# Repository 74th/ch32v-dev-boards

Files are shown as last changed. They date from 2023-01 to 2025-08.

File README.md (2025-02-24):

# CH32V Development Board

- [74th. CH32V203C8T6 ProMicro](./ch32v203-promicro/)
- [74th. CH32V003F6P6 ProMicro](./ch32v003-promicro/)
- [74th. CH32X035G8U6 ProMicro for USB PD](./ch32x035-promicro-usb-pd/)
- [74th. CH32X035G8U6 ProMicro for USB Device](./ch32x035-promicro-usb-device/)
- [74th. CH32V00xJxM6 SOIC-8 Dev Board](./ch32v00x-soic8/)
- [74th. CH32V006K8U6 Full Dev Board](./ch32v006-full/)

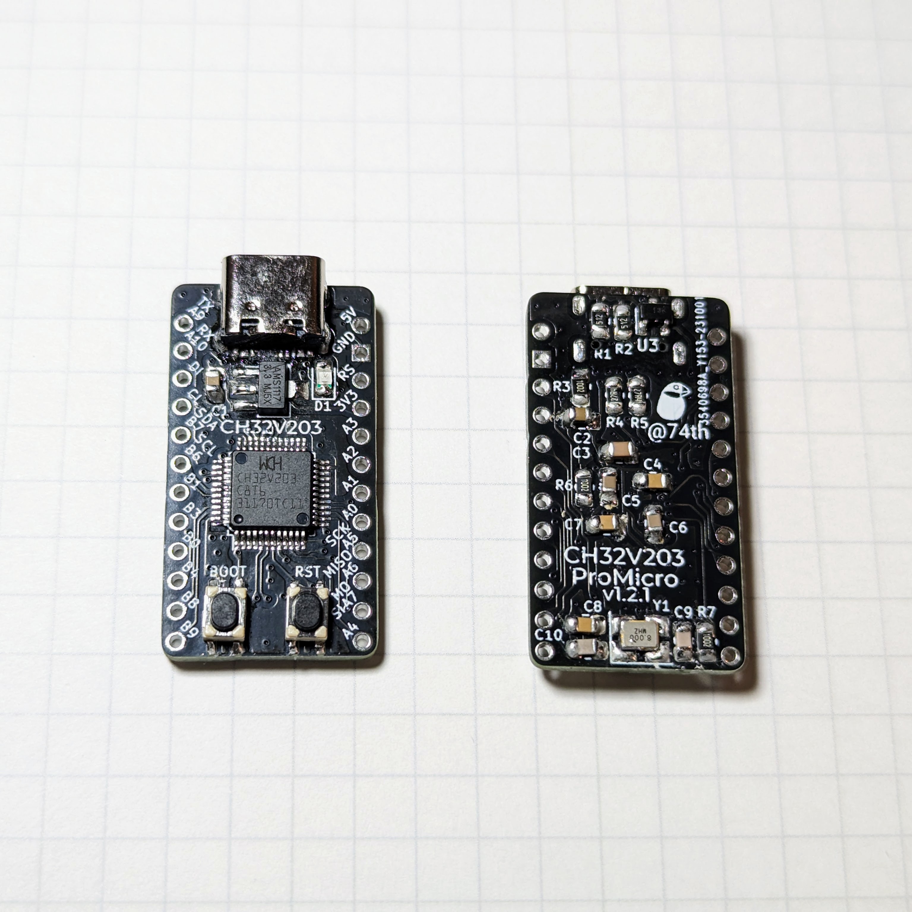
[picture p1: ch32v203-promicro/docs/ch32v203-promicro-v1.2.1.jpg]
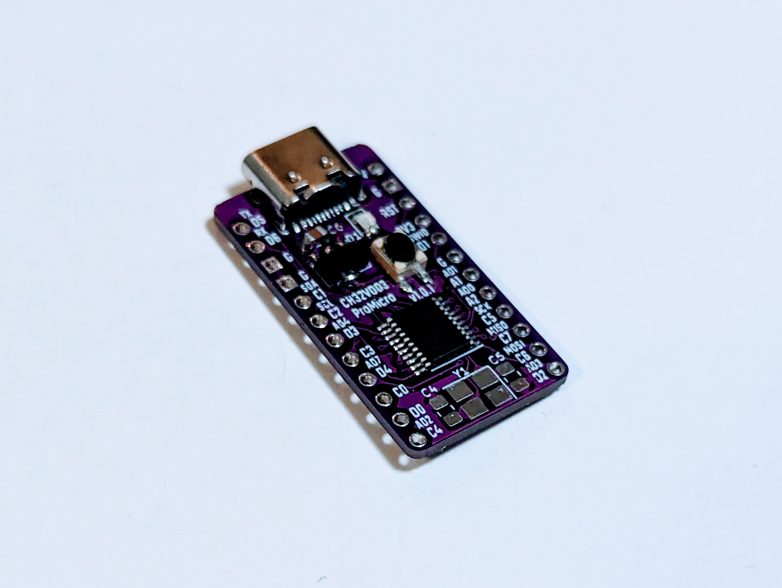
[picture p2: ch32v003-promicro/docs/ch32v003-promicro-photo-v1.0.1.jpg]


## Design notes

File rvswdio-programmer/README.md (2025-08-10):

# RVSWDIO Programmer

- Semantics [kicanvas](https://kicanvas.org/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)
- PCB [kicanvas](https://kicanvas.org/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)

firmware

https://github.com/cnlohr/rv003usb/tree/master/rvswdio_programmer

The on/off levels of the power switch pin need to be swapped.

```h
#define POWER_ON 0
#define POWER_OFF 1
```

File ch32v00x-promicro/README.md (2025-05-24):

# WCH CH32V00x ProMicro-Sized Development Board

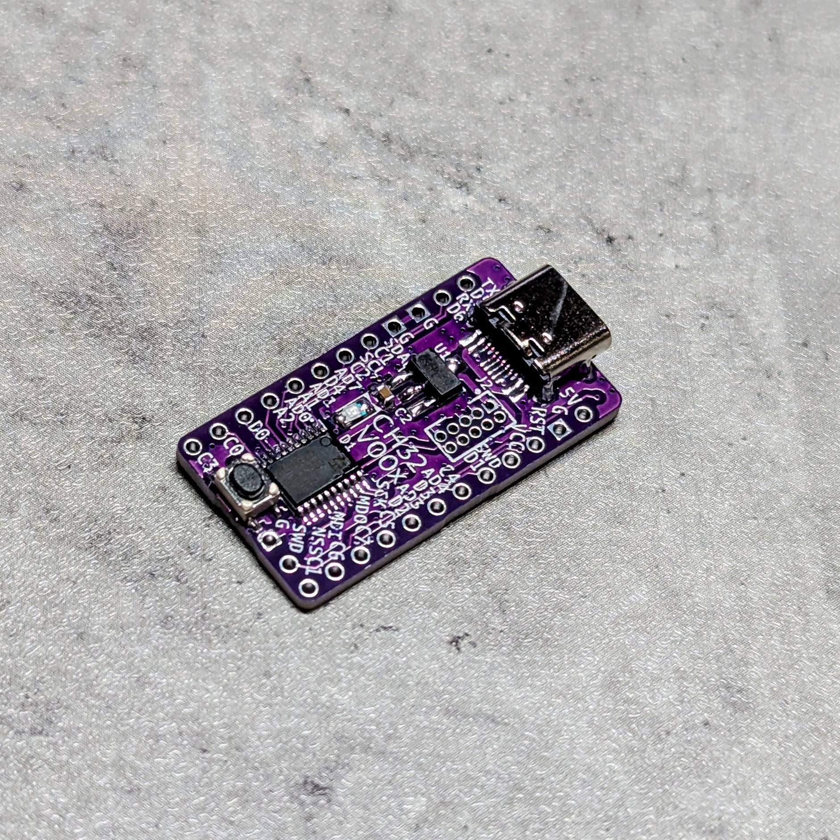
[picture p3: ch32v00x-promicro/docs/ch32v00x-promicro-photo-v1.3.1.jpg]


I forked the CH32V003 ProMicro v1.3.0 to simplify it by removing the USB wiring.

🇯🇵

CH32V003 ProMicro v1.3.0から、USBへの配線を取り除いてシンプルにするために、forkしました。

## features

- ProMicro size
  - To replicate the ProMicro, the CH32V003 lacks sufficient GPIOs, so PC1 is connected to both pin 5 (2/SDA) and pin 13 (10/A10).
- The MCU's VCC is set to 3.3V, but can be switched to 5V by connecting JP1 and removing the U2 3.3V regulator.
- The oscillator used is the MCU's built-in oscillator.

🇯🇵

- ProMicroサイズ
  - ProMicro を再現するには、CH32V003 は GPIO の数が足りないため、PC1が 5ピン（2/SDA）と13ピン（10/A10）に接続されています。
- MCU の VCC は 3.3V になっていますが、JP1 を接続し、U2 3.3V レギュレータを外すことで、5V にすることができます。
- 発振器にはMCU内蔵発振器を使います

## CH32V00x ProMicro v1.3.1

### Changes

- Added SWIO and GND ports for WCH-LinkE connection
- Remove USB Data lines

🇯🇵

- WCH-LinkE接続用にSWIO、GNDポートを追加
- USB データラインを削除

### DataSheet

- Semantics [PDF](docs/ch32v00x-promicro-semantics-v1.3.1.pdf) [kicanvas](https://kicanvas.org/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)
- PCB [kicanvas](https://kicanvas.org/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)

### Pin Out

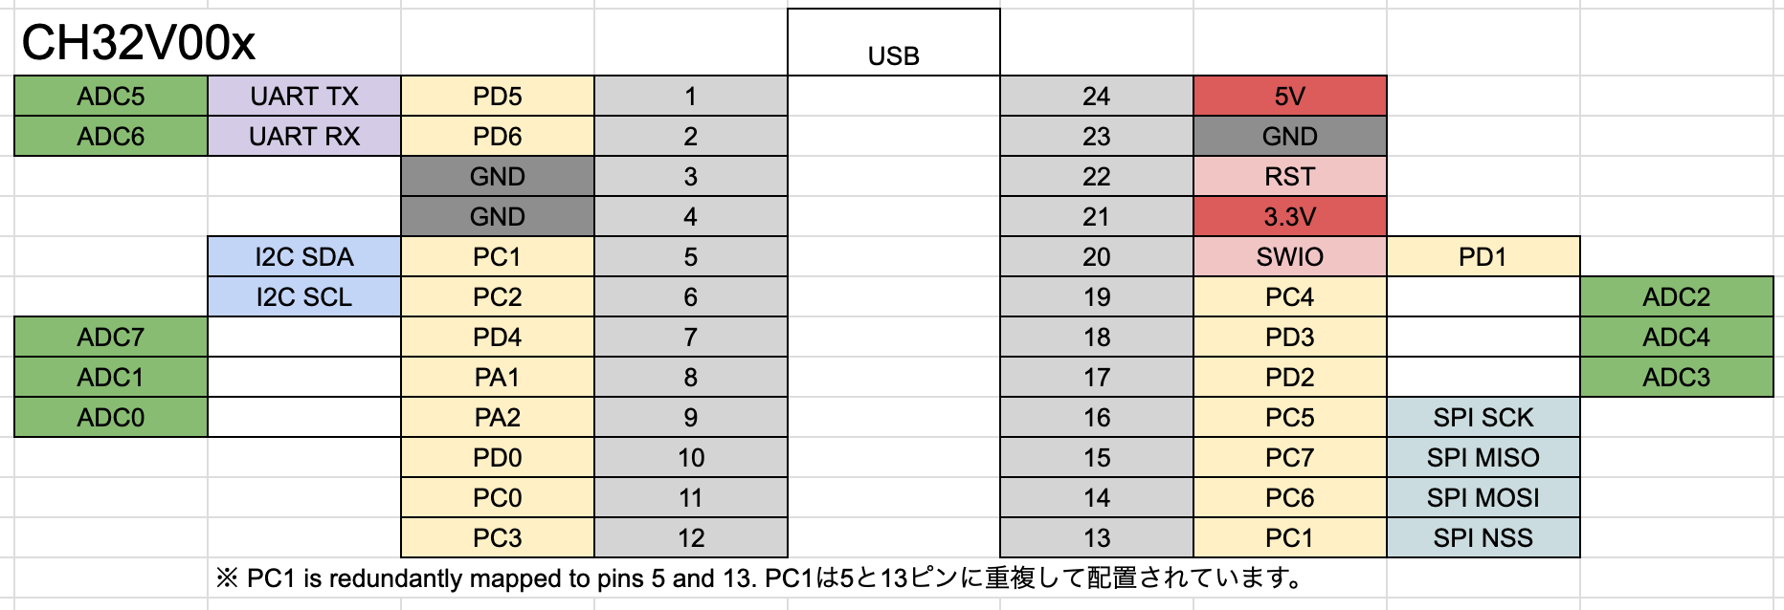
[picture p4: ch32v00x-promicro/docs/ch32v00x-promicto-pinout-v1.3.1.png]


### BOM

| Reference | Name | Quantity |
| --- | --- | --- |
| C1, C2 | Capacitor 0805 10uF | 2 |
| C4 | Capacitor 0805 100nF | 1 |
| D1 | LED 0805 Blue | 1 |
| J1 | USB Type-C Receptacle | 1 |
| J2 | Pin Header 2x5 Pitch 1.27mm | 1 |
| JP1 | Jumper SolderJumper_2_Open | 1 |
| R3, R4 | Register 0805 5.1kΩ | 2 |
| 10 | Register 0805 10kΩ | 1 |
| SW1 | Button SKRPABE010 | 1 |
| U1 | Regulator 3.3V SOT-89 AMS1117-3.3 | 1 |
| U2 | MCU TSSOP20 WCH CH32V003F4P6 | 1 |
| U3 | USB Power Protection IC CH213 SOT-23 | 1 |

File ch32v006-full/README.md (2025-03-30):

# CH32V006-full Dev Board

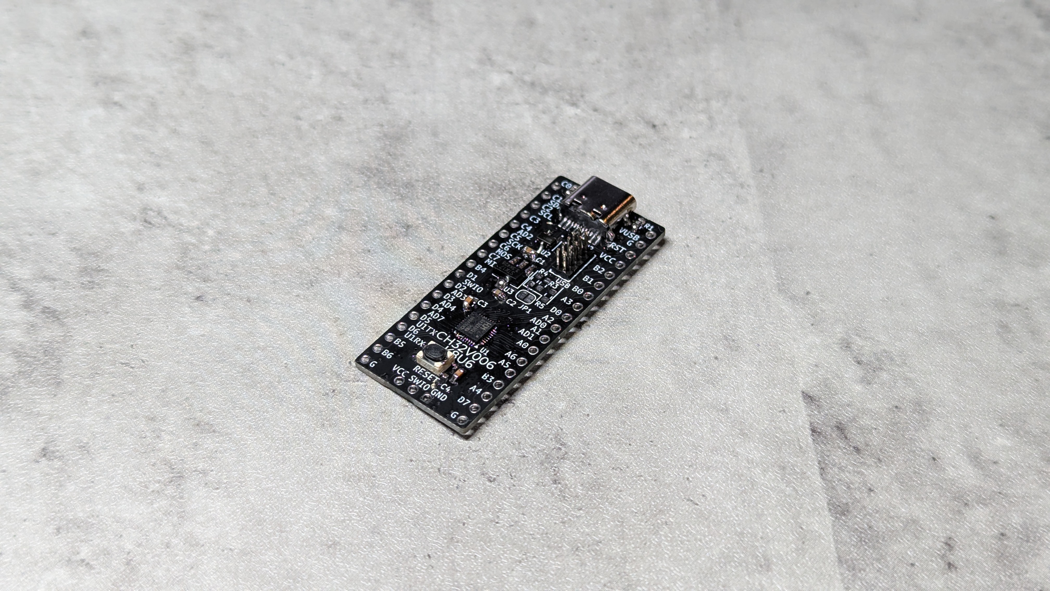
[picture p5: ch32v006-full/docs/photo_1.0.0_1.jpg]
CH32V006-full
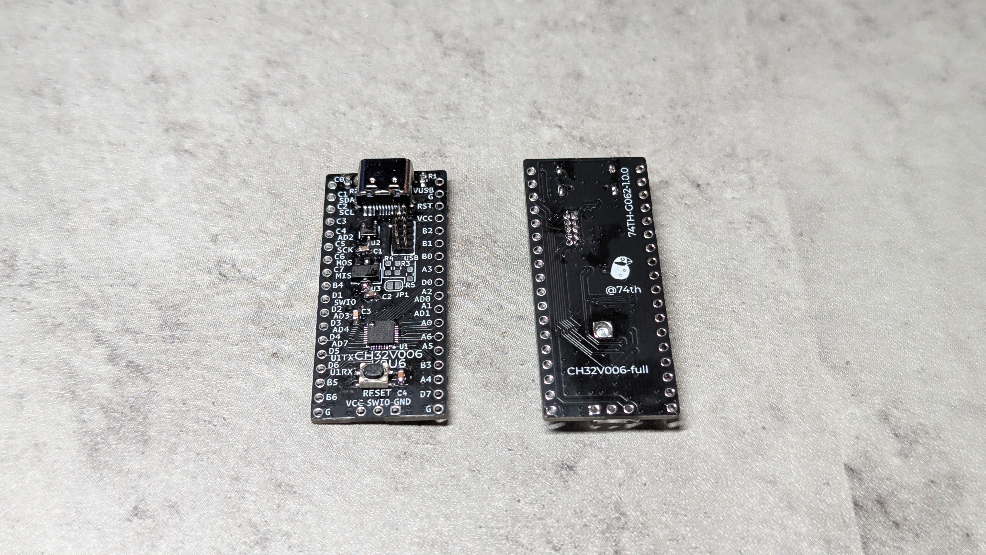
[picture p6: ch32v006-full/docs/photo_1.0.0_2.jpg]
CH32V006-full


## target mcu

- CH32V006K8U6

## 1.0.0

### PinOut

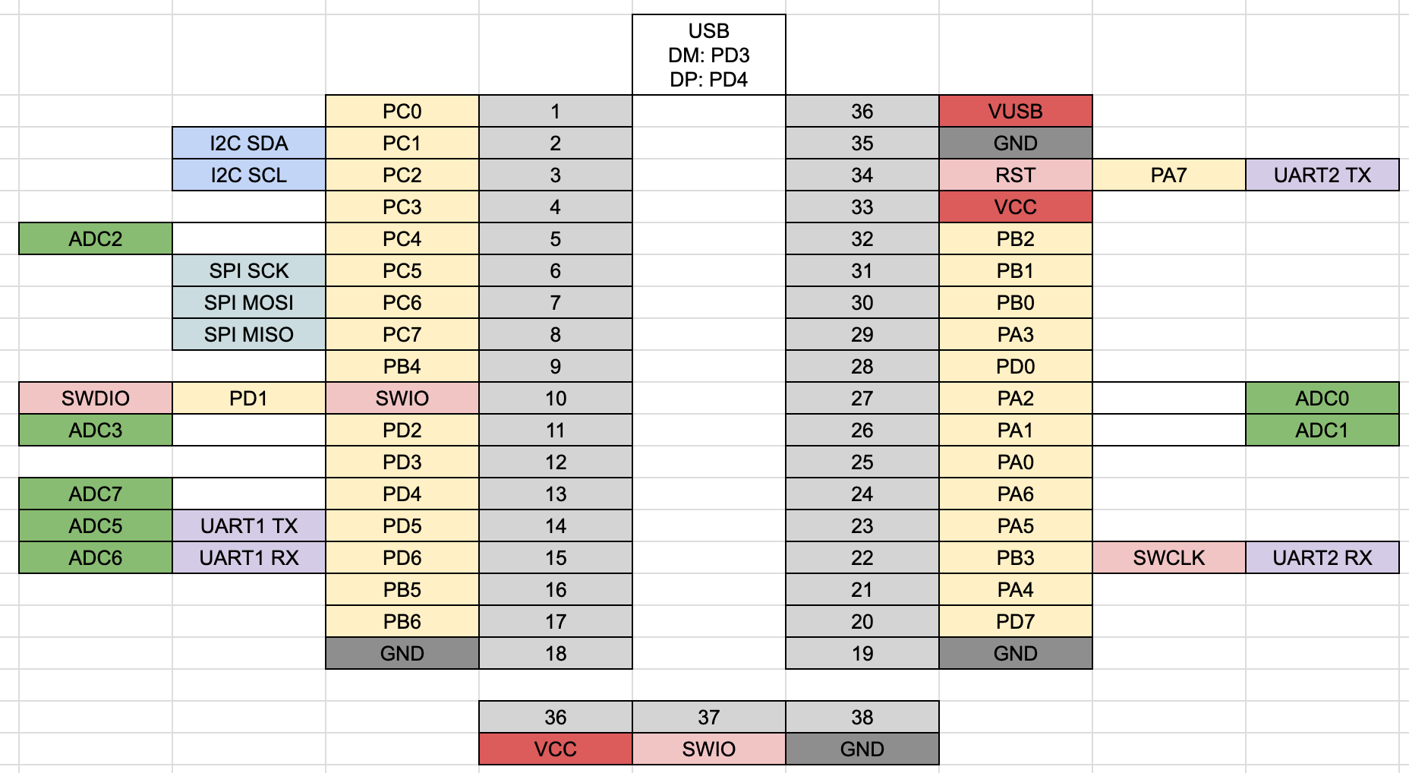
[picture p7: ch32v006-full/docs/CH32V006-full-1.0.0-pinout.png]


### BOM

| Reference | Name | Package | Quantity |
| --- | --- | --- | --- |
| C1-2 | Capacitor 10uF | SMD 0603in 1608M | 2 |
| C3-4 | Capacitor 100nF | SMD 0603in 1608M | 2 |
| J1 | USB Type-C Receptacle | | 1 |
| J2 | Box Pin Header 2x5 Pitch 1.27mm | TH | 1 |
| JP1 | Jumper Jumper_2_Open | | 1 |
| R1-2 | Register 5.1kΩ | SMD 0603in 1608M | 2 |
| R3-4 | Register 10Ω (NC) | SMD 0603in 1608M | 2 |
| R5 | Register 1.5kΩ (NC) | SMD 0603in 1608M | 1 |
| SW1 | Button SKRPABE010 | | 1 |
| U1 | MCU WCH CH32V006K8U6 | QFN32 | 1 |
| U2 | USB Power Protection IC CH213K  | SOT-23 | 1 |
| U3 | Regulator 3.3V AMS1117-3.3 | SOT-89 | 1 |

### DataSheet

- Semantics [PDF](docs/CH32V006-full-1.0.0-semantics.pdf) [kicanvas](https://kicanvas.org/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)
- PCB [kicanvas](https://kicanvas.org/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)

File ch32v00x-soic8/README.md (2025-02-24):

# CH32V00xJxM6 Dev Board

## target mcu

- CH32V003J4M6
- CH32V002J4M6

## 1.0.0

### PinOut

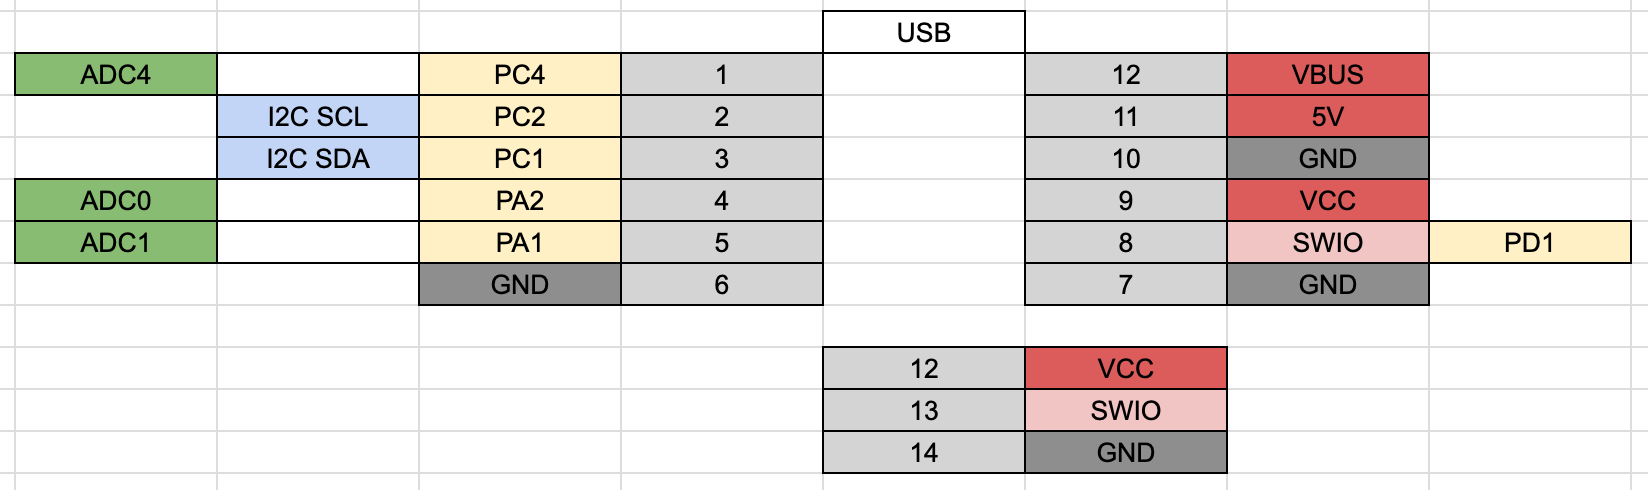
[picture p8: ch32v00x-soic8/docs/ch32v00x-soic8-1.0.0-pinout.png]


### BOM

| Reference | Name | Package | Quantity |
| --- | --- | --- | --- |
| C1-2 | Capacitor 10uF | SMD 0603in 1608M | 2 |
| C3 | Capacitor 100nF | SMD 0603in 1608M | 1 |
| J1 | USB Type-C Receptacle | | 1 |
| JP2 | Jumper Jumper_2_Open | | 1 |
| R1-2 | Register 5.1kΩ | SMD 0603in 1608M | 2 |
| U1 | MCU WCH CH32V002J4M6 | SOIC-8 | 1 |
| U2 | USB Power Protection IC CH213K | SOT-23 | 1 |
| U3 | Regulator 3.3V AMS1117-3.3 | SOT-89 | 1 |

### DataSheet

- Semantics [PDF](docs/ch32v00x-soic8-1.0.0-semantics.pdf) [kicanvas](https://kicanvas.org/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)
- PCB [kicanvas](https://kicanvas.org/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)

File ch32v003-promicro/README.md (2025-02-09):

# WCH CH32V003 ProMicro-Sized Development Board

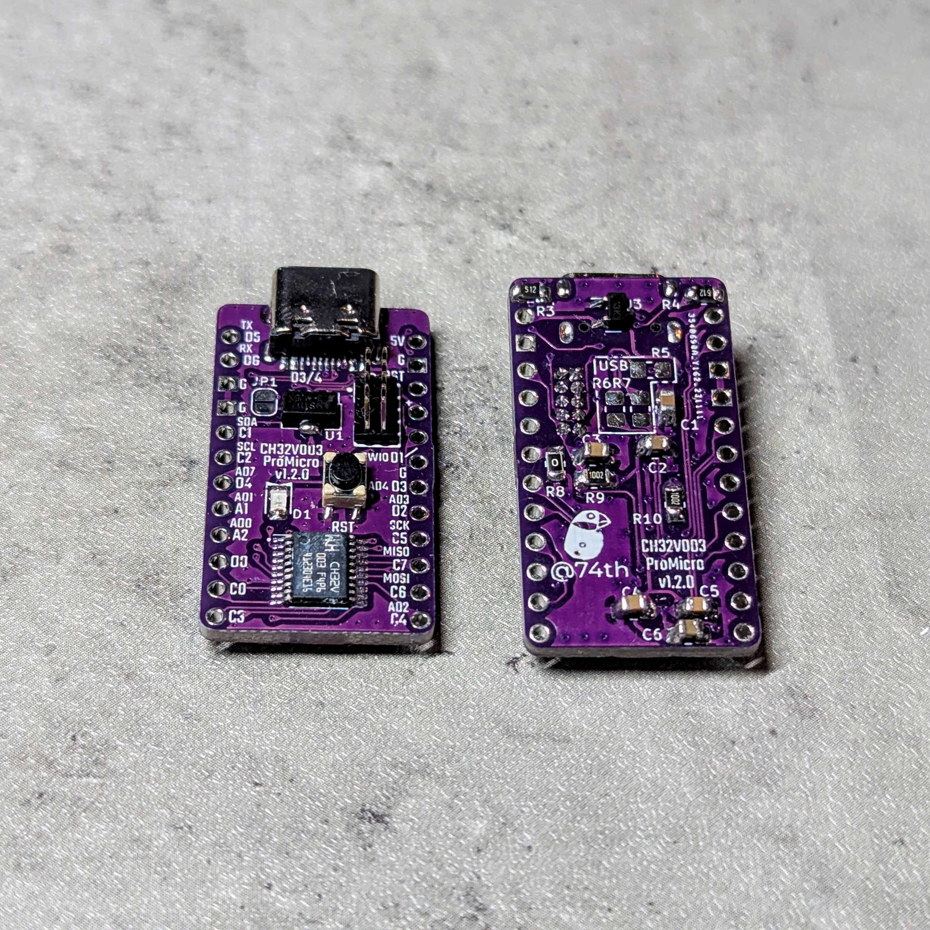
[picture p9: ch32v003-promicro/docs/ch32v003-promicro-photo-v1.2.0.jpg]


Shop(Booth, Japan): https://booth.pm/ja/items/4645948

## features

- ProMicro size
  - To emulate a ProMicro, as the CH32V003 lacks sufficient GPIOs, pin 19 (20/A2) is connected to GND via a 0-ohm resistor (R5).
- The MCU's VCC is set to 3.3V, but can be switched to 5V by connecting JP1 and removing the U2 3.3V regulator.
- v1.1.0~: The USB D+/- is pre-wired to D3 and D4 for using rv003usb. If not used, simply do not mount the damping resistors.
- The oscillator used is the MCU's built-in oscillator.

🇯🇵

- ProMicroサイズ
  - ProMicro を再現するには、CH32V003 は GPIO の数が足りないため、19 Pin（20/A2） を R5 0R で GND 接続するようにしています。
- MCU の VCC は 3.3V になっていますが、JP1 を接続し、U2 3.3V レギュレータを外すことで、5V にすることができます。
- v1.1.0~: USB D+/- は rv003usb を使う前提で、D3、D4 に配線済み。不使用の場合にはダンピング抵抗を未実装にするだけ。
- 発振器にはMCU内蔵発振器を使います

## CH32V003ProMicro v1.2.0

### Changes

- Changed power supply protection IC from CH217K to CH213K

🇯🇵

- 電源保護 IC を、CH217K から CH213K に変更

### DataSheet

- Semantics [PDF](docs/ch32v003-promicro-semantics-v1.2.0.pdf) [kicanvas](https://kicanvas.org/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)
- PCB [kicanvas](https://kicanvas.org/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)

### Pin Out

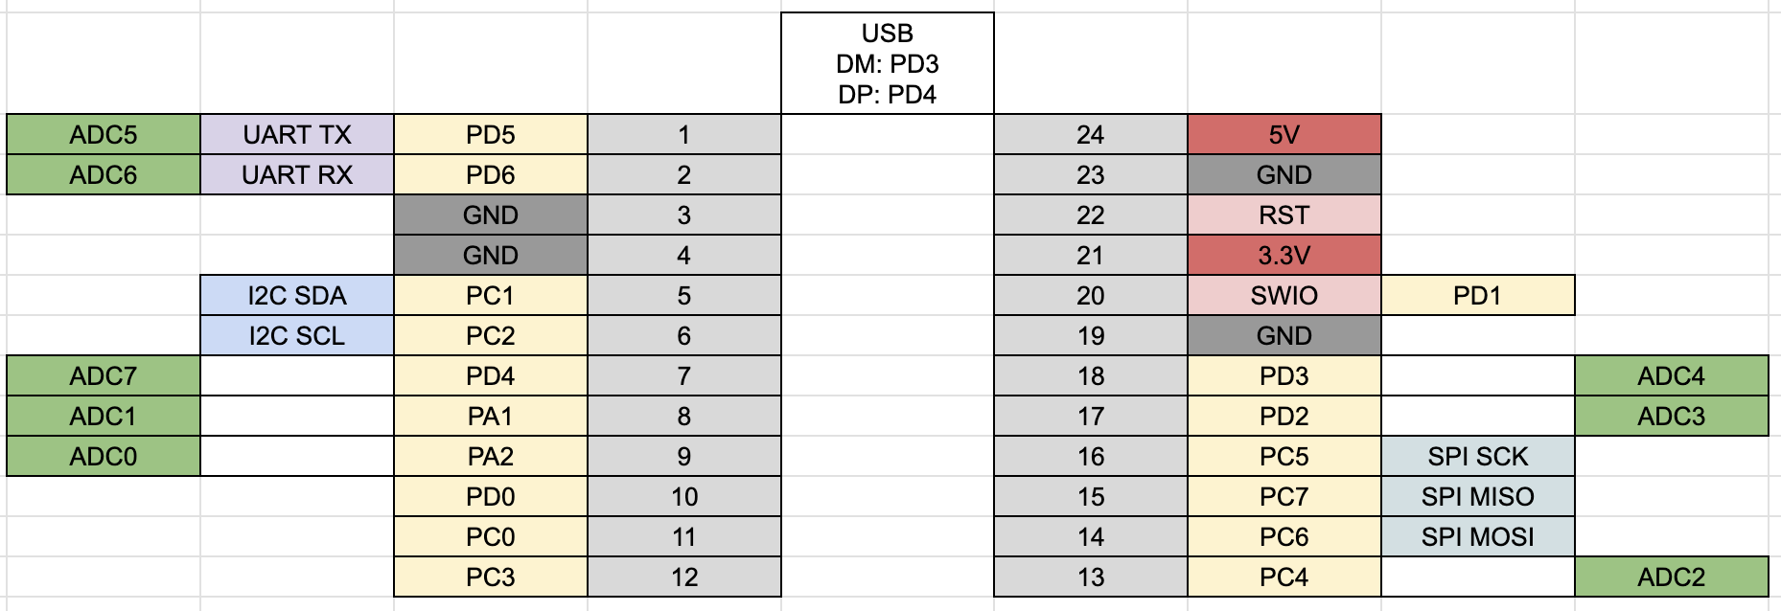
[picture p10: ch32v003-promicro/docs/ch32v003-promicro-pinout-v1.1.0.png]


### BOM

| Reference | Name | Quantity |
| --- | --- | --- |
| C1, C2 | Capacitor 0805 10uF | 2 |
| C3-C5 | Capacitor 0805 100nF | 3 |
| C6 | Capacitor 0805 1uF | 1 |
| D1 | LED 0805 Blue | 1 |
| J1 | USB Type-C Receptacle | 1 |
| J2 | Pin Header 2x5 Pitch 1.27mm | 1 |
| JP1 | Jumper SolderJumper_2_Open | 1 |
| R3, R4 | Register 0805 5.1kΩ | 2 |
| R5 | Register 0805 1.5kΩ (NC) | 1 |
| R6, R7 | Register 0805 27.4Ω (NC) | 2 |
| R8 | Register 0805 0Ω | 1 |
| R9, R10 | Register 0805 10kΩ | 2 |
| SW1 | Button SKRPABE010 | 1 |
| U1 | Regulator 3.3V SOT-89 AMS1117-3.3 | 1 |
| U2 | MCU TSSOP20 WCH CH32V003F4P6 | 1 |

## CH32V003ProMicro v1.1.0

### Changes

- Pin assignment change.
- v1.1.0~: The USB D+/- is pre-wired to D3 and D4 for using rv003usb. If not used, simply do not mount the damping resistors.
- Removed external oscillator. Assuming that the internal oscillator is used.

🇯🇵

- ピン配置変更。
- USB D+/-は rv32usb を使う前提で、D3、D4 に配線済み。不使用の場合にはダンピング抵抗を未実装にするだけ。
- 外部発振器を削除。内蔵発振器を使う前提。

### DataSheet

- Semantics [PDF](ch32v003-promicro-semantics-v1.1.0.pdf) [kicanvas](https://kicanvas.org/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)
- PCB [PDF](ch32v003-promicro-pcb-v1.1.0.pdf) [kicanvas](https://kicanvas.org/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)

### ピン配置 Pin Out



### BOM

| Reference | Name | Quantity |
| --- | --- | --- |
| C1, C2 | Capacitor 0805 10uF | 2 |
| C3-C5 | Capacitor 0805 100nF | 3 |
| C6 | Capacitor 0805 1uF | 1 |
| D1 | LED 0805 Blue | 1 |
| J1 | USB Type-C Receptacle - USB2.0_C_v3 | 1 |
| J2 | Box Pin Header 2x5 Pitch 1.27mm | 1 |
| JP1 | Jumper SolderJumper_2_Open | 1 |
| R1, R9, R10 | Register 0805 10kΩ | 3 |
| R2 | Register 0805 54-56kΩ | 1 |
| R3, R4 | Register 0805 5.1kΩ | 2 |
| R5 | Register 0805 1.5kΩ (NC) | 1 |
| R6, R7 | Register 0805 27.4Ω (NC) | 2 |
| R8 | Register 0805 0Ω | 1 |
| SW1 | Button SKRPABE010 | 1 |
| U1 | Regulator 3.3V SOT-89 AMS1117-3.3 | 1 |
| U2 | MCU TSSOP20 WCH CH32V003F4P6 | 1 |
| U3 | USB Power Protection IC SOT-23-6L CH217K | 1 |

## CH32V003ProMicro v1.0.1

### features

- 裏面には、バージョンは v1.0.0 と表記されていますが、v1.0.1 の誤りです。
- USB ソケットは 5V 電源専用であり、通信はできません。
- キットには、クリスタル及びクリスタル横のコンデンサは含まれていません。内蔵発信器を使用するため、不要です。外部発信器を使用する場合は、SMD 3225 24MHz クリスタルと、0805 22pF のコンデンサを、用意の上実装してください。
- ProMicro を再現するには、CH32V003 は GPIO の数が足りないため、19 Pin を R5 0R で GND 接続するようにしています。
- MCU の VCC は 3.3V になっていますが、JP1 を接続し、U2 3.3V レギュレータを外すことで、5V にすることができます。

### Data Sheet

- Semantics [PDF](ch32v003-promicro-semantics-v1.0.1.pdf) [kicanvas](https://kicanvas.org/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)
- PCB [PDF](ch32v003-promicro-pcb-v1.0.1.pdf) [kicanvas](https://kicanvas.org/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)

### ピン配置 Pin Out

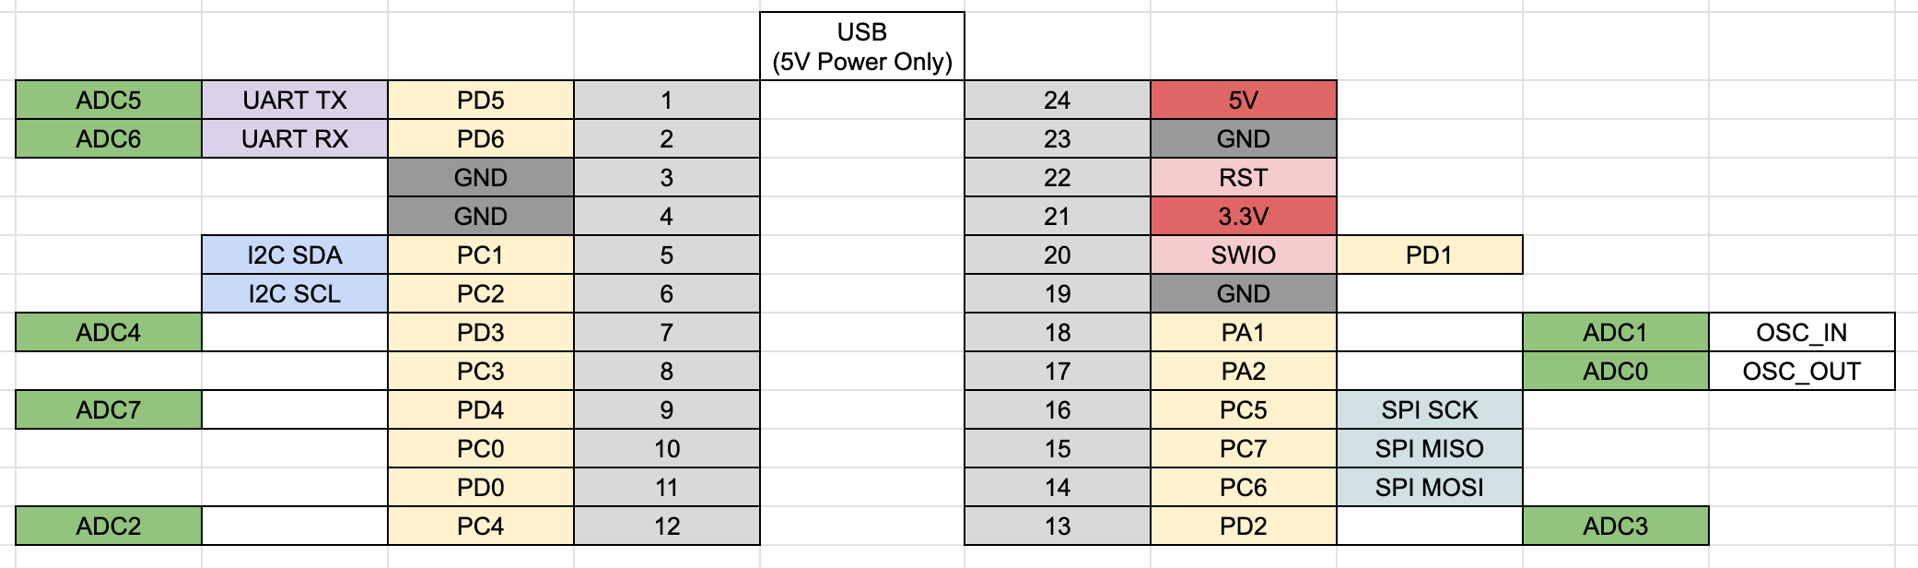
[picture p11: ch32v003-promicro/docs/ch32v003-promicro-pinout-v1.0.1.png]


### 部品表 Parts List

| Reference | Parts |
| --- | --- |
| R1 | 0805 Register 10k |
| R2,R3 | 0805 Register 5.1kR |
| R4 | 0805 Register 200R or 1kR |
| R5 | 0805 Register 0R |
| C1,C2,C3  | 0805 Capacitor 100nF |
| C4,C5 | 0805 Capacitor 22p (NC) |
| C6 | 0805 Capacitor 10uF |
| C7 | 0805 Capacitor 2.2uF |
| D1 | 0805 LED |
| U1 | TSSOP20 CH32V003F4P6 |
| U2 | SOT89 3.3V Regulator AMS1117-3.3 |
| Y1 | 3225 4Pin Crystal 24MHz (NC) |
| J1 | SMD USB-C 2.0 Socket |
| SW1 | SKRPABE010 SMD Push Switch |

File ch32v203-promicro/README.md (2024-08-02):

# RISC-V MCU CH32V203 ProMicro Sized Dev Board



The contents of this page include the KiCad files in this repository, as well as kits sold by Booth and finished products sold by Switch Science.

Please check [Documents](#documents) for schematics, bill of materials, pin maps, etc.

🇯🇵

本ページのコンテンツは、本リポジトリの KiCad ファイル、及び Booth 販売品のキット、スイッチサイエンスでの完成品販売の内容が含まれています。

回路図、部品表、ピンマップ等については、[Documents](#documents)を確認ください。

- [CH32V203 での開発方法について](#CH32V203-の開発方法)
- キット販売ページ(BOOTH) https://74th.booth.pm/items/4492691

# main features

- Uses RISC-V CH32V203C8T6, resembling STM32.
- Pin configuration with functions similar to ProMicro (UART, I2C, SPI, ADC).
- By pressing the BOOT button while pressing RESET, it enters a mode that allows writing via USB.
- USB1DM/DP already wired to USB Port(USB2 not wired).

🇯🇵

- STM32 に似せた RISC-V CH32V203C8T6 を使用
- ProMicro に近い機能のピン配置（UART、I2C、SPI、ADC）
- BOOT ボタンを押しながら RESET を押すことで、USB で書き込みできるモードに入る
- USB には、USB1DM/DP を配線済み

# How to use 使い方

- There is a BOOT button, and by pressing the BOOT button while holding down RESET(RST), the mode is set to write via USB.
- GND on the left side is changed to SWDIO and SWCLK. Connect WCH-Link to GND, SWDIO, and SWCLK.

🇯🇵

- BOOT ボタンがあり、RESET を押しながら BOOT ボタンを押すことで、USB 経由で書き込めるモードになります。
- 左側の GND を、SWDIO、SWCLK に変更しています。こちらから WCH-Link を用いることで書き込みができるようになります。WCH-Link と GND、SWDIO、SWCLK を接続してください。

# Documents

## CH32V203Micro v1.2.1-2

- v1.2.2 と v1.2.1 の違いは利用した KiCad バージョンの更新と、若干のフットプリントの修正で、部品表、機能に違いはありません。

- semantics [PDF](./docs/ch32v203-promicro-v1.2.1.pdf) [Kicanvas](https://kicanvas.org/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)
- PCB
  - 1.2.1 [Kicanvas](https://kicanvas.org/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)
  - 1.2.2 [Kicanvas](https://kicanvas.org/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)

### Pin Map

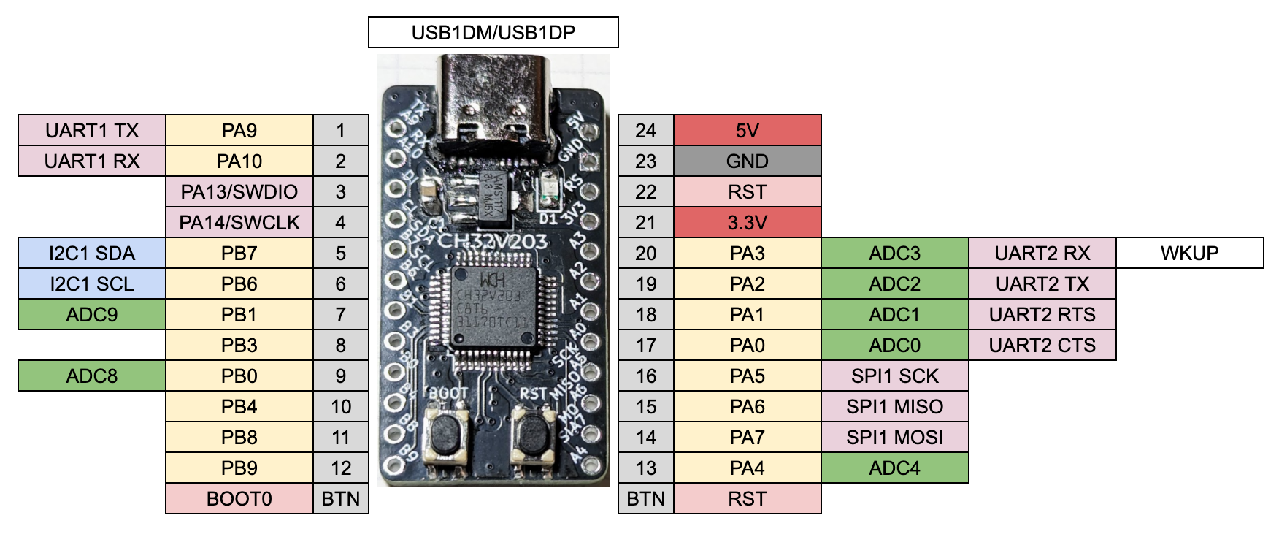
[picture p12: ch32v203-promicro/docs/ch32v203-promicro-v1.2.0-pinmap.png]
Pin Map


### new feature

- Anticipating the use of the USB write function, the following changes have been made:
  - The X32Micro v1.2.0 added an SWD 10-pin port, but it was removed in the CH32V203Micro v1.2.1.
  - The X32Micro v1.2.0 removed the BOOT button, but it was re-added in the CH32V203Micro v1.2.1.
  - The X32Micro v1.2.0 added through-holes for BOOT0 and BOOT1, but these were removed. This is because basically only BOOT0 is used.
- Differences from X32Micro v1.1.0:
  - Added CH213K as a USB power protection IC.
  - Added damping resistors to USB DM/DP.
  - Omitted the low-power crystal oscillator (internal RC clock can be used).
  - Pin configuration change.

🇯🇵

- USB で書き込みできる機能を利用する想定で、以下の変更を行いました。
  - X32Micro v1.2.0 では SWD 10 ピンポートを追加しましたが、CH32V203Micro v1.2.1 ではを削除しました。
  - X32Micro v1.2.0 では BOOT ボタンを削除しましたが、CH32V203Micro v1.2.1 では、BOOT ボタンを再度追加しました。
  - X32Micro v1.2.0 では BOOT0、BOOT1 のスルーホールを追加しましたが、削除しました。BOOT0 しか基本的に利用されないためです。
- X32Micro v1.1.0 からの差分
  - USB 電源保護 IC として CH213K を追加
  - USB DM/DP にダンピング抵抗を追加
  - Low Power 用水晶発振器を省略（内蔵 RC クロックが使用可能）
  - ピン配置変更

### 部品表 Parts List

| Reference  | Name | Quantity |
| --- | --- | --- |
| C1, C2 | Capacitor 0805 10uF | 2 |
| C3 | Capacitor 0805 1uF | 1 |
| C4-C8 | Capacitor 0805 100nF | 5 |
| C9, C10 | Capacitor 0805 10-22pF | 2 |
| D1 | LED 0805 BLUE | 1 |
| J1 | USB Type-C Receptacle | 1 |
| R1, R2 | Register 0805 5.1kΩ | 2 |
| R3, R6, R7 | Register 0805 10kΩ | 3 |
| R4, R5 | Register 0805 27Ω | 2 |
| SW1, SW2 | Button SKRPABE010 | 2 |
| U1 | Regulator 3.3V SOT-89 AMS1117-3.3 | 1 |
| U2 | MCU LQFP48 WCH CH32V203C8T6 | 1 |
| U3 | USB Power Protection IC SOT-23 CH213K | 1 |
| Y1 | Crystal 3225 8MHz | 1 |

## X32Micro v1.2.0

Please see [https://github.com/74th/x32promicro?tab=readme-ov-file#x32micro-v120](https://github.com/74th/x32promicro?tab=readme-ov-file#x32micro-v120).

## X32Micro v1.1.0

### 部品表 Parts List

| Reference | Parts | Qty |
| --- | --- | --- |
| C1-C3, C6 | 0805 Capacitor 100n | 4 |
| C4 | 0805 Capacitor 10u | 1 |
| C5 | 0805 Capacitor 2.2u | 1 |
| C7, C8 | 0805 Capacitor 12p | 2 |
| C9, C10 | 0805 Capacitor 22p | 2 |
| R1 | 0805 Resister 200 | 1 |
| R2 | NC or 0805 Resister 10k for BOOT0 Pull Up | 1 |
| R8 | NC or 0805 Resister 10k for BOOT0 Pull Down | 1 |
| R6-R7 | 0805 Resister 10k | 2 |
| R3 | 0805 Resister 0 R | 1 |
| R4, R5 | 0805 Resister 5.1k | 2 |
| D1 | 0805 LED | 1 |
| J1 | USB2.0 Socket | 1 |
| JP1 | Jumper BOOT SW Pull Up / Down | 1 |
| SW1, SW2  | SW Push | 2 |
| U1 | MCU STM32V103C8T6 | 1 |
| U2 | SOT-89 Regulator AMS1117-3.3 | 1 |
| Y1 | 3215 Oscillator 32.768k | 1 |
| Y2 | 3225 Oscillator 8M | 1 |

- CH32V203 など BOOT0 を Pull Up し、BOOT スイッチで GND に繋ぎたい場合
  - R2 を実装してください
  - R8 は未実装 NC にしてください
  - JP1 の中央のランドを △ マークにジャンパしてください
- STM32F103 など BOOT0 を Pull Down し、BOOT スイッチで 3V3 に繋ぎたい場合
  - R2 は未実装 NC にしてください
  - R8 を実装してください
  - JP1 の中央のランドを + マークにジャンパしてください

## CH32V203Micro v1.0.0

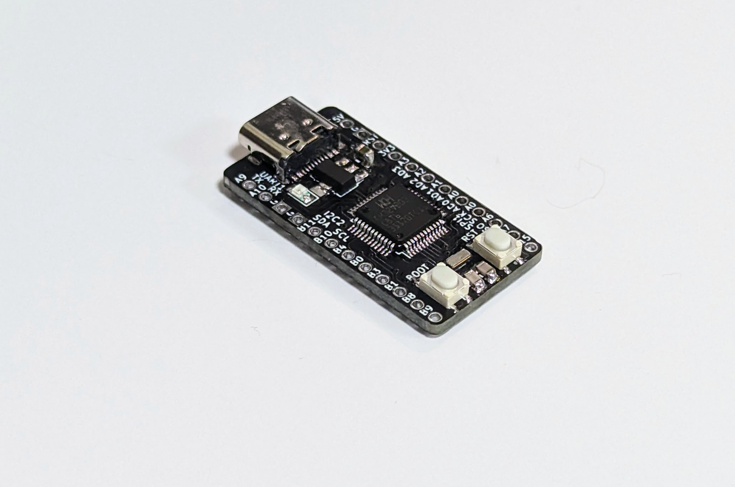
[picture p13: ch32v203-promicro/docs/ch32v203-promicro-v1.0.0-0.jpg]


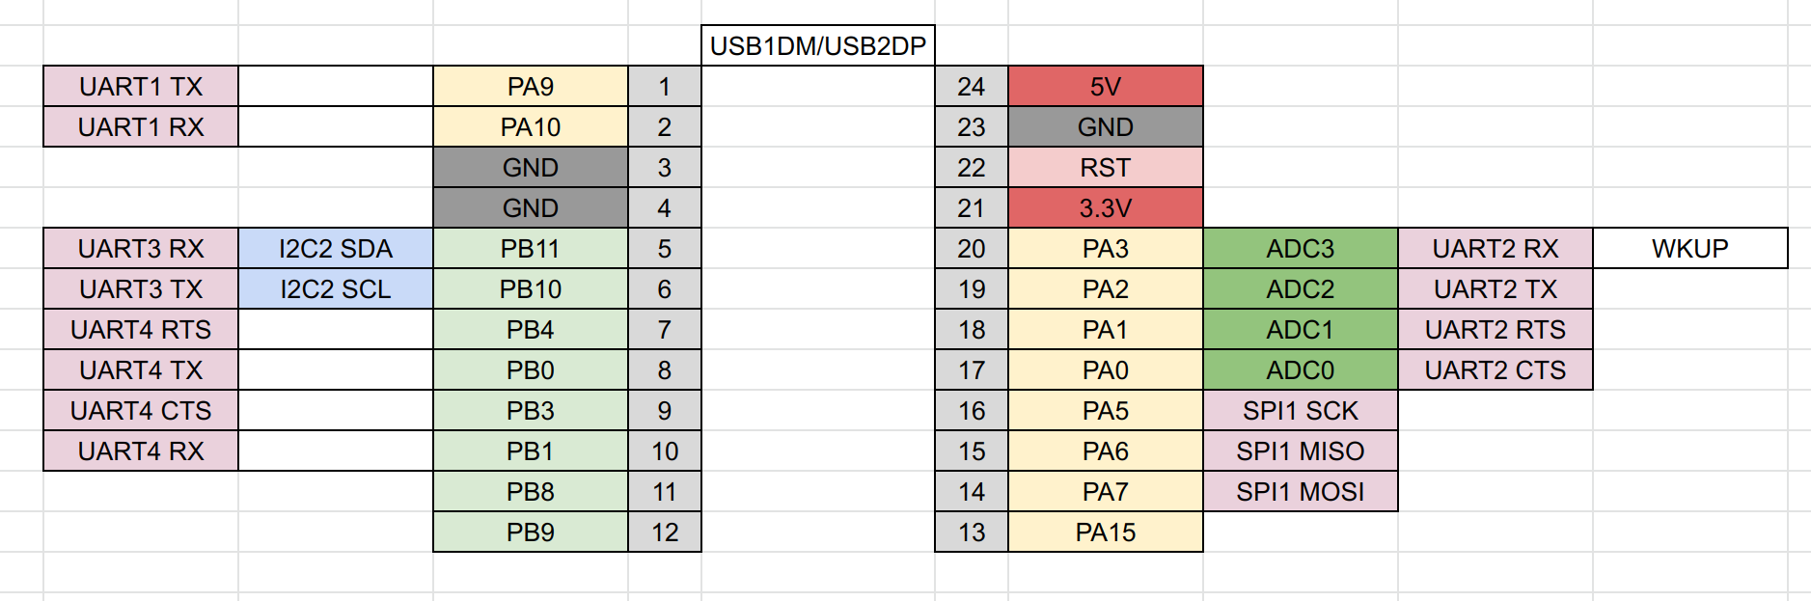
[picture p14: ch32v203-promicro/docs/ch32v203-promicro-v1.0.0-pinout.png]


- BOOTH 販売ページ
- 回路図 Semantics [docs/ch32v203-promicro-v1.0.0-semantics.pdf](docs/ch32v203-promicro-v1.0.0-semantics.pdf)
- PCB [docs/ch32v203-promicro-v1.0.0-pcb.pdf](docs/ch32v203-promicro-v1.0.0-pcb.pdf)

### 部品表 Parts List

| Reference | Parts | num |
| --- | --- | --- |
| C1-C3,C6  | 0805 Capacitor 100nF | 4 |
| C4 | 0805 Capacitor 10uF | 1 |
| C5 | 0805 Capacitor 2.2uF | 1 |
| C7,C8 | 0805 Capacitor 12pF | 2 |
| C9,C10 | 0805 Capacitor 22pF | 2 |
| D1 | 0805 LED | 1 |
| J1 | USB Type-C Socket | 1 |
| J2 | PinHeader | 1 |
| J3 | PinHeader | 1 |
| R1 | 0805 Register 200R | 1 |
| R2,R6,R7  | 0805 Register 10kR | 3 |
| R3 | 0805 Register 0R | 1 |
| R4,R5 | 0805 Register 5.1k | 2 |
| SW1 | SW Push | 2 |
| U1 | MCU CH32V203CxT6 | 1 |
| U2 | SOT-89 3.3V Regulator AMS1117-3.3 | 1 |
| Y1 | 3215 Oscillator 32.768kHz | 1 |
| Y2 | 3225 Oscillator 8MB | 1 |

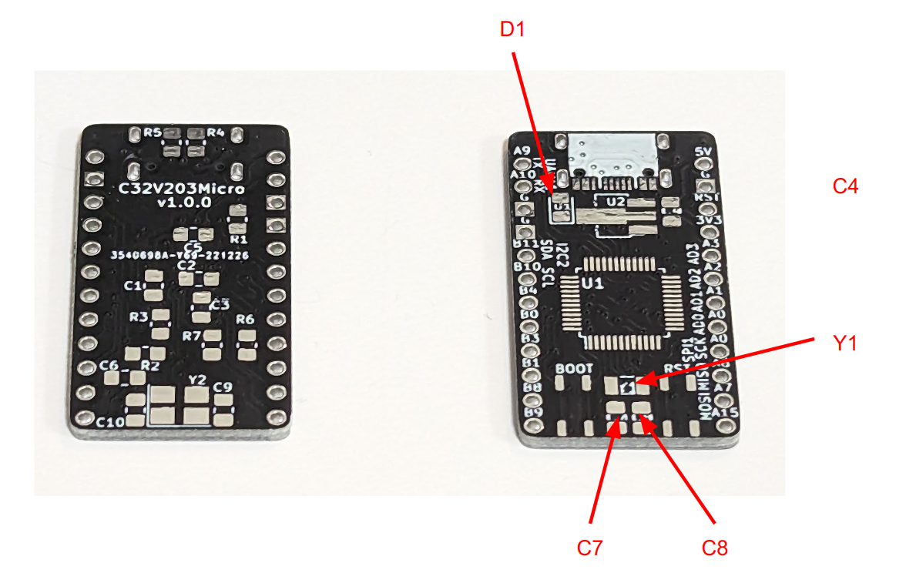
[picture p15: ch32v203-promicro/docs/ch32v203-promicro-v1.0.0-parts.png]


# CH32V203 の開発方法

## CH32V203 のファームウェアの書き込み方法

### 1. USB で書き込み場合

BOOT を押しながら、RESET を押すと、USB で書き込みを受け付けるモードになります。このモード中では、以下のソフトウェアを用いて書き込みが可能です。

- WCHISP Tool(公式) : https://www.wch-ic.com/downloads/WCHISPTool_Setup_exe.html
  - GUI で操作するツール
  - Windows のみ
- wchisp(ch32-rs) : https://github.com/ch32-rs/wchisp
  - CLI ツール

私 74th としては、wchisp が、Linux でも動作するため、便利でお勧めです。以下のようにして、書き込みます。

```
wchisp flash release/ch32v203c8t6.elf
```

### 2. WCH-Link を用いる場合

WCH-Link と SWDIO、SWCLK を接続してください。

WCH-Link を用いる場合の書き込みソフトウェアとして、以下があります。

- WCH-LinkUtility(公式) : https://www.wch.cn/downloads/WCH-LinkUtility_ZIP.html
  - GUI で操作するツール
  - Windows のみ
- minichlink(ch32v003fun) : https://github.com/cnlohr/ch32v003fun/tree/master/minichlink
  - CLI ツール
- wlink(ch32-rs) : https://github.com/ch32-rs/wlink
  - CLI ツール
- OpenOCD(WCH によるフォーク): MounRiverStudio に含まれる http://www.mounriver.com/download
  - CLI ツール

74th としては、wlink が、Linux でも動作するため、便利でお勧めです。

```
wlink flash release/ch32v203c8t6.elf
```

## CH32V203 の開発環境

PlatformIO(VS Code)を使った開発の方法を記事にしています

> WCH の RISC-V マイコン CH32V を公式 SDK を使って、VS Code の PlatformIO で開発する - @74th の制作ログ
>
> https://74th.hateblo.jp/entry/ch32v-platformio

CH32V203 の開発フレームワークとして以下が利用可能です。

- 公式 SDK: https://github.com/openwch/ch32v20x/tree/main/C%2B%2B/Use%20MRS%20Create%20C%2B%2B%20project-example/CH32V203C8T6%2B%2B
  - C/C++
  - STM32 の古い SDK 似
- ch32-rs: https://github.com/ch32-rs/ch32-rs
  - Rust のペリフェラルアクセスクレート
- WCH 提供 Arduino: https://github.com/openwch/arduino_core_ch32

開発環境としては、以下が利用できます。

- MounRiverStudio(公式): http://www.mounriver.com/download
  - 公式 SDK を利用
  - Windows、Linux のみ
- PlatformIO(コミュニティメンテ) : https://github.com/Community-PIO-CH32V/platform-ch32v
  - 公式 SDK を利用
  - MounRiverStudio に含まれる GNU ライセンスの gcc、OpenOCD 等を取り込んでいる
  - gcc、OpenOCD は x64 のみ（ARM CPU では動作不可）
- Rust(ch32v-rs 利用)
- Arduino IDE: https://github.com/openwch/arduino_core_ch32
- 公式 SDK 用 Makefile テンプレート: https://github.com/cjacker/ch32v_evt_makefile_gcc_project_template

74th としては PlatformIO が、環境構築がお手軽でお勧めです。ただし、AMD64 CPU でないと動作しません。

CH32V203 は、RV32IMAC に独自拡張命令を含んだ RV32IMACXW という命令セットを使っています。そのため、公式が提供する GCC でないと正常にコンパイルできないことがあります。

## 開発方法についてのブログ記事等情報

### 74th のブログ記事

- WCH の RISC-V マイコン CH32V を公式 SDK を使って、VS Code の PlatformIO で開発する https://74th.hateblo.jp/entry/ch32v-platformio
- WCH の RISC-V MCU CH32V203 を Rust で L チカする https://74th.hateblo.jp/entry/2022/12/22/223956

### その他記事

- オープンソースツールチェインでの CH32V の開発方法（英語） https://github.com/cjacker/opensource-toolchain-ch32v
- VSCode+PlatformIO で RISC-V CH32V203 マイコンの開発環境を構築 https://zenn.dev/usagi1975/articles/2023-09-30-0002_ch32v-platformio

### 公式ドキュメント

- データシート https://www.wch-ic.com/downloads/CH32V20x_30xDS0_PDF.html
- リファレンスマニュアル https://www.wch-ic.com/downloads/CH32FV2x_V3xRM_PDF.html
- C/C++ SDK https://github.com/openwch/ch32v20x/tree/main/C%2B%2B/Use%20MRS%20Create%20C%2B%2B%20project-example/CH32V203C8T6%2B%2B

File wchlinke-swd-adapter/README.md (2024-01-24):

# WCH-LinkE SWD Adapter

WCH-LinkE をハーフピッチ SWD UART 付きインターフェイスに変換するアダプタです。VCC から 3.3V 取り出されます。

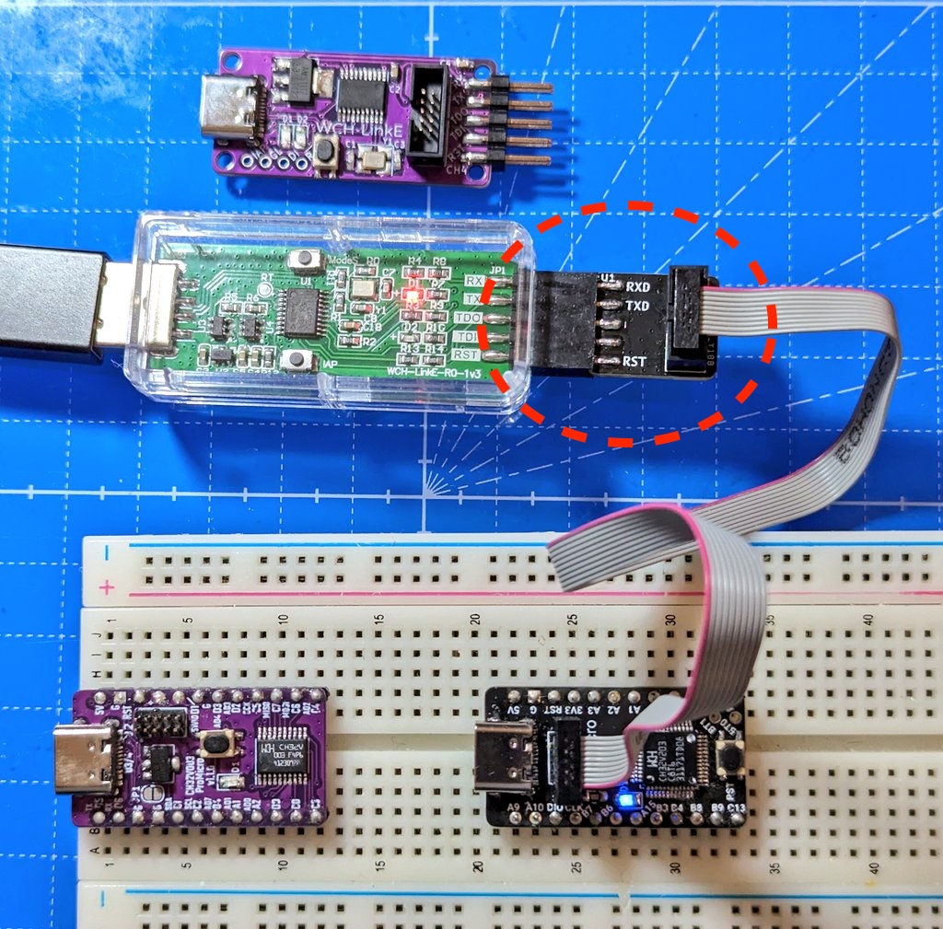
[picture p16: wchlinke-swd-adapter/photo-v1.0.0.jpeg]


74th の CH32V003 等の開発ボードにはこのポートが付いています。

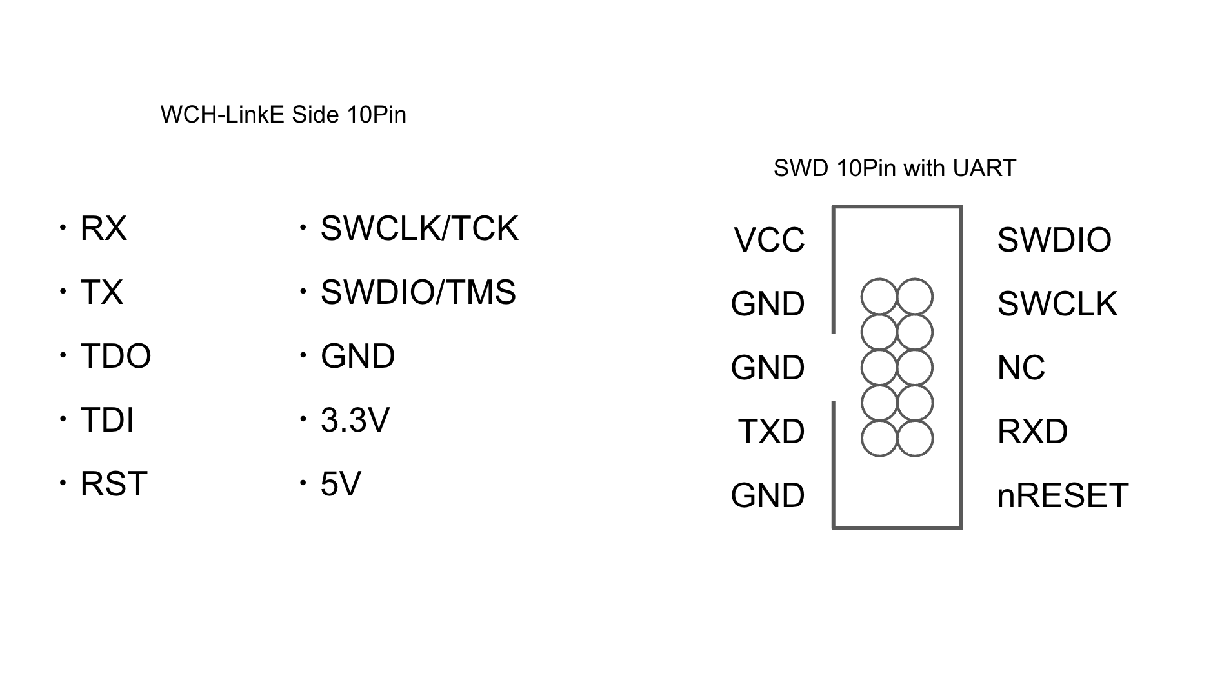
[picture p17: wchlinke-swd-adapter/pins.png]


## 従来の SWD ポートの変更点

- VCC は本来相手先デバイスが電源オンかどうかを判定する入力端子ですが、相手先デバイスを起動できると便利なため、3.3V 出力端子に変更しています。
- 本来 SWD には UART の仕様はありませんが、Arduino UNO R4 の SWD ポートに倣って UART を追加しています。

## documents

### v1.0.0

- semantics [PDF](./wchlinke-swd-adapter-v1.0.0.pdf) [Kicanvas](https://kicanvas.org/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)
- PCB [Kicanvas](https://kicanvas.org/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)

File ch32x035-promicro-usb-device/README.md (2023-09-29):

# CH32X035 for USB-Device ProMicro

## v1.0.0

### BOM

| Reference | Name | Quantity |
| --- | --- | --- |
| C1, C2 | Capacitor 0603 10uF | 2 |
| C3 | Capacitor 0603 1uF | 1 |
| C4 | Capacitor 0603 100nF | 1 |
| D1 | LED 0805 BLUE | 1 |
| J1 | USB Type-C Receptacle | 1 |
| J2 | Box Pin Header 2x5 Pitch 1.27mm | 1 |
| JP1 | Jumper Jumper_2_Open | 1 |
| R1, R2 | Register 0603 5.1kΩ | 2 |
| R3 | Register 0603 100kΩ | 1 |
| R4 | Register 0603 1.5kΩ | 1 |
| R5, R8 | Register 0603 10kΩ | 2 |
| R6, R7 | Register 0603 27Ω | 2 |
| SW1 | Button SKRPABE010 | 1 |
| U1 | Regulator 3.3V SOT-89 AMS1117-3.3 | 1 |
| U2 | MCU QFN28 WCH CH32X035G8U6 | 1 |
| U3 | USB Power Protection IC SOT-23-6L CH217K | 1 |

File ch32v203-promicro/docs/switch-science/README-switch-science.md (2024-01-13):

## 製品の概要

WCH 社が提供する RISC-V MCU の CH32V203 を使った ProMicro サイズのマイコン開発ボードです。
CH32V203 は低価格ながら USB デバイス機能を持っています。
ファームウェアの書き換えには、USB 経由で行う機能があり、別途ハードウェアは不要です。

## 特徴

- RISC-V MCU CH32V203 使用。
- UART、I2C、SPI は SparkFun ProMicro と同様のピン配置。
- BOOT ボタンを押しながら RESET を押すと、USB 経由で書き換え可能なモードに。
- デバッガ WCH-Link を使うための、SWDIO、SWCLK ポートを左側 GND の代わりに配置ずみ。
- Arduino サポートあり https://github.com/openwch/arduino_core_ch32

## 仕様

- MCU: WCH CH32V203
- サイズ: 35x18x6mm（USB コネクタ含む）
- ボタン: リセット、BOOT0 制御ボタン
- その他: 外部発振器搭載済み、低電力発振器非搭載
- ピン配置図



## ファームウェアの書き換え方法

PC に USB で接続し、BOOT ボタンを押しながら RST を押すと、USB が認識します。以下のツールで書き換え可能です。

- https://github.com/ch32-rs/wchisp
- https://www.wch-ic.com/downloads/WCHISPTool_Setup_exe.html

※ Arduino 環境はデバッガ WCH-LinkE を使う前提になっているため、ファームウェア作成後、上記ツールでの書き込みが必要です。
※ サポートページも参照ください。

## 内容物

- 1x 74th. CH32V203 ProMicro Like

## 資料

- 回路図 https://github.com/74th/ch32v-dev-boards/blob/main/ch32v203-promicro/docs/ch32v203-promicro-v1.2.1.pdf
- サポートページ https://github.com/74th/ch32v-dev-boards/tree/main/ch32v203-promicro

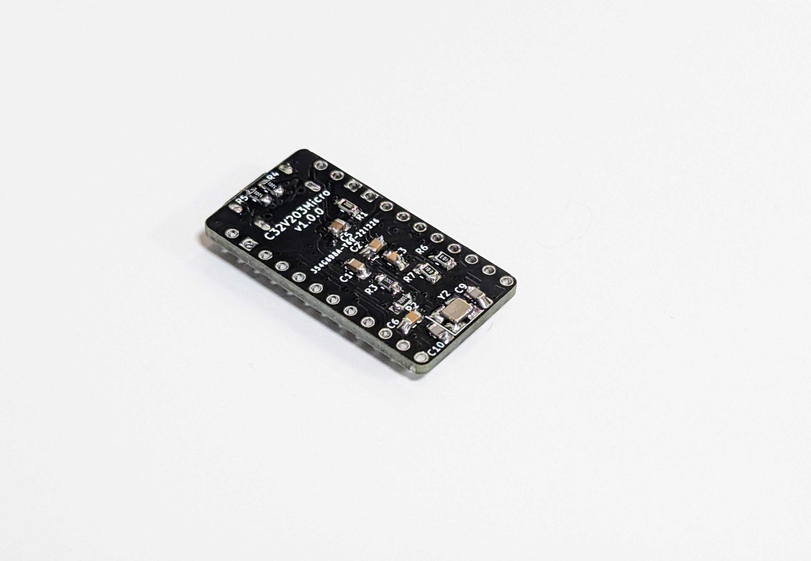
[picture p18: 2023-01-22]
ch32v203-promicro/docs/ch32v203-promicro-v1.0.0-1.jpg

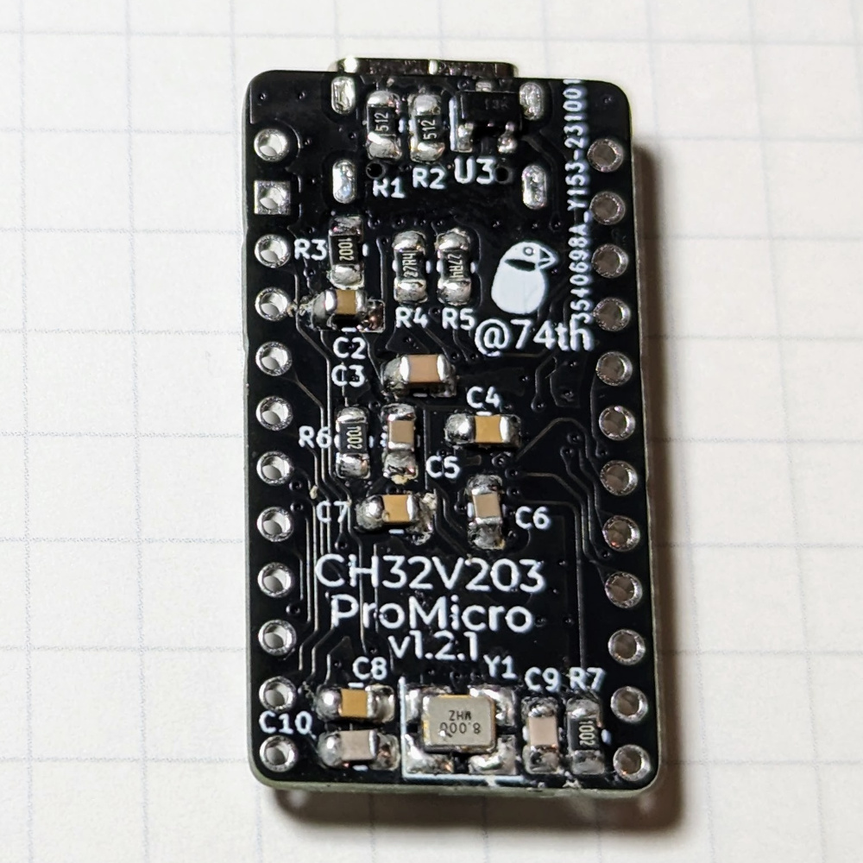
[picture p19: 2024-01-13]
ch32v203-promicro/docs/switch-science/74th-ch32v203-promicro-like-photo2.jpg

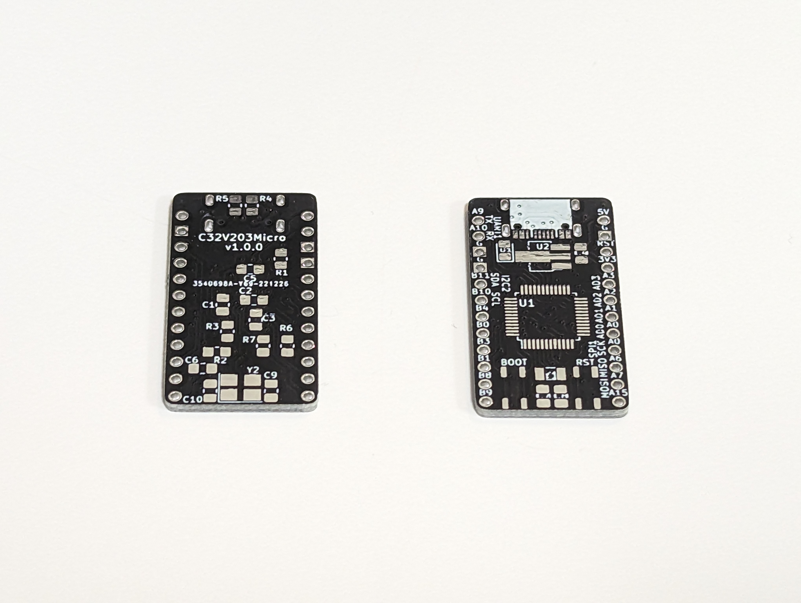
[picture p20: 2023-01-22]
ch32v203-promicro/docs/ch32v203-promicro-v1.0.0-2.jpg

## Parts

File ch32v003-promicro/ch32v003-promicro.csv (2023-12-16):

Reference | Value | Footprint | Function | 数量
C1, C2 | 10u | 74th:Capacitor_0805_2012 |  | 2
C3-C5 | 100n | 74th:Capacitor_0805_2012 |  | 3
C6 | 1u | 74th:Capacitor_0805_2012 |  | 1
D1 | Blue | 74th:LED_0805_2012 |  | 1
J1 | USB2.0_C_v3 | 74th:Connector_USB-C-Receptacle_SMT_12-Pin_Simple |  | 1
J2 | SWD-MCU_Side-10Pin | 74th:Connector_HalfPinHeader_SWD |  | 1
J3 | ProMicro-LeftPin | 74th:PinOut_ProMicro-LIKE_LEFT |  | 1
J4 | ProMicro-RightPin | 74th:PinOut_ProMicro-LIKE_RIGHT |  | 1
JP1 | SolderJumper_2_Open | Jumper:SolderJumper-2_P1.3mm_Open_RoundedPad1.0x1.5mm |  | 1
R3, R4 | 5.1k | 74th:Register_0805_2012 |  | 2
R5 | 1.5k(NC) | 74th:Register_0805_2012 |  | 1
R6, R7 | 27.4(NC) | 74th:Register_0805_2012 |  | 2
R8 | 0 | 74th:Register_0805_2012 |  | 1
R9, R10 | 10k | 74th:Register_0805_2012 |  | 2
SW1 | SW_Push | 74th:PushButton_SKRPABE010 | RST | 1
U1 | AMS1117-3.3 | 74th:Package_SOT-89-3 |  | 1
U2 | CH32V003F4P6 | 74th:Package_TSSOP-20_4.4x6.5mm_P0.65mm |  | 1
U3 | CH213K | 74th:Package_SOT-23 |  | 1

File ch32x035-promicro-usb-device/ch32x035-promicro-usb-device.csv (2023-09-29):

Reference | Value | Footprint | 数量
C1, C2 | 10u | 74th:Capacitor_0603_1608 | 2
C3 | 1u | 74th:Capacitor_0603_1608 | 1
C4 | 100n | 74th:Capacitor_0603_1608 | 1
CH1 | ProMicro-Left_NoGND | 74th:PinOut_ProMicro-LIKE_LEFT_NO-GND | 1
CH2 | ProMicro-Right | 74th:PinOut_ProMicro-LIKE_RIGHT | 1
CH3 | 3Pin | 74th:PinOut_3Pin | 1
CH4 | 2Pin | 74th:PinOut_2Pin | 1
D1 | BLUE | 74th:LED_0805_2012 | 1
J1 | 217179-0001 | 74th:Connector_USB-C-Receptacle_SMT_12-Pin_Simple | 1
J2 | SWD_10Pin_MCU-Side | 74th:Connector_HalfPinHeader_SWD | 1
JP1 | Jumper_2_Open | Jumper:SolderJumper-2_P1.3mm_Open_RoundedPad1.0x1.5mm | 1
R1, R2 | 5.1k | 74th:Register_0603_1608 | 2
R3 | 100k | 74th:Register_0603_1608 | 1
R4 | 1.5k | 74th:Register_0603_1608 | 1
R5, R8 | 10k | 74th:Register_0603_1608 | 2
R6, R7 | 27 | 74th:Register_0603_1608 | 2
SW1 | SKRPABE010 | 74th:PushButton_SKRPABE010 | 1
U1 | AMS1117-3.3 | Package_TO_SOT_SMD:SOT-89-3 | 1
U2 | CH32X035G8U6 | 74th:QFN-28-1EP_4x4mm_P0.4mm_EP2.8x2.8mm | 1
U3 | CH217K | Package_TO_SOT_SMD:SOT-23-6 | 1

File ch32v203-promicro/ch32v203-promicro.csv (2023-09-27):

Reference | Value | Footprint | 数量
C1, C2 | 10u | $74th:Capacitor_0805_2012 | 2
C3 | 1u | $74th:Capacitor_0805_2012 | 1
C4-C8 | 100n | $74th:Capacitor_0805_2012 | 5
C9, C10 | 22p | $74th:Capacitor_0805_2012 | 2
D1 | BLUE | $74th:LED_0805_2012Metric_Pad1.15x1.40mm_HandSolder | 1
J1 | USB2.0_C_v3 | $74th:USB-C-12-Pin-SMD | 1
J2 | ProMicro-LeftPin-NoGND | $74th:ProMicro_LIKE_LEFT_NO_GND | 1
J3 | ProMicro-RightPin | $74th:ProMicro_LIKE_RIGHT | 1
R1, R2 | 5.1k | $74th:Register_0805_2012 | 2
R3, R6, R7 | 10k | $74th:Register_0805_2012 | 3
R4, R5 | 27.4 | $74th:Register_0805_2012 | 2
SW1, SW2 | SW_Push | $74th:SKRPABE010 | 2
U1 | AMS1117-3.3 | Package_TO_SOT_SMD:SOT-89-3_Handsoldering | 1
U2 | CH32V203C8T6 | Package_QFP:LQFP-48_7x7mm_P0.5mm | 1
U3 | CH213K | Package_TO_SOT_SMD:SOT-23 | 1
Y1 | 8M | $74th:Crystal_SMD_3225-4Pin_3.2x2.5mm_HandSoldering | 1

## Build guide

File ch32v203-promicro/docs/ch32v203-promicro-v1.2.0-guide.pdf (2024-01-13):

# 74th. CH32V203 ProMicro Like

## CH32V203搭載ProMicroピン互換ボード

## 回路図等サポートページ

https://github.com/74th/ch32v-dev-boards/tree/main/ch32v203-p romicro

## 制作者連絡先

Twitter/GitHub :74th
Gmail: 74th.tech@gmail.com

Atsushi Morimoto (@74th)

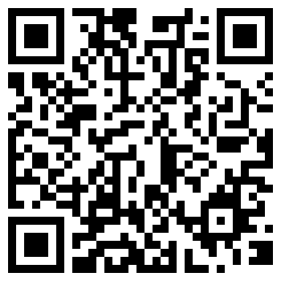
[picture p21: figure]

## ファームウェアの書き込みの仕方について

CH32V203には2つの書き込み方法があります。
1. ＵＳＢ経由
2. WCH-Link/WCH-LinkEデバッガを用いて、RISC-V用ＳrtＷＤ ポート SWDIO、ＳＷＣＬＫ経由で書き込む

USB経由での書き込み

BOOTボタンを押しながらRESET(RST)を押すことで、USB経由で書き込 める状態になります。wchisp(ch32-rs)や、WCHISPTool(公式)を使う ことで書き込むことができます。

ＳＷＤポートでの書き込み

ProMicroの左側のGNDを、SWDIO、SWCLKに置き換えています。こち らとWCH-Link（もしくはWCH-LinkE）を接続することで、書き込むことが

できます。WCH-LinkEは秋月電子通商で購入することができます。 WCH-LinkEクローンを74ｔｈの方で制作していますので、良ければこちら もBoothShopにて購入を検討ください。
ソフトウェアには、wchisp(ch32-rs)、minichlink(ch32v003fun)、 WCHLinkUtility(公式)、公式IDEのMounRiverStudio付属の OpenOCDが利用可能です。

## ＣＨ３２Ｖ２０３の開発方法について

ＣＨ３２Ｖ２０３の開発方法はご自身でお調べの上、利用してください。74th が知る範囲では以下の方法があります。

・ WCH公式のArduino開発環境
https://github.com/openwch/arduino_core_ch32 ※Arduinoでのファームウェアの書き込みにはSWDポートを利用します。 USBで書き込む場合には、別途ツールが必要です。
・ ＷＣＨ公式ＳＤＫ（C、C++）
・ IDE MountRiverStudio（Ｅｃｌｉｐｓｅベース、無料版あり）
・ ＰｌａｔｆｏｒｍＩＯ の CH32Vサポートコミュニティパッケージ
・ ch32-rs（Rust）

各ツール、SDK等へのリンクは、サポートページのGitHubリポジトリ内の READMEに記載しています。こちらもご覧下さい。

## CH32V203データシート

http://www.wch-ic.com/downloads/CH32V20x_30xDS0_PDF .html

## ピン配置

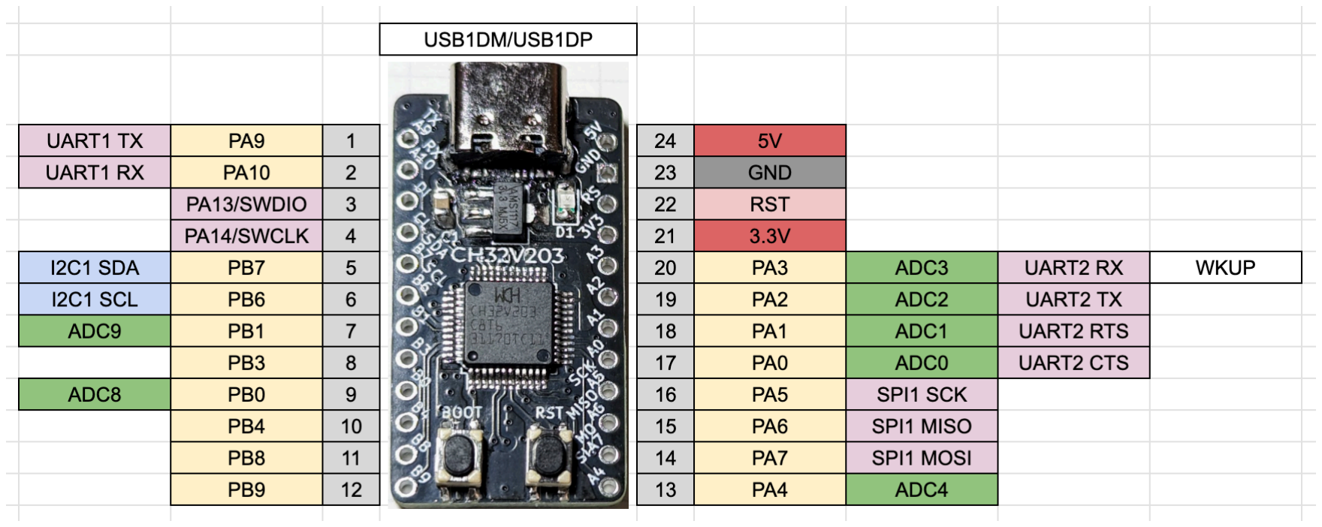
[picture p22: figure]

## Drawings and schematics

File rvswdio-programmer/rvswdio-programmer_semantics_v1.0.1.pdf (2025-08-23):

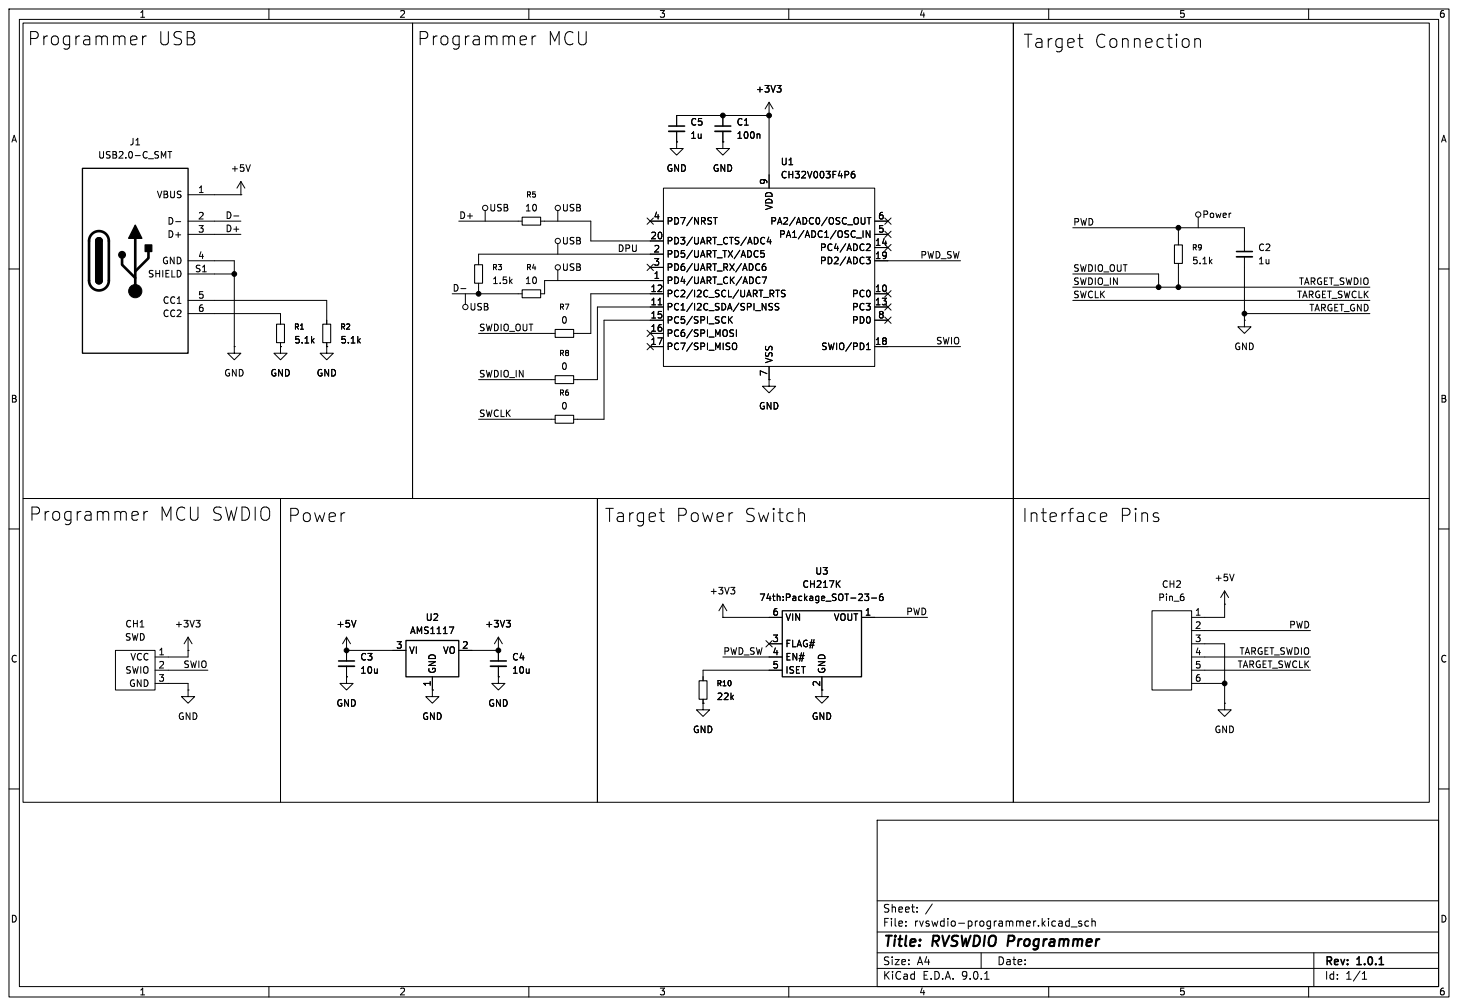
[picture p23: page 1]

+3V3 +3V3 VCC 1 SWIO 2 GND 3 CH1 SWD

Id: 1/1 Title: RVSWDIO Programmer File: rvswdio-programmer.kicad_sch Sheet: /

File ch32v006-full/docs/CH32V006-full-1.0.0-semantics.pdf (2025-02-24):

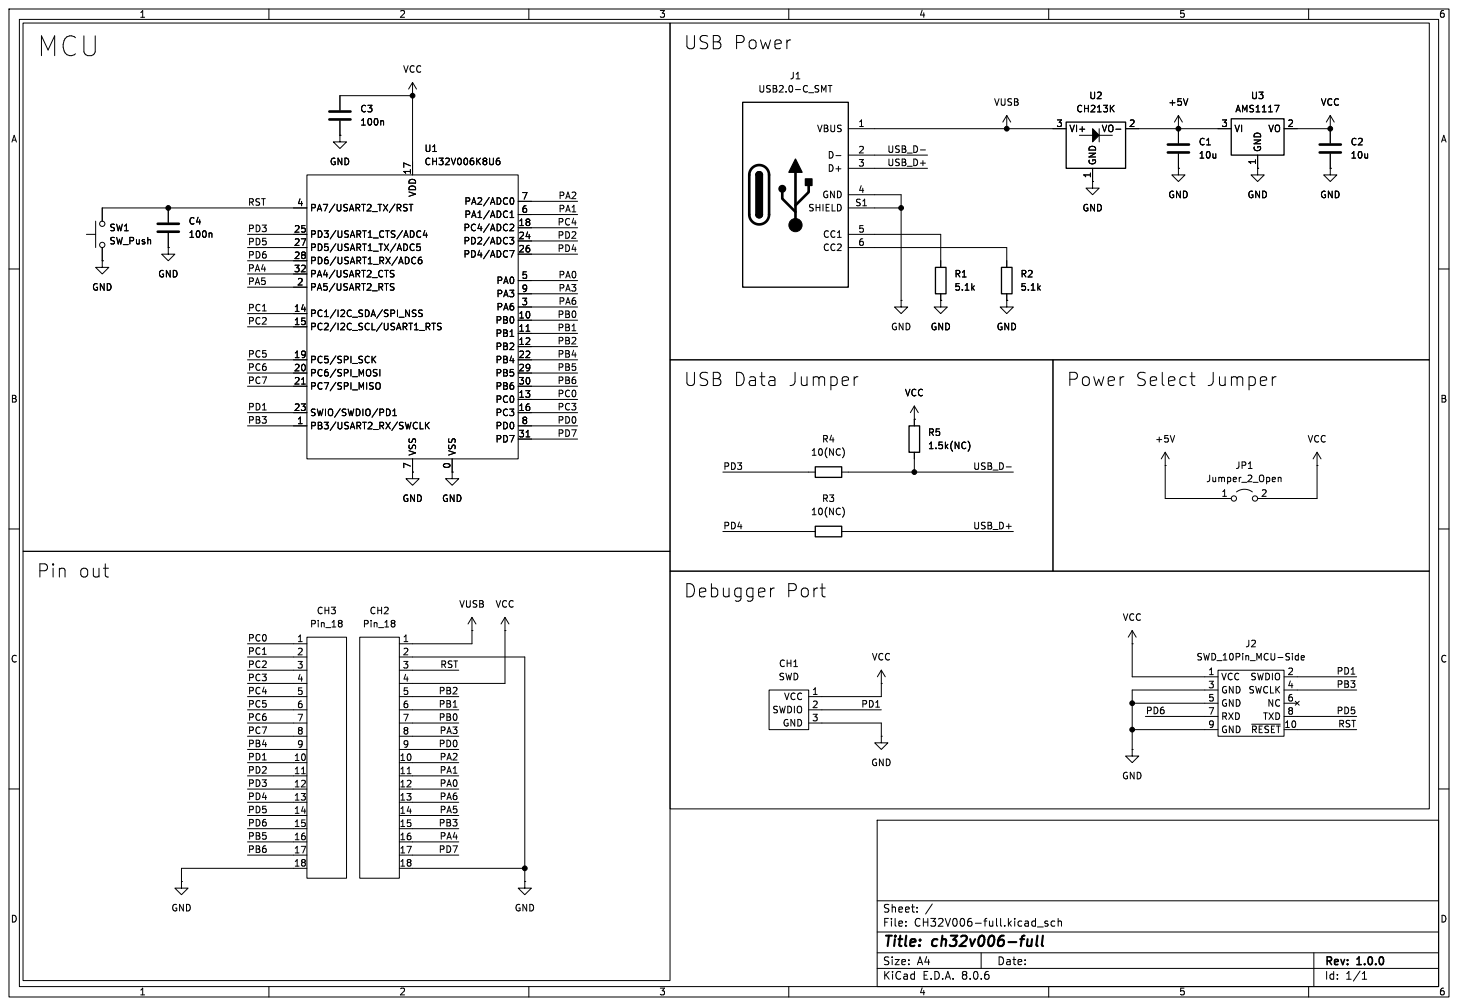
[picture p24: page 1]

Id: 1/1 Title: ch32v006-full File: CH32V006-full.kicad_sch Sheet: /

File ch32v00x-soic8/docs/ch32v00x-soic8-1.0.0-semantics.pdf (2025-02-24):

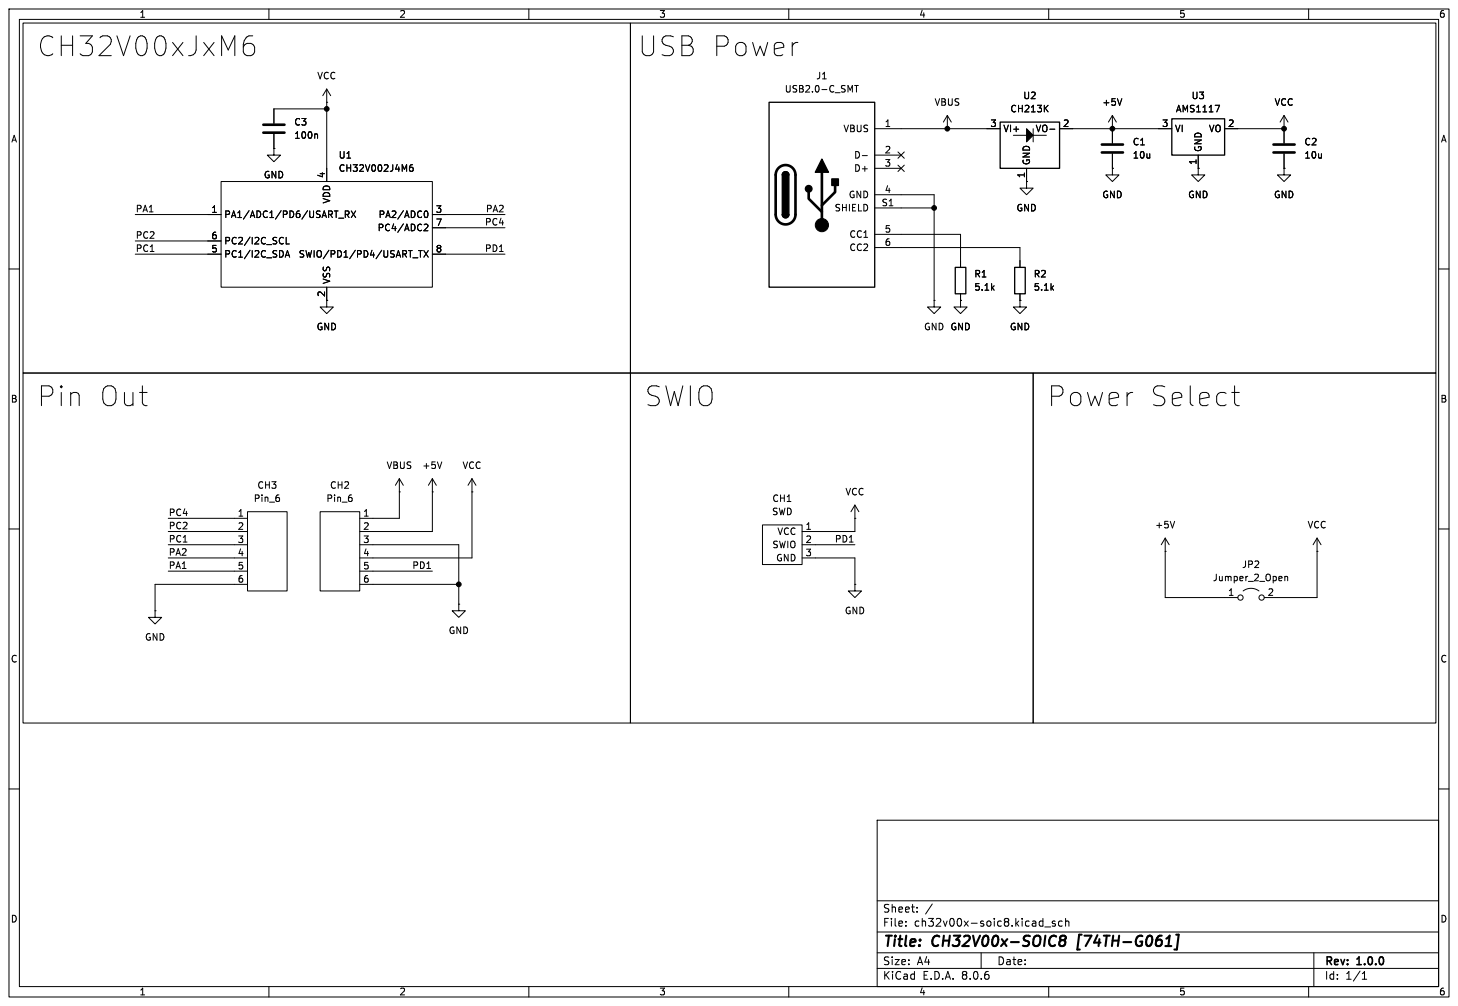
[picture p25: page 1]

1 VO- 2 VI+ 3 U2 CH213K +5V GND GND

1 VO 2 VI 3 U3 AMS1117 VCC GND GND GNDGND

1 VO- 2 VI+ 3 +5V GND GND

1 VO 2 VI 3 VCC GND GND

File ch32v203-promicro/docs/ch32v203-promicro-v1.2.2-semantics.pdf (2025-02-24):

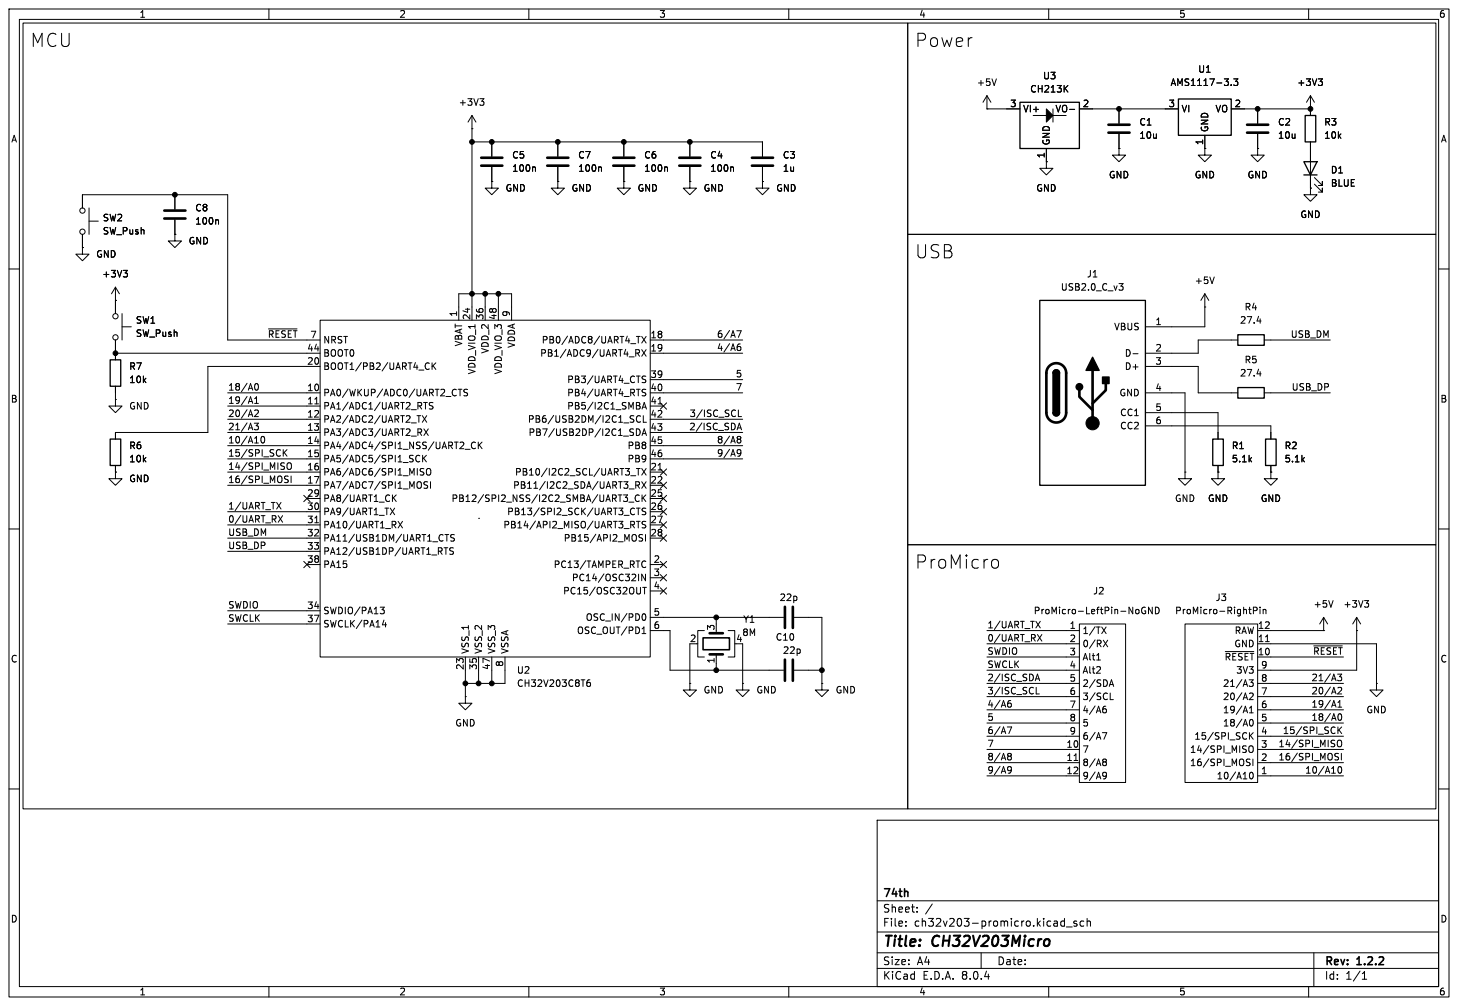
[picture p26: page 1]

1 VO- 2 VI+ 3 GND GND

1 PA0/WKUP/ADC0/UART2_CTS 10 PA1/ADC1/UART2_RTS 11 PA2/ADC2/UART2_TX 12 PA3/ADC3/UART2_RX 13 PA4/ADC4/SPI1_NSS/UART2_CK 14 PA5/ADC5/SPI1_SCK 15 PA6/ADC6/SPI1_MISO 16 PA7/ADC7/SPI1_MOSI 17 PB0/ADC8/UART4_TX 18 PB1/ADC9/UART4_RX 19 PC13/TAMPER_RTC 2 BOOT1/PB2/UART4_CK 20 PB10/I2C2_SCL/UART3_TX 21 PB11/I2C2_SDA/UART3_RX 22 VSS_1 23 VDD_VIO_1 24 PB12/SPI2_NSS/I2C2_SMBA/UART3_CK 25 PB13/SPI2_SCK/UART3_CTS 26 PB14/API2_MISO/UART3_RTS 27 PB15/API2_MOSI 28 PA8/UART1_CK 29 PC14/OSC32IN 3 PA9/UART1_TX 30 PA10/UART1_RX 31 PA11/USB1DM/UART1_CTS 32 PA12/USB1DP/UART1_RTS 33 SWDIO/PA13 34 VSS_2 35 VDD_2 36 SWCLK/PA14 37 PA15 38 PB3/UART4_CTS 39 PC15/OSC32OUT 4 PB4/UART4_RTS 40 PB5/I2C1_SMBA 41 PB6/USB2DM/I2C1_SCL 42 PB7/USB2DP/I2C1_SDA 43 BOOT0 44 PB8 45 PB9 46 VSS_3 47 VDD_VIO_3 48 OSC_IN/PD0 5 OSC_OUT/PD1 6 NRST 7 VSSA

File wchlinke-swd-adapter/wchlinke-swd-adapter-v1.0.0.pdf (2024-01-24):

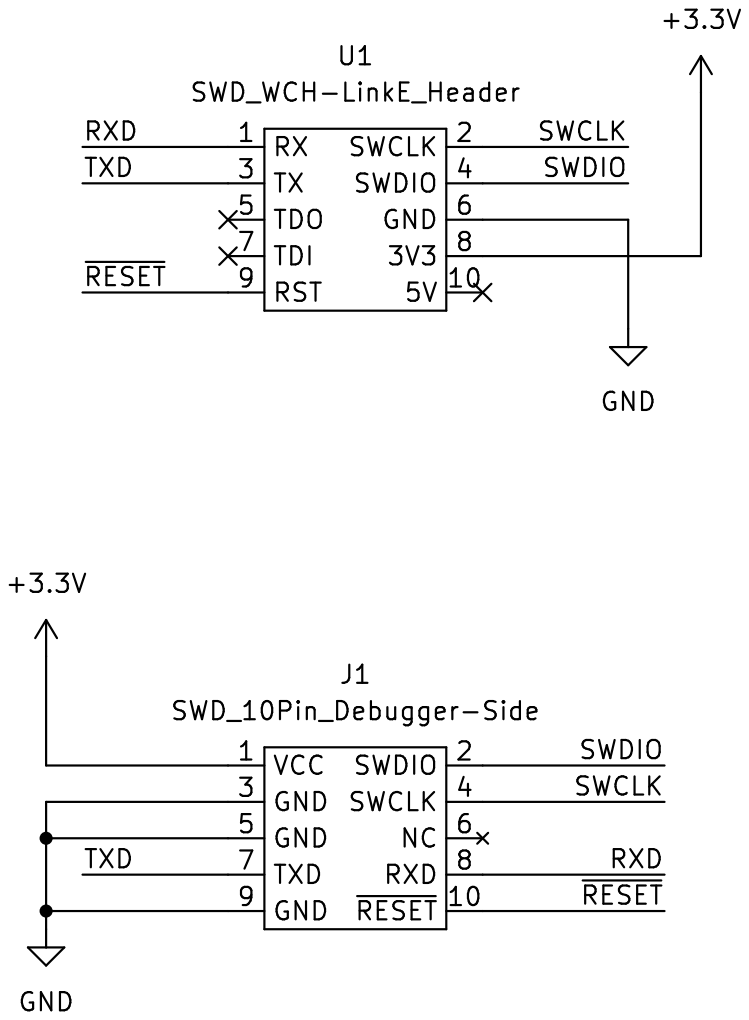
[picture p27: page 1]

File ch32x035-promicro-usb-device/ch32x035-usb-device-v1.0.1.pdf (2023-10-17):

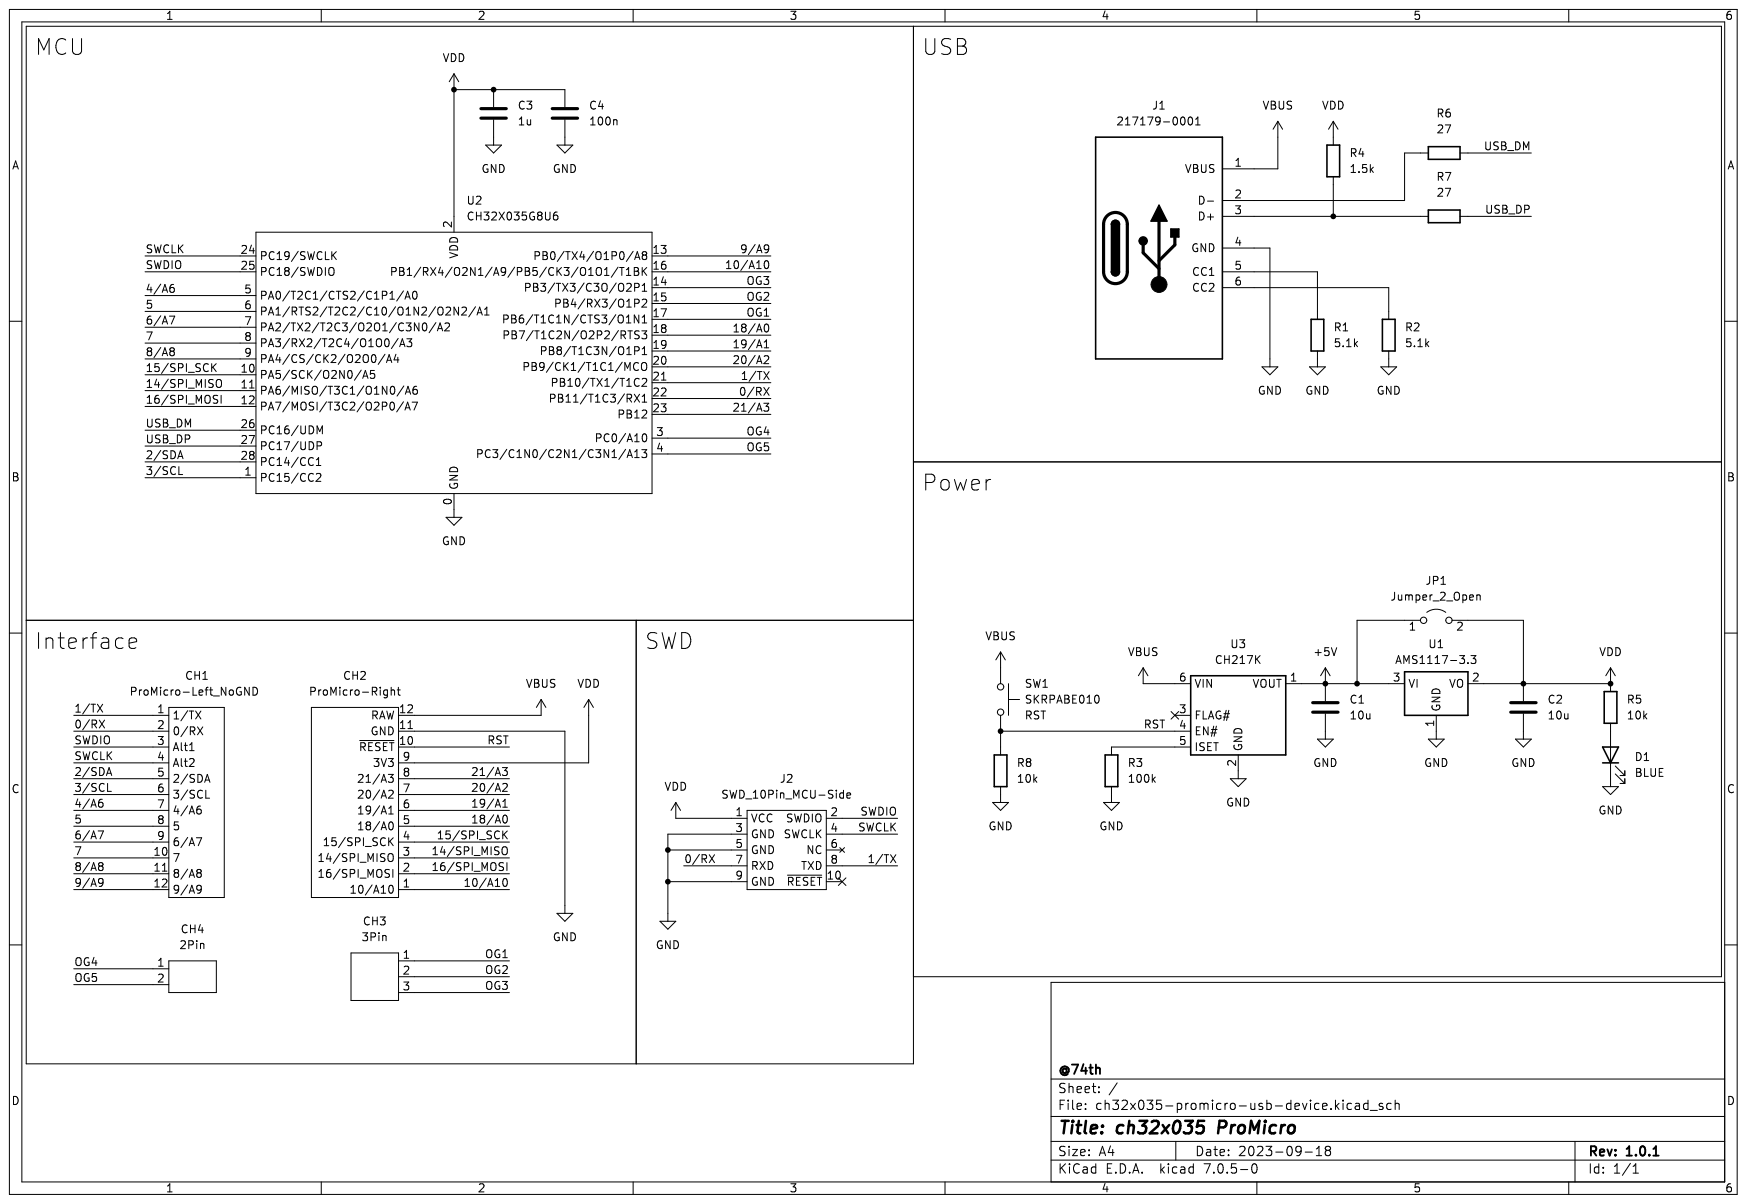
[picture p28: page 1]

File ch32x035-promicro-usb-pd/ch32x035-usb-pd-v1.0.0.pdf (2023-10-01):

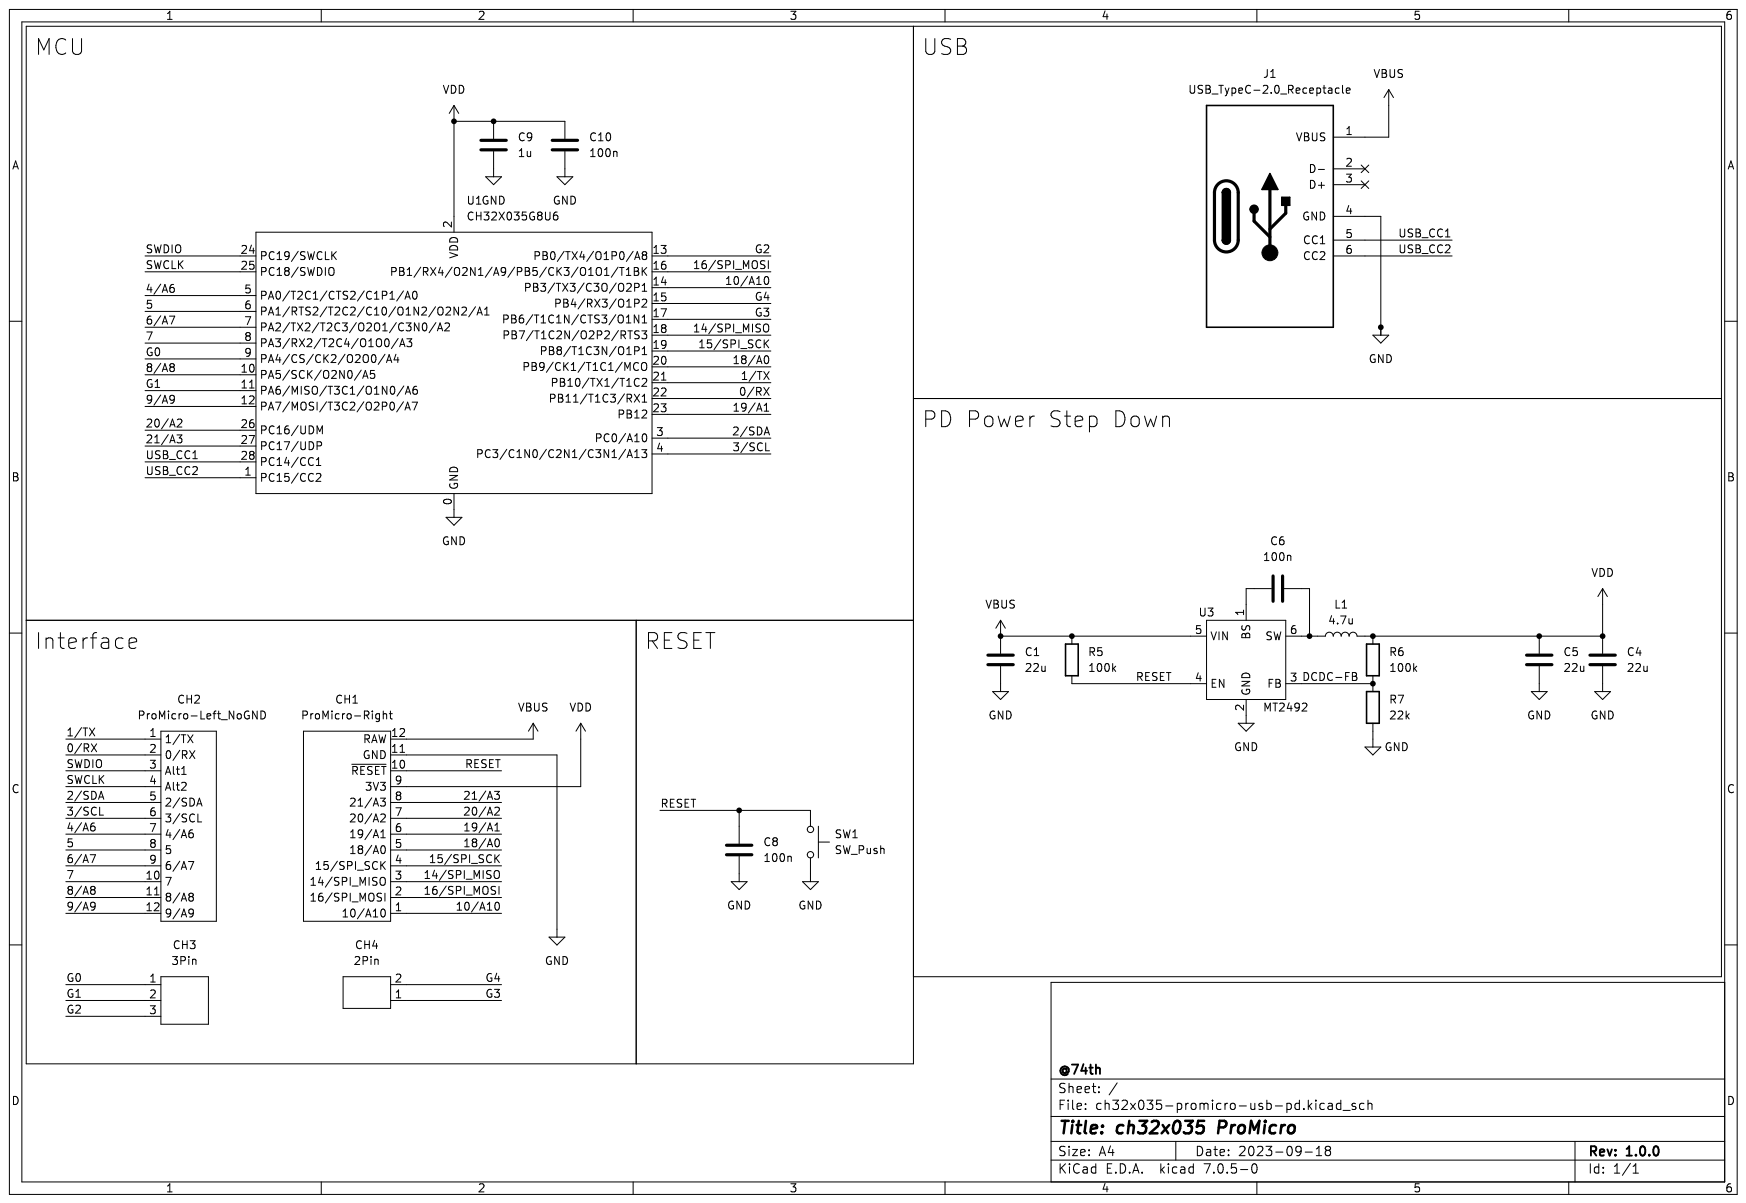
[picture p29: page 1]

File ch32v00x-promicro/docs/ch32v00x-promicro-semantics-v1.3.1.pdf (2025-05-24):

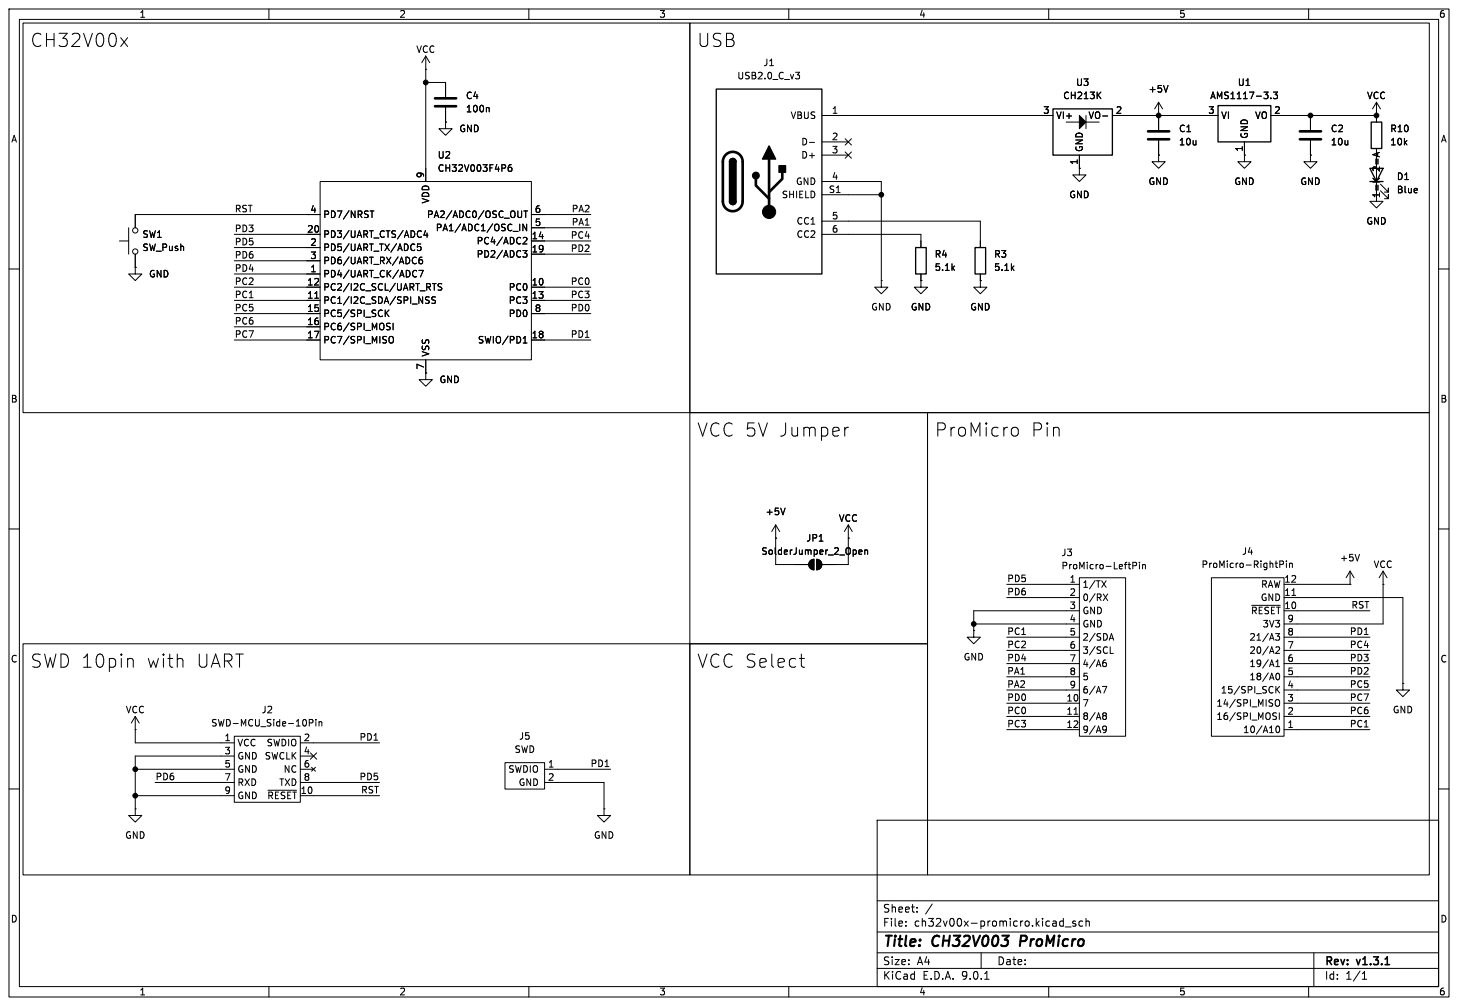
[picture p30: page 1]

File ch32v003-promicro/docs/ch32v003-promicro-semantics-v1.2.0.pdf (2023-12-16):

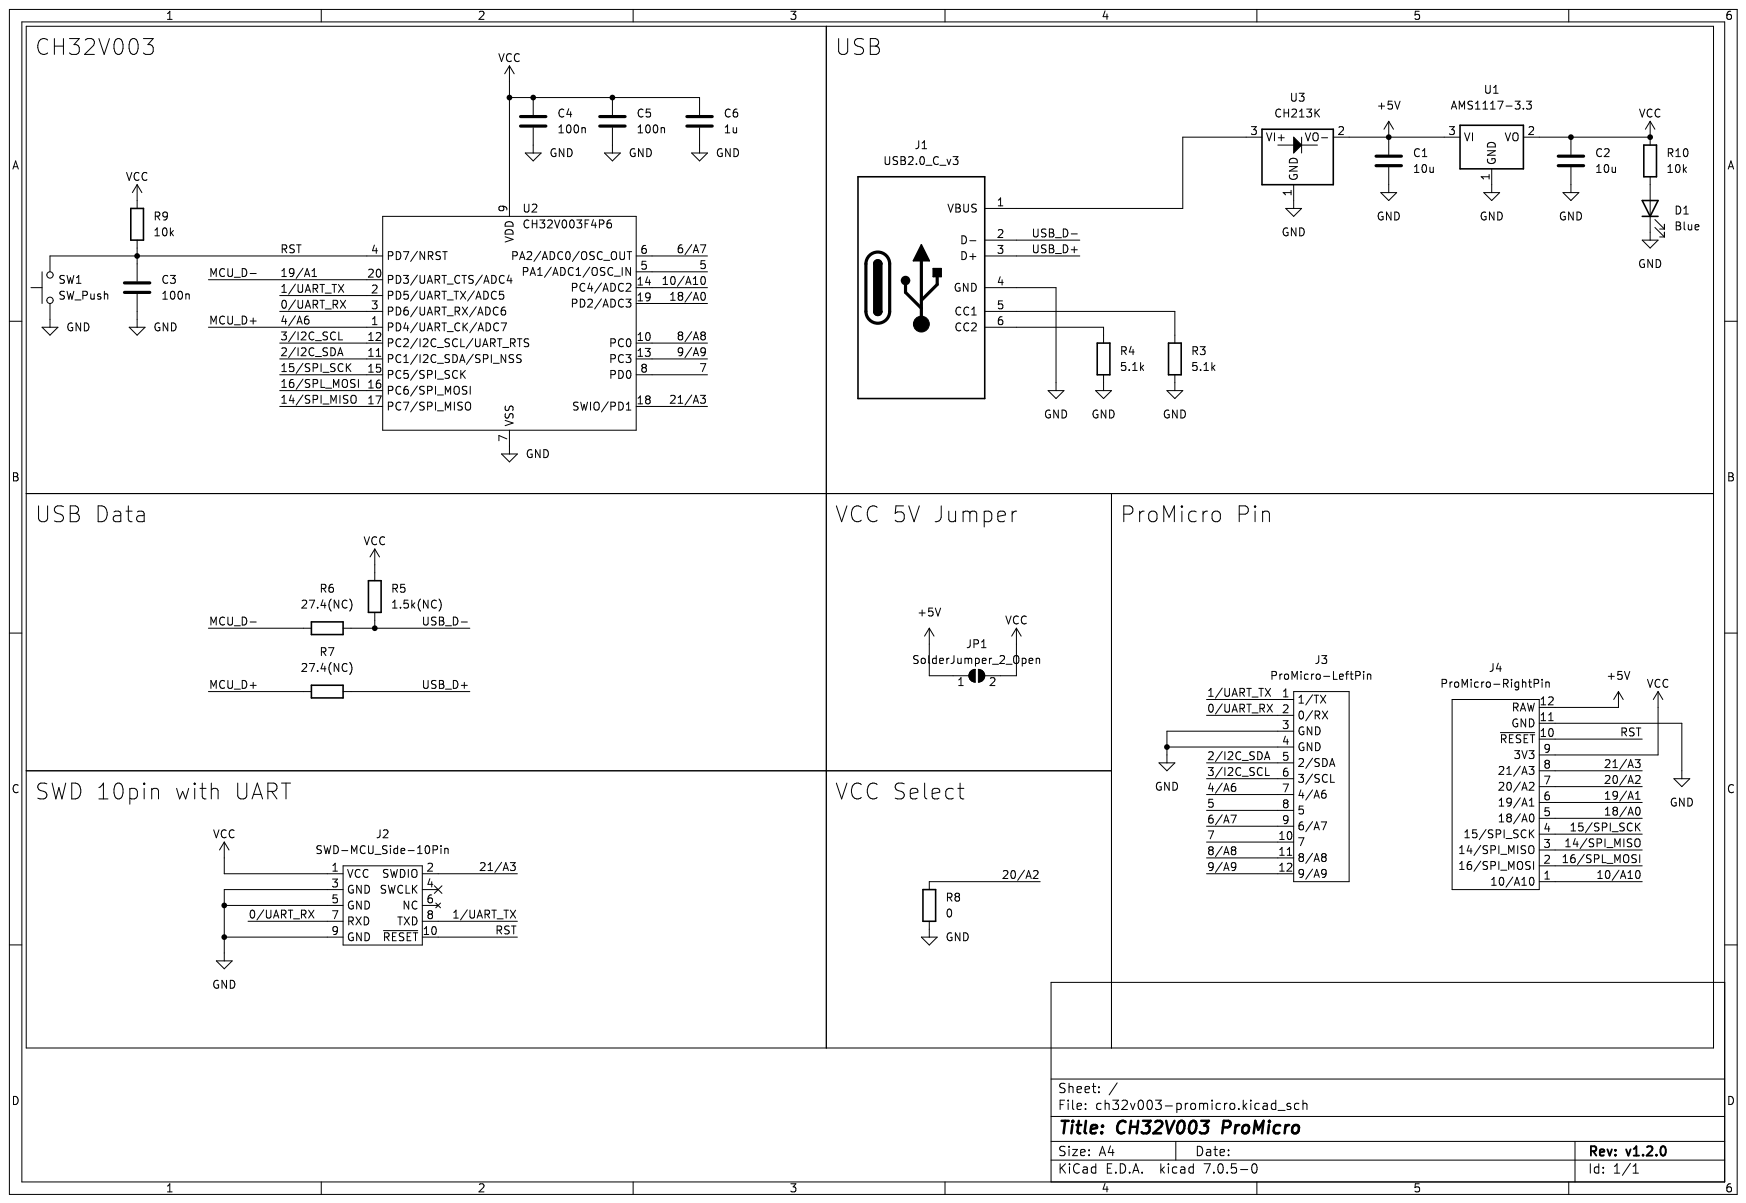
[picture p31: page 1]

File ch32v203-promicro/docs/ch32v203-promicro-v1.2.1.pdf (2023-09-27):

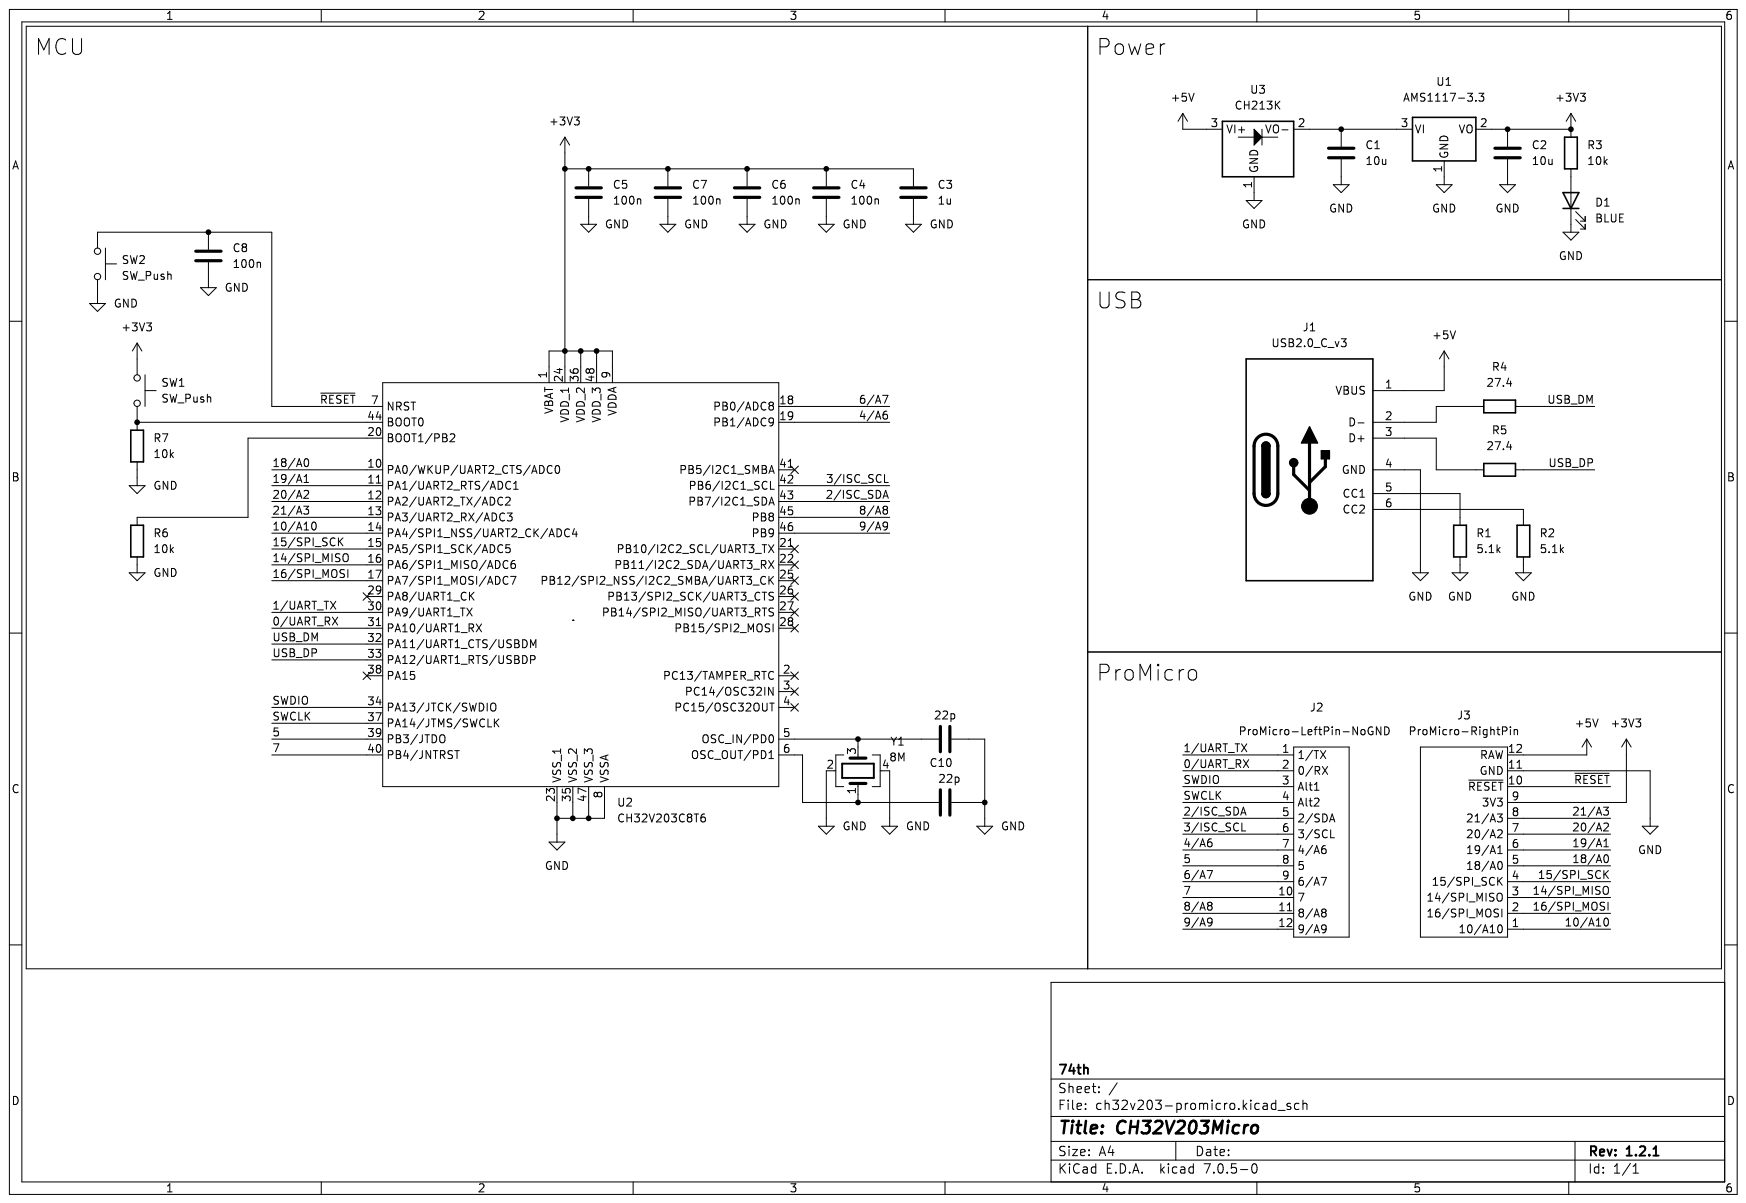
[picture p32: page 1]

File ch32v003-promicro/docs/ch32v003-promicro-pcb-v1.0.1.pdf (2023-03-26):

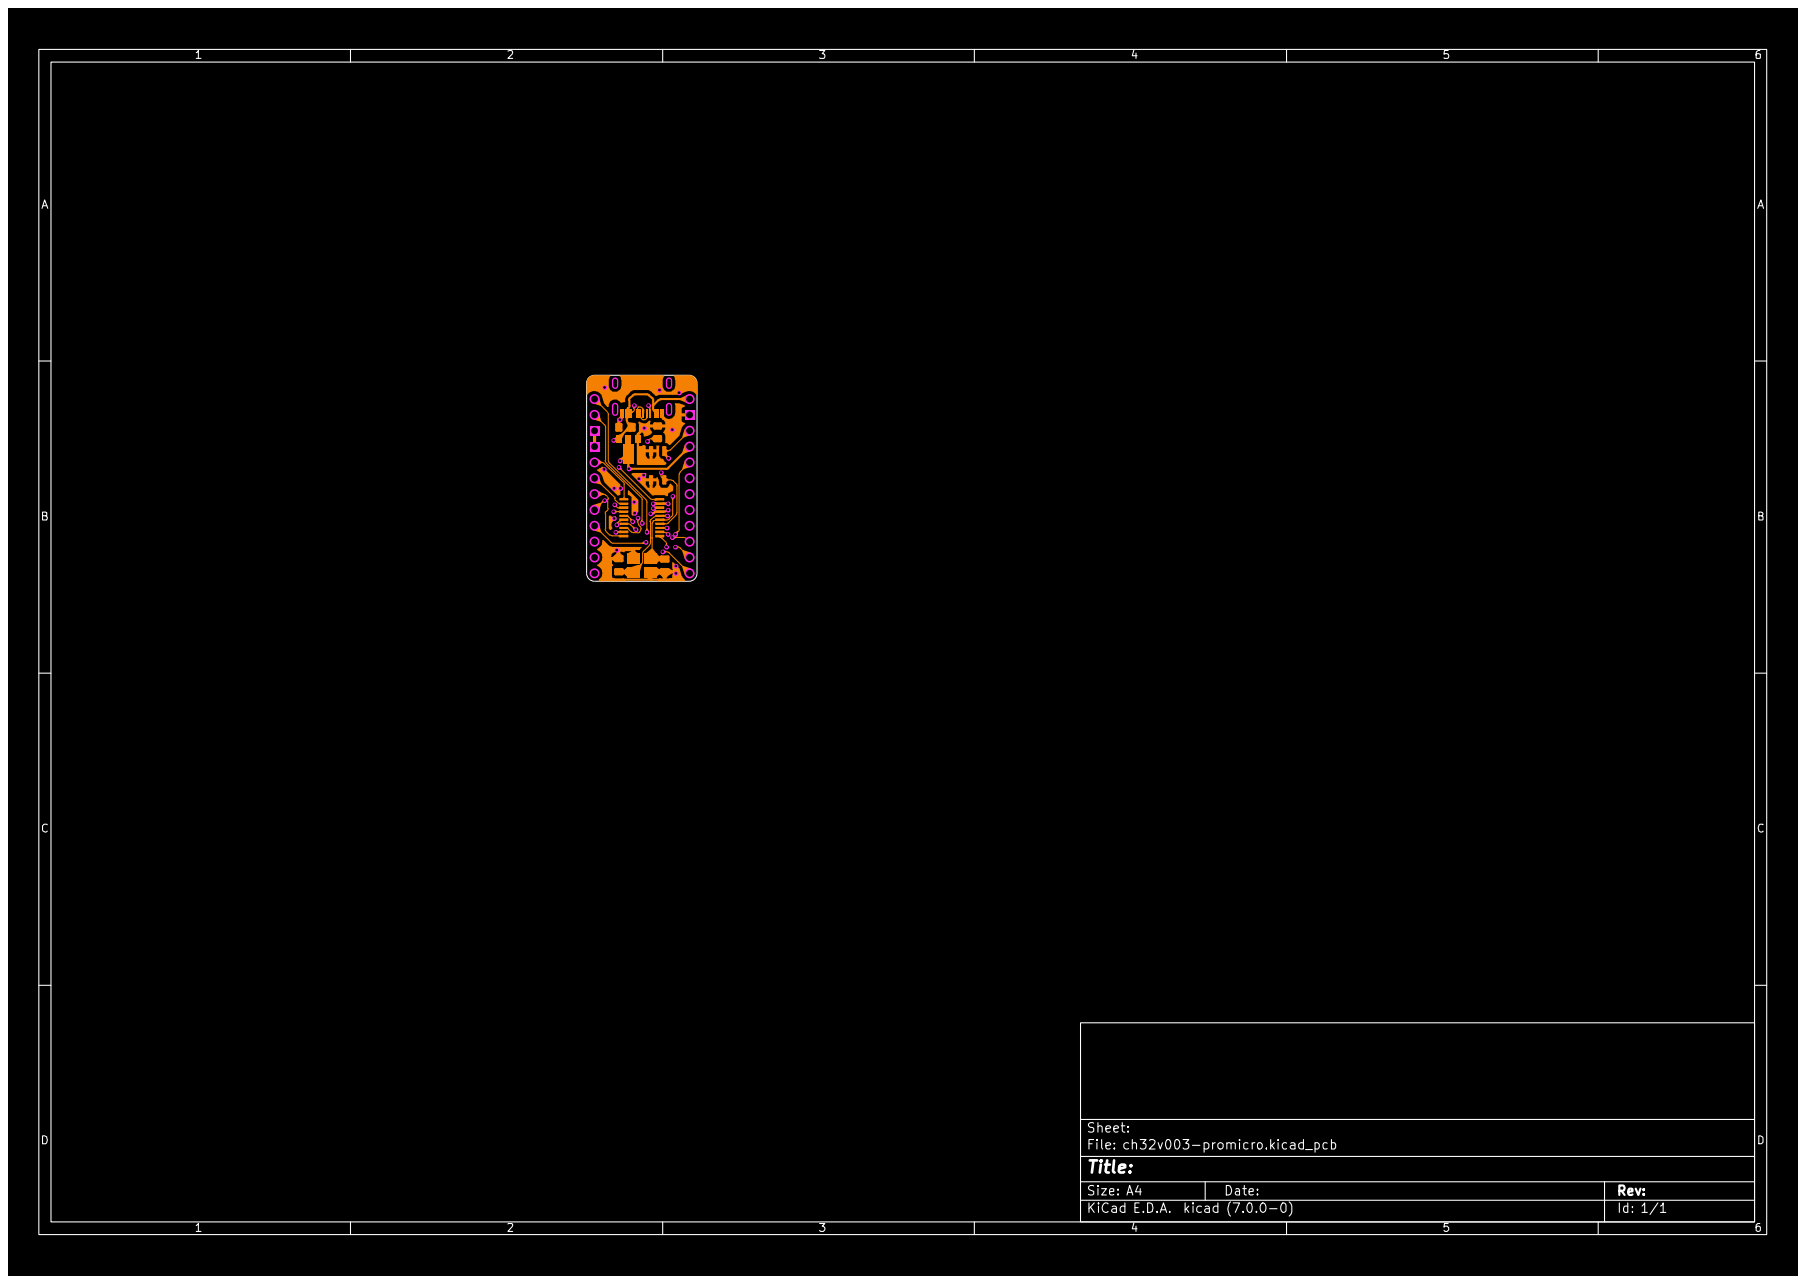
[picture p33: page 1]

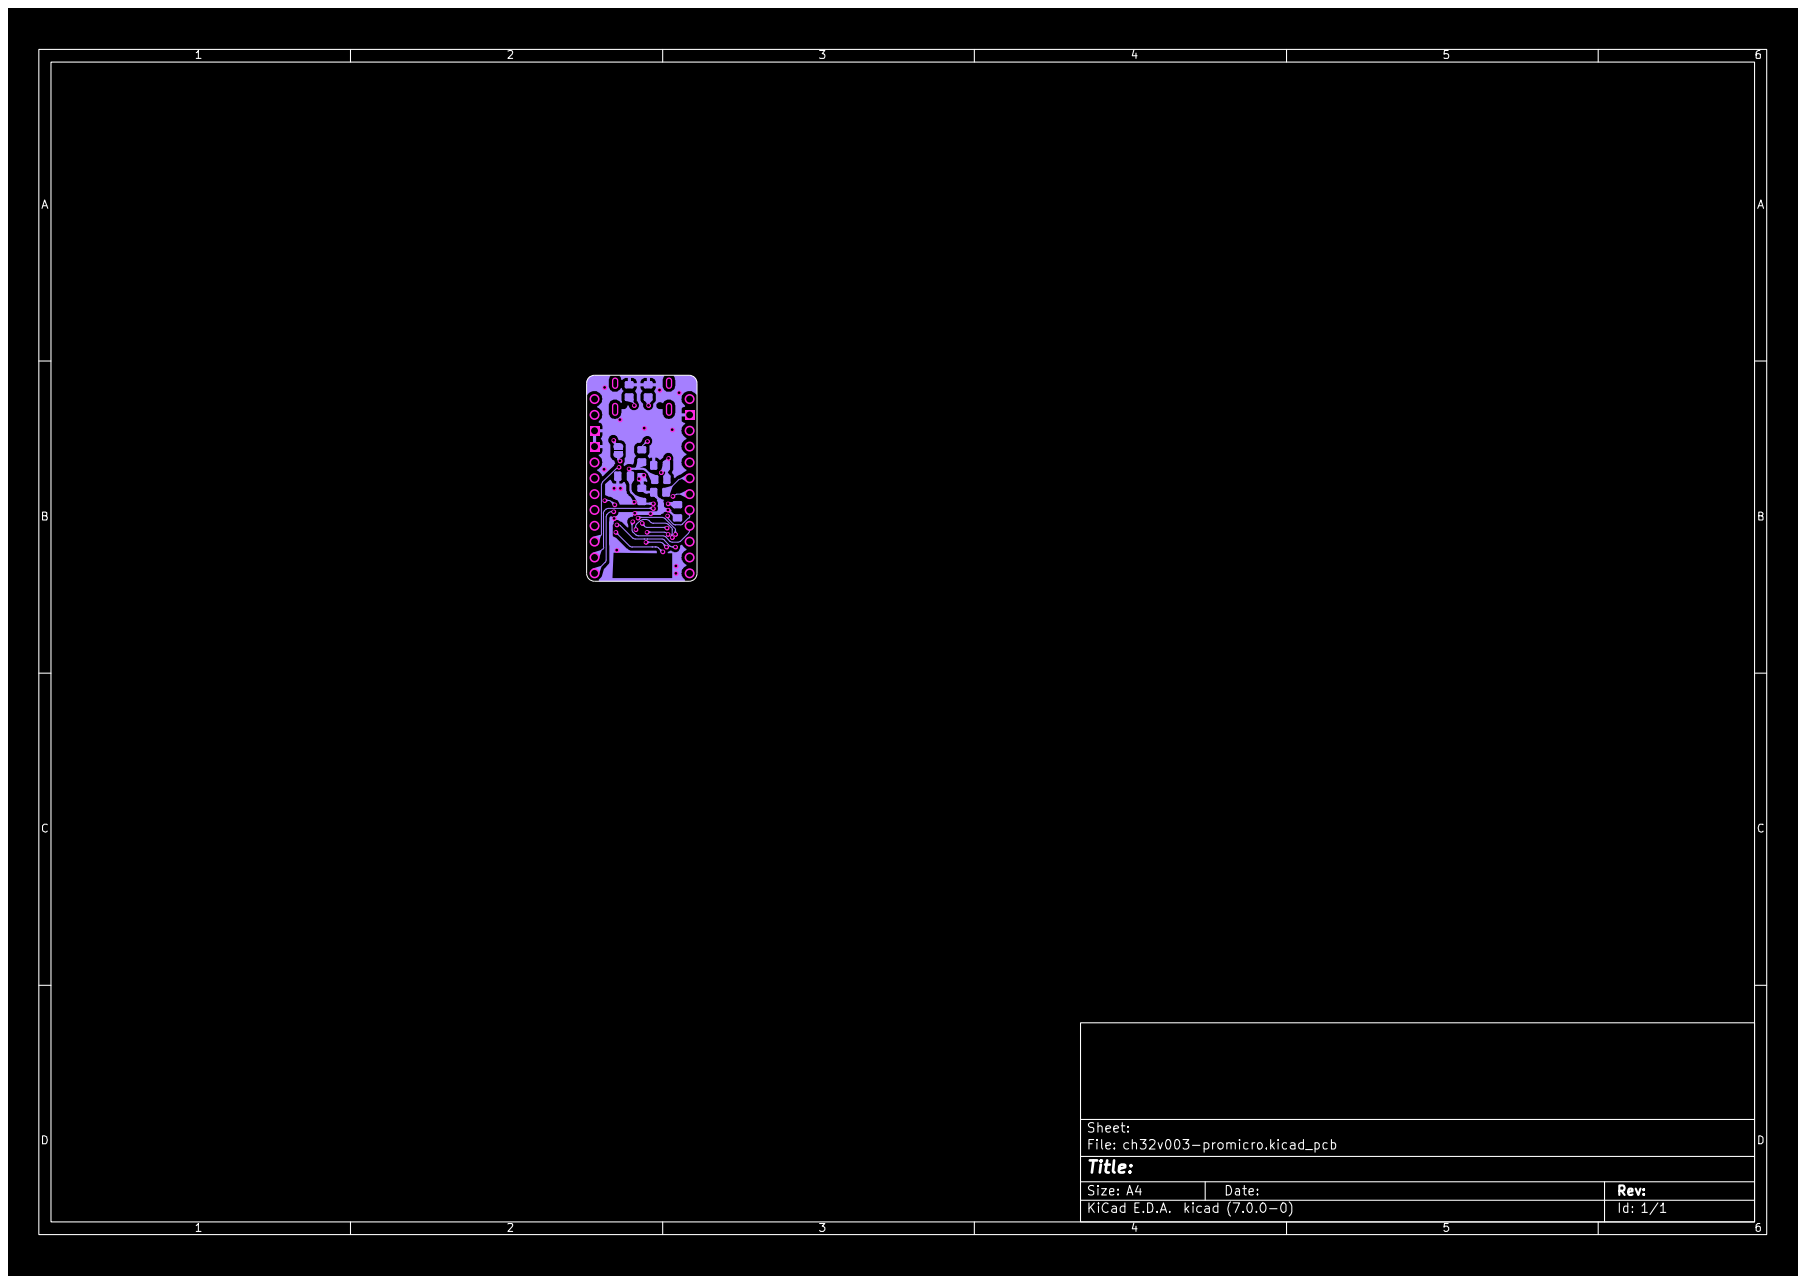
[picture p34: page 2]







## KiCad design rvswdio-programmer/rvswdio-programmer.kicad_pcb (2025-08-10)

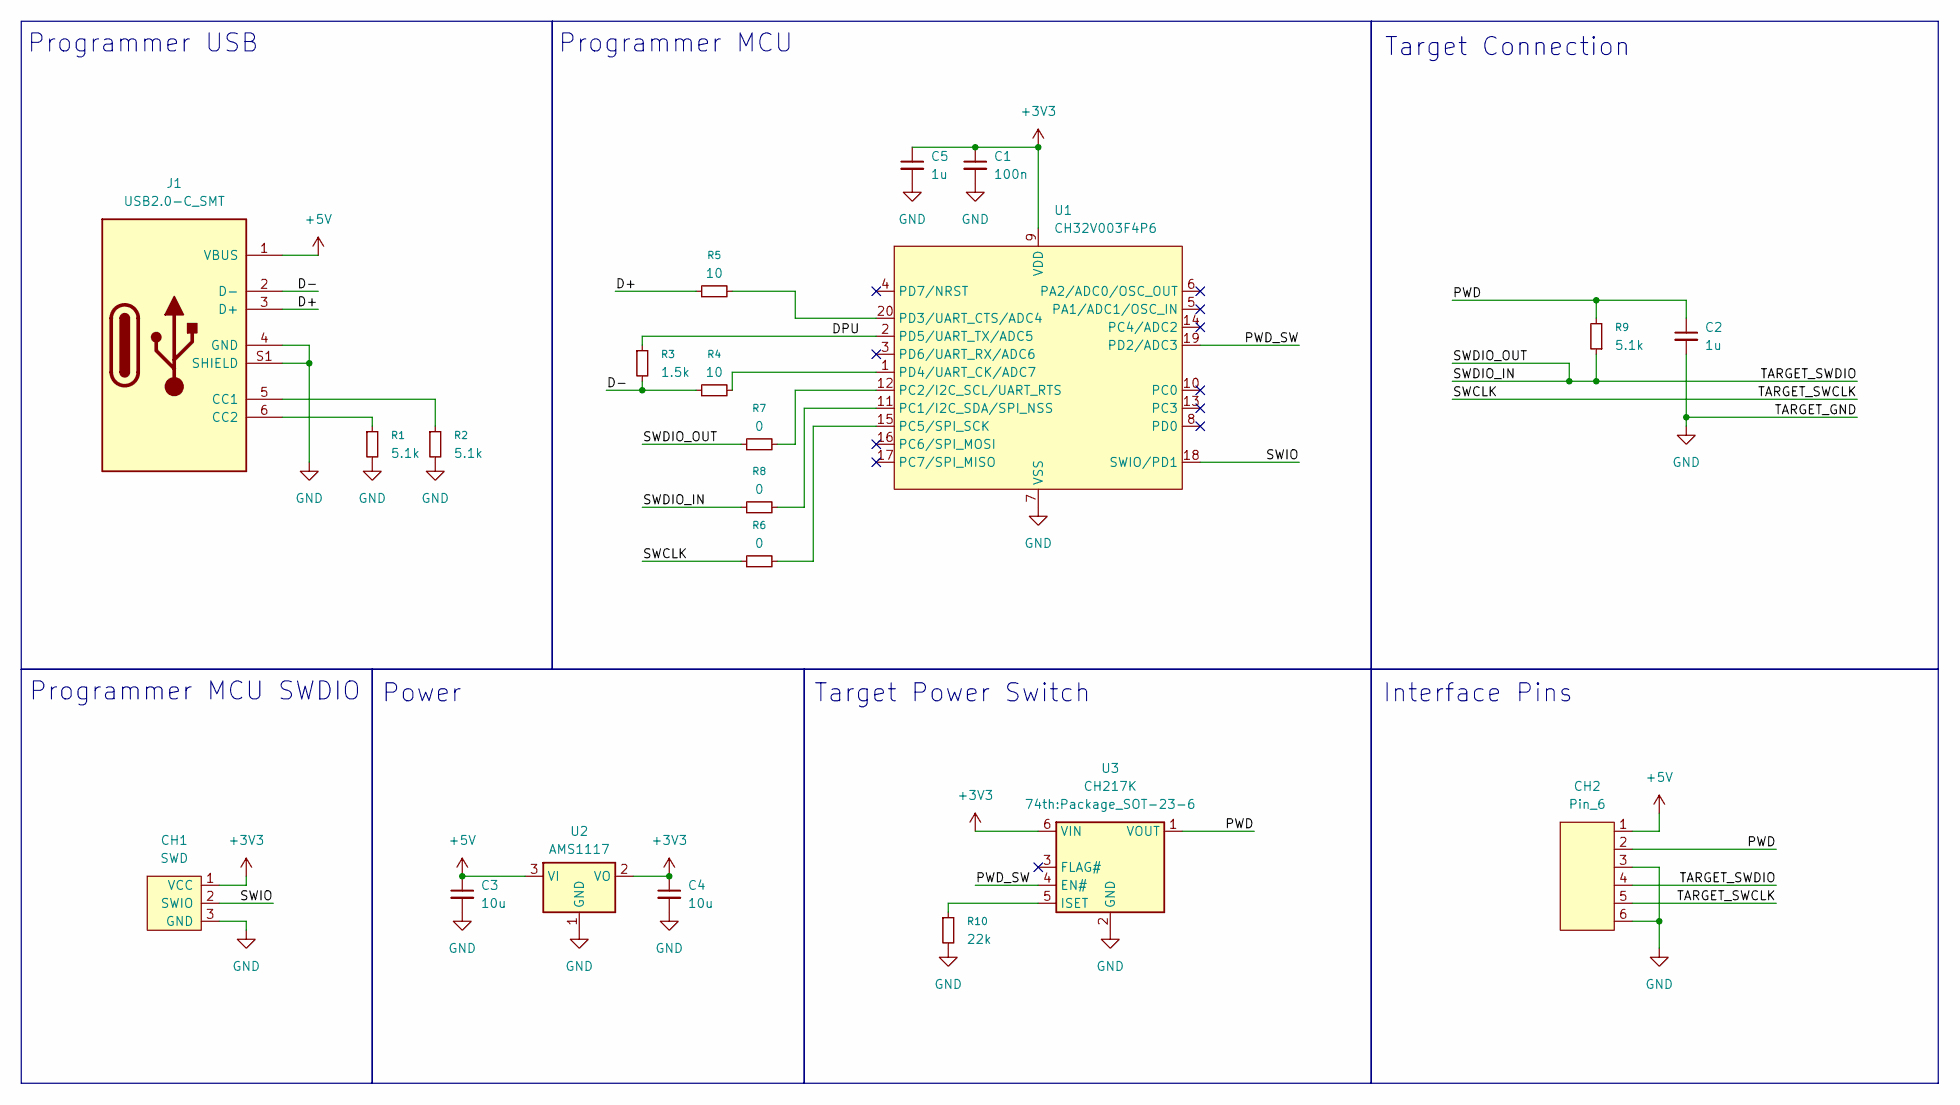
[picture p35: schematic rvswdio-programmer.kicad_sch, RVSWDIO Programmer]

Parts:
C1: 100n; Capacitor_0603_1608
C2, C5: 1u; Capacitor_0603_1608
C3, C4: 10u; Capacitor_0603_1608
CH1: SWD; PinOut_Pin_3_3GND
CH2: Pin_6; PinOut_Pin_6_GND
J1: USB2.0-C_SMT; Connector_USB-C-Receptacle_SMT_12-Pin_Simple
R1, R2, R9: 5.1k; Register_0603_1608
R3: 1.5k; Register_0603_1608
R4, R5: 10; Register_0603_1608
R6, R7, R8: 0; Register_0603_1608
R10: 22k; Register_0603_1608
U1: CH32V003F4P6; Package_TSSOP-20_4.4x6.5mm_P0.65mm
U2: AMS1117; Package_SOT-89-3
U3: CH217K; Package_SOT-23-6

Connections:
+3V3: C1.1, C4.1, C5.1, CH1.1 (VCC), U1.9 (VDD), U2.2 (VO), U3.6 (VIN)
+5V: C3.1, CH2.1, J1.1 (VBUS), U2.3 (VI)
/D+: J1.3 (D+), R5.1
/D-: J1.2 (D-), R3.2, R4.1
/DPU: R3.1, U1.2 (PD5/UART_TX/ADC5)
/PWD: C2.1, CH2.2, R9.2, U3.1 (VOUT)
/PWD_SW: U1.19 (PD2/ADC3), U3.4 (EN#)
/SWCLK: CH2.5, R6.1
/SWDIO_IN: CH2.4, R7.1, R8.1, R9.1
/SWIO: CH1.2 (SWIO), U1.18 (SWIO/PD1)
GND: C1.2, C2.2, C3.2, C4.2, C5.2, CH1.3 (GND), CH2.3, CH2.6, J1.4 (GND), J1.S1 (SHIELD), R1.2, R2.2, R10.2, U1.7 (VSS), U2.1 (GND), U3.2 (GND)
unnamed: J1.5 (CC1), R2.1
unnamed: J1.6 (CC2), R1.1
unnamed: R8.2, U1.11 (PC1/I2C_SDA/SPI_NSS)
unnamed: R7.2, U1.12 (PC2/I2C_SCL/UART_RTS)
unnamed: R6.2, U1.15 (PC5/SPI_SCK)
unnamed: R5.2, U1.20 (PD3/UART_CTS/ADC4)
unnamed: R4.2, U1.1 (PD4/UART_CK/ADC7)
unnamed: R10.1, U3.5 (ISET)

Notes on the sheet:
Target Connection
Target Power Switch
Interface Pins
Power
Programmer MCU
Programmer USB
Programmer MCU SWDIO

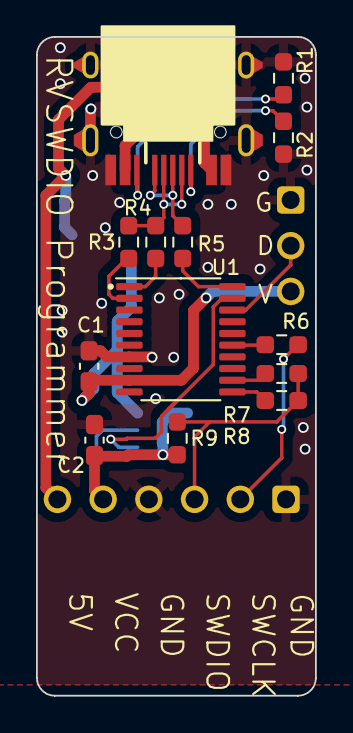
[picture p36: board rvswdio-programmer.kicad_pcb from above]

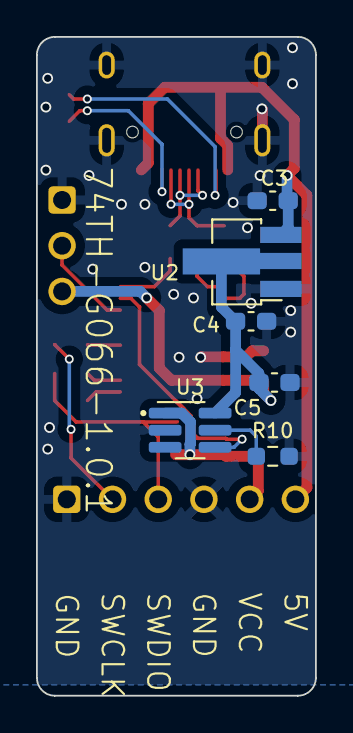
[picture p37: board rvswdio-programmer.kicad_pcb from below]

Board: 2 copper layers, 15.5 x 36.6 mm, 21 parts (6 on the bottom side), 19 nets.

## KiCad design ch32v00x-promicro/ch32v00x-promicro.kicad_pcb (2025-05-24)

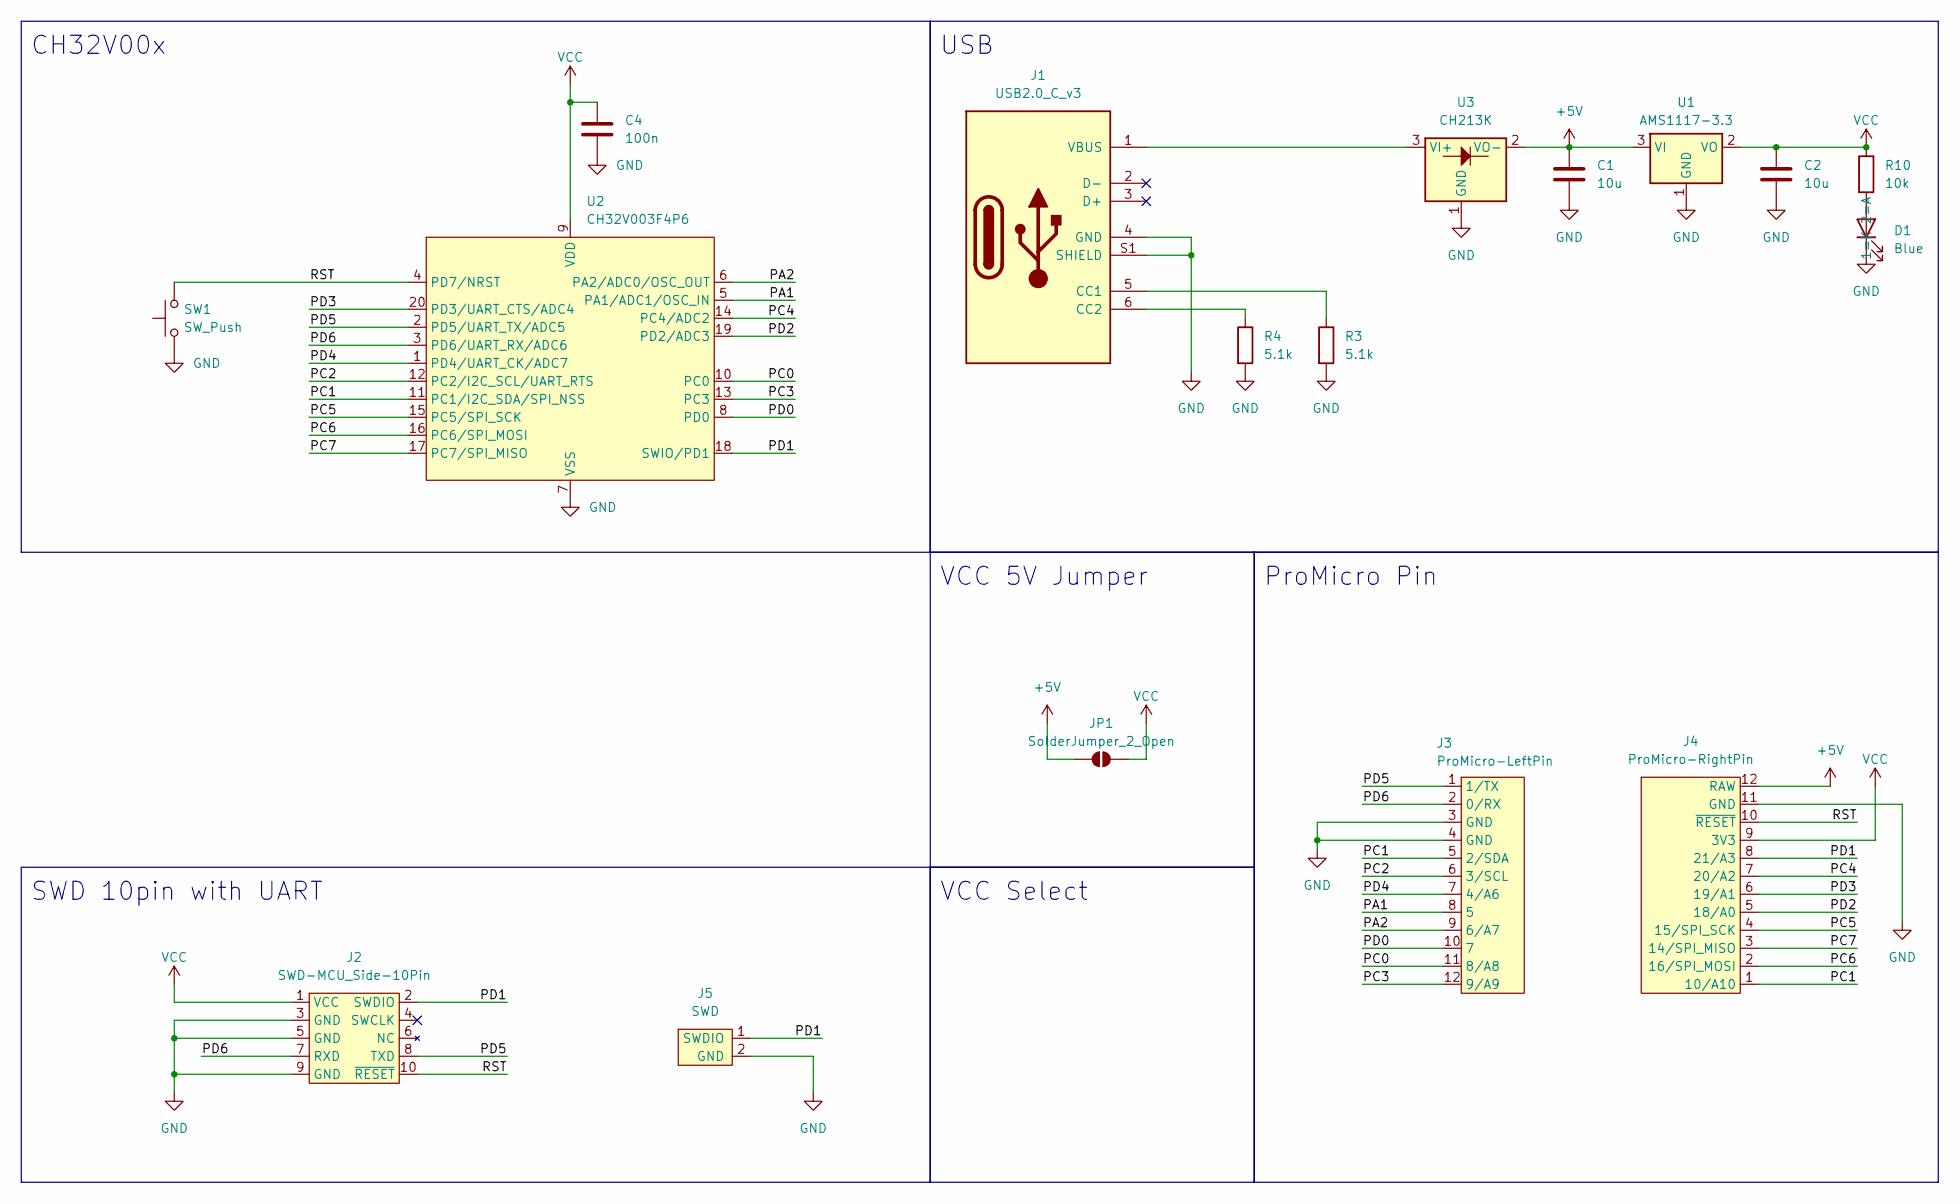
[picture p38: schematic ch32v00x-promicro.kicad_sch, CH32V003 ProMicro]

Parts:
C1, C2: 10u; Capacitor_0603_1608
C4: 100n; Capacitor_0603_1608
D1: Blue; LED_0805_2012
J1: USB2.0_C_v3; Connector_USB-C-Receptacle_SMT_12-Pin_Simple
J2: SWD-MCU_Side-10Pin; Connector_HalfPinHeader_SWD
J3: ProMicro-LeftPin; PinOut_ProMicro-LIKE_LEFT
J4: ProMicro-RightPin; PinOut_ProMicro-LIKE_RIGHT
J5: SWD; PinOut_Pin_2_2GND
JP1: SolderJumper_2_Open; SolderJumper-2
R3, R4: 5.1k; Register_0603_1608
R10: 10k; Register_0603_1608
SW1: SW_Push; Switch_SKRPABE010
U1: AMS1117-3.3; Package_SOT-89-3
U2: CH32V003F4P6; Package_TSSOP-20_4.4x6.5mm_P0.65mm
U3: CH213K; Package_SOT-23

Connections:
+5V: C1.1, J4.12 (RAW), JP1.1 (A), U1.3 (VI), U3.2 (VO-)
/PA1: J3.8 (5), U2.5 (PA1/ADC1/OSC_IN)
/PA2: J3.9 (6/A7), U2.6 (PA2/ADC0/OSC_OUT)
/PC0: J3.11 (8/A8), U2.10 (PC0)
/PC1: J3.5 (2/SDA), J4.1 (10/A10), U2.11 (PC1/I2C_SDA/SPI_NSS)
/PC2: J3.6 (3/SCL), U2.12 (PC2/I2C_SCL/UART_RTS)
/PC3: J3.12 (9/A9), U2.13 (PC3)
/PC4: J4.7 (20/A2), U2.14 (PC4/ADC2)
/PC5: J4.4 (15/SPI_SCK), U2.15 (PC5/SPI_SCK)
/PC6: J4.2 (16/SPI_MOSI), U2.16 (PC6/SPI_MOSI)
/PC7: J4.3 (14/SPI_MISO), U2.17 (PC7/SPI_MISO)
/PD0: J3.10 (7), U2.8 (PD0)
/PD1: J2.2 (SWDIO), J4.8 (21/A3), J5.1 (SWDIO), U2.18 (SWIO/PD1)
/PD2: J4.5 (18/A0), U2.19 (PD2/ADC3)
/PD3: J4.6 (19/A1), U2.20 (PD3/UART_CTS/ADC4)
/PD4: J3.7 (4/A6), U2.1 (PD4/UART_CK/ADC7)
/PD5: J2.8 (TXD), J3.1 (1/TX), U2.2 (PD5/UART_TX/ADC5)
/PD6: J2.7 (RXD), J3.2 (0/RX), U2.3 (PD6/UART_RX/ADC6)
/RST: J2.10 (~RESET), J4.10 (~RESET), SW1.2, U2.4 (PD7/NRST)
GND: C1.2, C2.2, C4.2, D1.1 (K), J1.4 (GND), J1.S1 (SHIELD), J2.3 (GND), J2.5 (GND), J2.9 (GND), J3.3 (GND), J3.4 (GND), J4.11 (GND), J5.2 (GND), R3.2, R4.2, SW1.1, U1.1 (GND), U2.7 (VSS), U3.1 (GND)
unnamed: D1.2 (A), R10.2
unnamed: J1.5 (CC1), R3.1
unnamed: J1.6 (CC2), R4.1
unnamed: J1.1 (VBUS), U3.3 (VI+)
VCC: C2.1, C4.1, J2.1 (VCC), J4.9 (3V3), JP1.2 (B), R10.1, U1.2 (VO), U2.9 (VDD)

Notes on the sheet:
VCC 5V Jumper
CH32V00x
VCC Select
ProMicro Pin
USB
SWD 10pin with UART

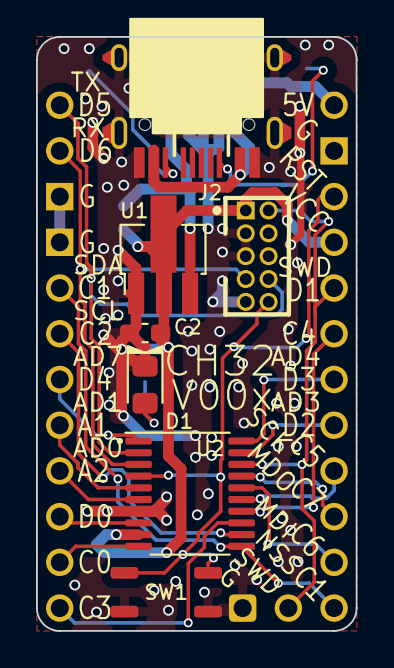
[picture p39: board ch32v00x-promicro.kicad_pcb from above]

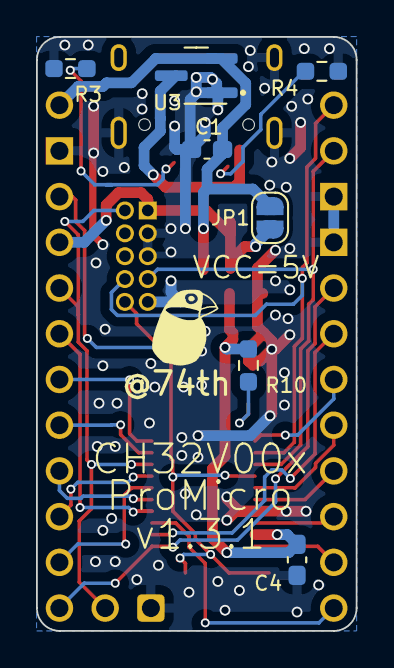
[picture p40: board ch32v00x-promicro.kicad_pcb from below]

Board: 2 copper layers, 17.8 x 33.0 mm, 19 parts (9 on the bottom side), 25 nets.

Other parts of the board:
MISC-ACCOUNTTEXT: 74th-text
MISC-ACCOUNTTEXT#2: 74th-text

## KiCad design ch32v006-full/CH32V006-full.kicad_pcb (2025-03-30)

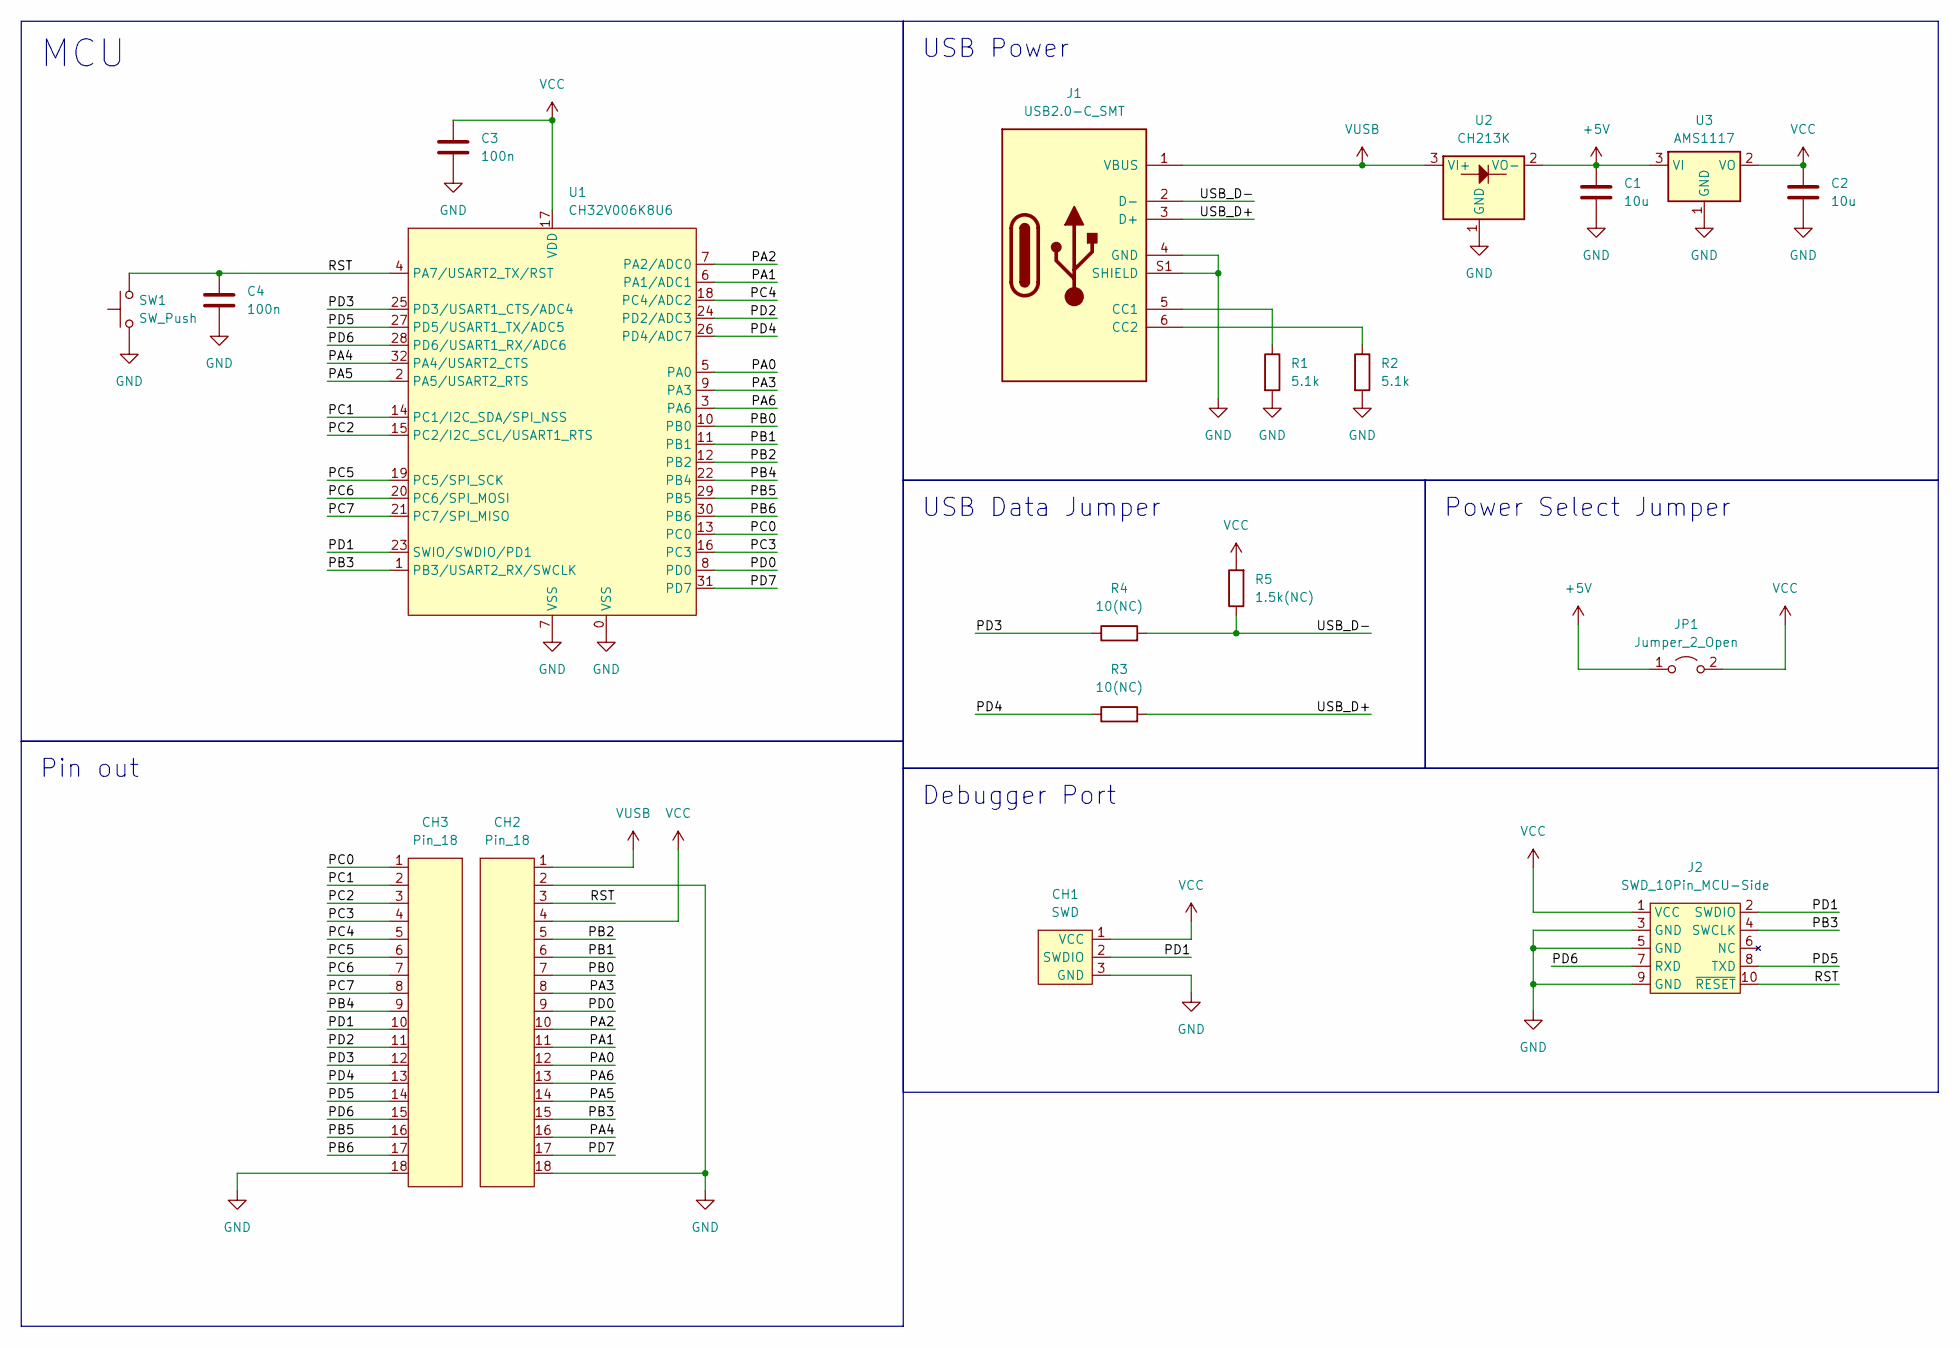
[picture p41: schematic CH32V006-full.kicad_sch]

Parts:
C1, C2: 10u; Capacitor_0603_1608
C3, C4: 100n; Capacitor_0603_1608
CH1: SWD; PinOut_Pin_3_3GND
CH2, CH3: Pin_18; PinOut_Pin_18
J1: USB2.0-C_SMT; Connector_USB-C-Receptacle_SMT_12-Pin_Simple
J2: SWD_10Pin_MCU-Side; Connector_HalfPinHeader_SWD
JP1: Jumper_2_Open; SolderJumper-2
R1, R2: 5.1k; Register_0603_1608
R3, R4: 10(NC); Register_0603_1608
R5: 1.5k(NC); Register_0603_1608
SW1: SW_Push; Switch_SKRPABE010
U1: CH32V006K8U6; Package_QFN-32-1EP_4x4mm_P0.4mm_EP2.7x2.7mm_hand
U2: CH213K; Package_SOT-23
U3: AMS1117; Package_SOT-89-3

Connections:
+5V: C1.1, JP1.1 (A), U2.2 (VO-), U3.3 (VI)
/PA0: CH2.12, U1.5 (PA0)
/PA1: CH2.11, U1.6 (PA1/ADC1)
/PA3: CH2.8, U1.9 (PA3)
/PA4: CH2.16, U1.32 (PA4/USART2_CTS)
/PA5: CH2.14, U1.2 (PA5/USART2_RTS)
/PA6: CH2.13, U1.3 (PA6)
/PB0: CH2.7, U1.10 (PB0)
/PB1: CH2.6, U1.11 (PB1)
/PB2: CH2.5, U1.12 (PB2)
/PB3: CH2.15, J2.4 (SWCLK), U1.1 (PB3/USART2_RX/SWCLK)
/PB4: CH3.9, U1.22 (PB4)
/PB5: CH3.16, U1.29 (PB5)
/PB6: CH3.17, U1.30 (PB6)
/PC0: CH3.1, U1.13 (PC0)
/PC1: CH3.2, U1.14 (PC1/I2C_SDA/SPI_NSS)
/PC2: CH3.3, U1.15 (PC2/I2C_SCL/USART1_RTS)
/PC3: CH3.4, U1.16 (PC3)
/PC4: CH3.5, U1.18 (PC4/ADC2)
/PC5: CH3.6, U1.19 (PC5/SPI_SCK)
/PC6: CH3.7, U1.20 (PC6/SPI_MOSI)
/PC7: CH3.8, U1.21 (PC7/SPI_MISO)
/PD0: CH2.9, U1.8 (PD0)
/PD1: CH1.2 (SWDIO), CH3.10, J2.2 (SWDIO), U1.23 (SWIO/SWDIO/PD1)
/PD2: CH3.11, U1.24 (PD2/ADC3)
/PD3: CH3.12, R4.1, U1.25 (PD3/USART1_CTS/ADC4)
/PD4: CH3.13, R3.1, U1.26 (PD4/ADC7)
/PD5: CH3.14, J2.8 (TXD), U1.27 (PD5/USART1_TX/ADC5)
/PD6: CH3.15, J2.7 (RXD), U1.28 (PD6/USART1_RX/ADC6)
/PD7: CH2.17, U1.31 (PD7)
/RST: C4.1, CH2.3, J2.10 (~RESET), SW1.2, U1.4 (PA7/USART2_TX/RST)
/USB_D+: J1.3 (D+), R3.2
/USB_D-: J1.2 (D-), R4.2, R5.1
unnamed: J1.5 (CC1), R1.1
unnamed: J1.6 (CC2), R2.1
VCC: C2.1, C3.1, CH1.1 (VCC), CH2.4, J2.1 (VCC), JP1.2 (B), R5.2, U1.17 (VDD), U3.2 (VO)
VUSB: CH2.1, J1.1 (VBUS), U2.3 (VI+)

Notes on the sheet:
USB Data Jumper
Power Select Jumper
Debugger Port
MCU
USB Power
Pin out

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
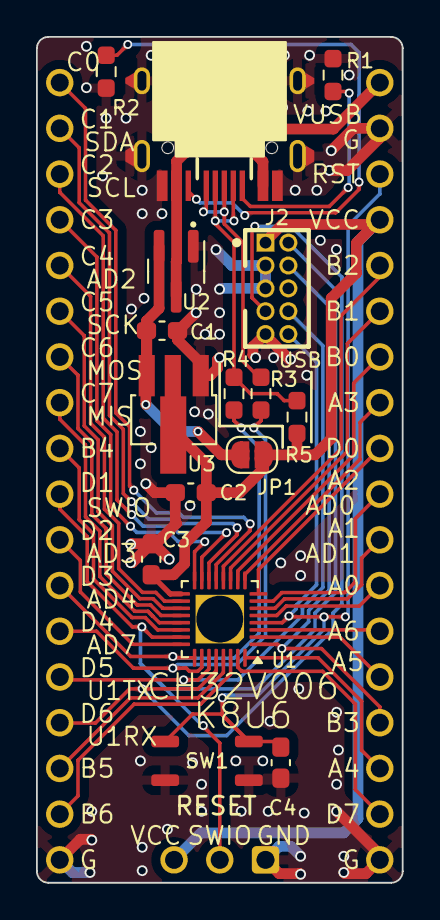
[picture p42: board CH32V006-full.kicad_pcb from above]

Board: 2 copper layers, 20.3 x 47.0 mm, 20 parts (1 on the bottom side), 39 nets.

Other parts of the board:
MISC-ICON: LOGO; Logo_74th_5mm

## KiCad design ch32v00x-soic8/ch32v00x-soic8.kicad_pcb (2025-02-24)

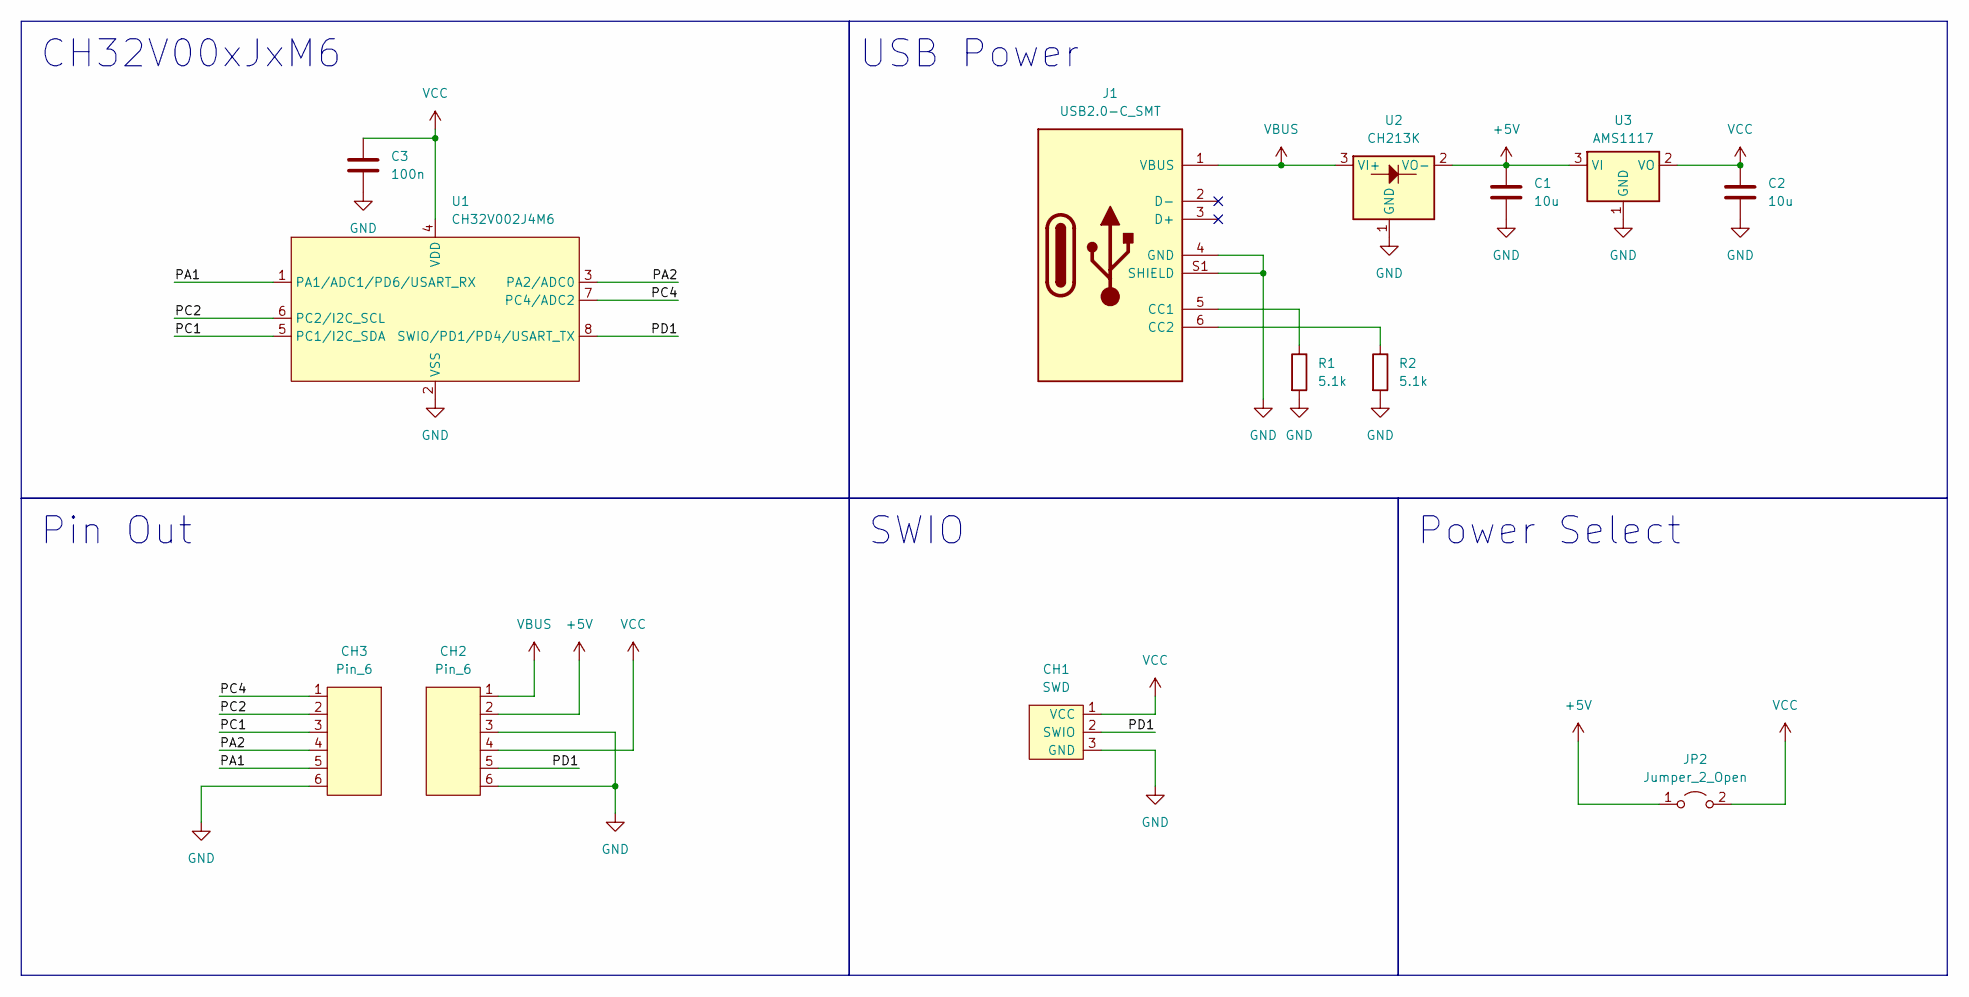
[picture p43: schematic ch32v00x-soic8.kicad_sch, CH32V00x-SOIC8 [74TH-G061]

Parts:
C1, C2: 10u; Capacitor_0603_1608
C3: 100n; Capacitor_0603_1608
CH1: SWD; PinOut_Pin_3_3GND
CH2, CH3: Pin_6; PinOut_Pin_6_GND
J1: USB2.0-C_SMT; Connector_USB-C-Receptacle_SMT_12-Pin_Simple
JP2: Jumper_2_Open; SolderJumper-2
R1, R2: 5.1k; Register_0603_1608
U1: CH32V002J4M6; Package_SOIC-8_3.9x4.9mm_P1.27mm
U2: CH213K; Package_SOT-23
U3: AMS1117; Package_SOT-89-3

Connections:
+5V: C1.1, CH2.2, JP2.1 (A), U2.2 (VO-), U3.3 (VI)
/PA1: CH3.5, U1.1 (PA1/ADC1/PD6/USART_RX)
/PA2: CH3.4, U1.3 (PA2/ADC0)
/PC1: CH3.3, U1.5 (PC1/I2C_SDA)
/PC2: CH3.2, U1.6 (PC2/I2C_SCL)
/PC4: CH3.1, U1.7 (PC4/ADC2)
/PD1: CH1.2 (SWDIO), CH2.5, U1.8 (SWIO/PD1/PD4/USART_TX)
GND: C1.2, C2.2, C3.2, CH1.3 (GND), CH2.3, CH2.6, CH3.6, J1.4 (GND), J1.S1 (SHIELD), R1.2, R2.2, U1.2 (VSS), U2.1 (GND), U3.1 (GND)
unnamed: J1.5 (CC1), R1.1
unnamed: J1.6 (CC2), R2.1
VBUS: CH2.1, J1.1 (VBUS), U2.3 (VI+)
VCC: C2.1, C3.1, CH1.1 (VCC), CH2.4, JP2.2 (B), U1.4 (VDD), U3.2 (VO)

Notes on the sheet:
USB Power
SWIO
Power Select
CH32V00xJxM6
Pin Out

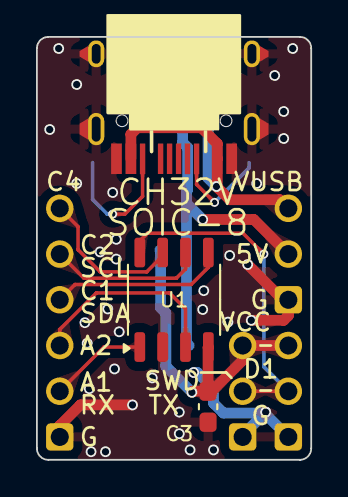
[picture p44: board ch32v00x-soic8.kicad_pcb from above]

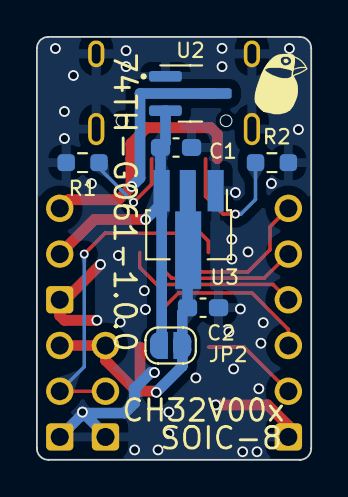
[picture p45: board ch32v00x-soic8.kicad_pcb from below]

Board: 2 copper layers, 15.2 x 23.5 mm, 14 parts (8 on the bottom side), 12 nets.

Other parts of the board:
MISC-ICON: LOGO; Logo_74th_4mm

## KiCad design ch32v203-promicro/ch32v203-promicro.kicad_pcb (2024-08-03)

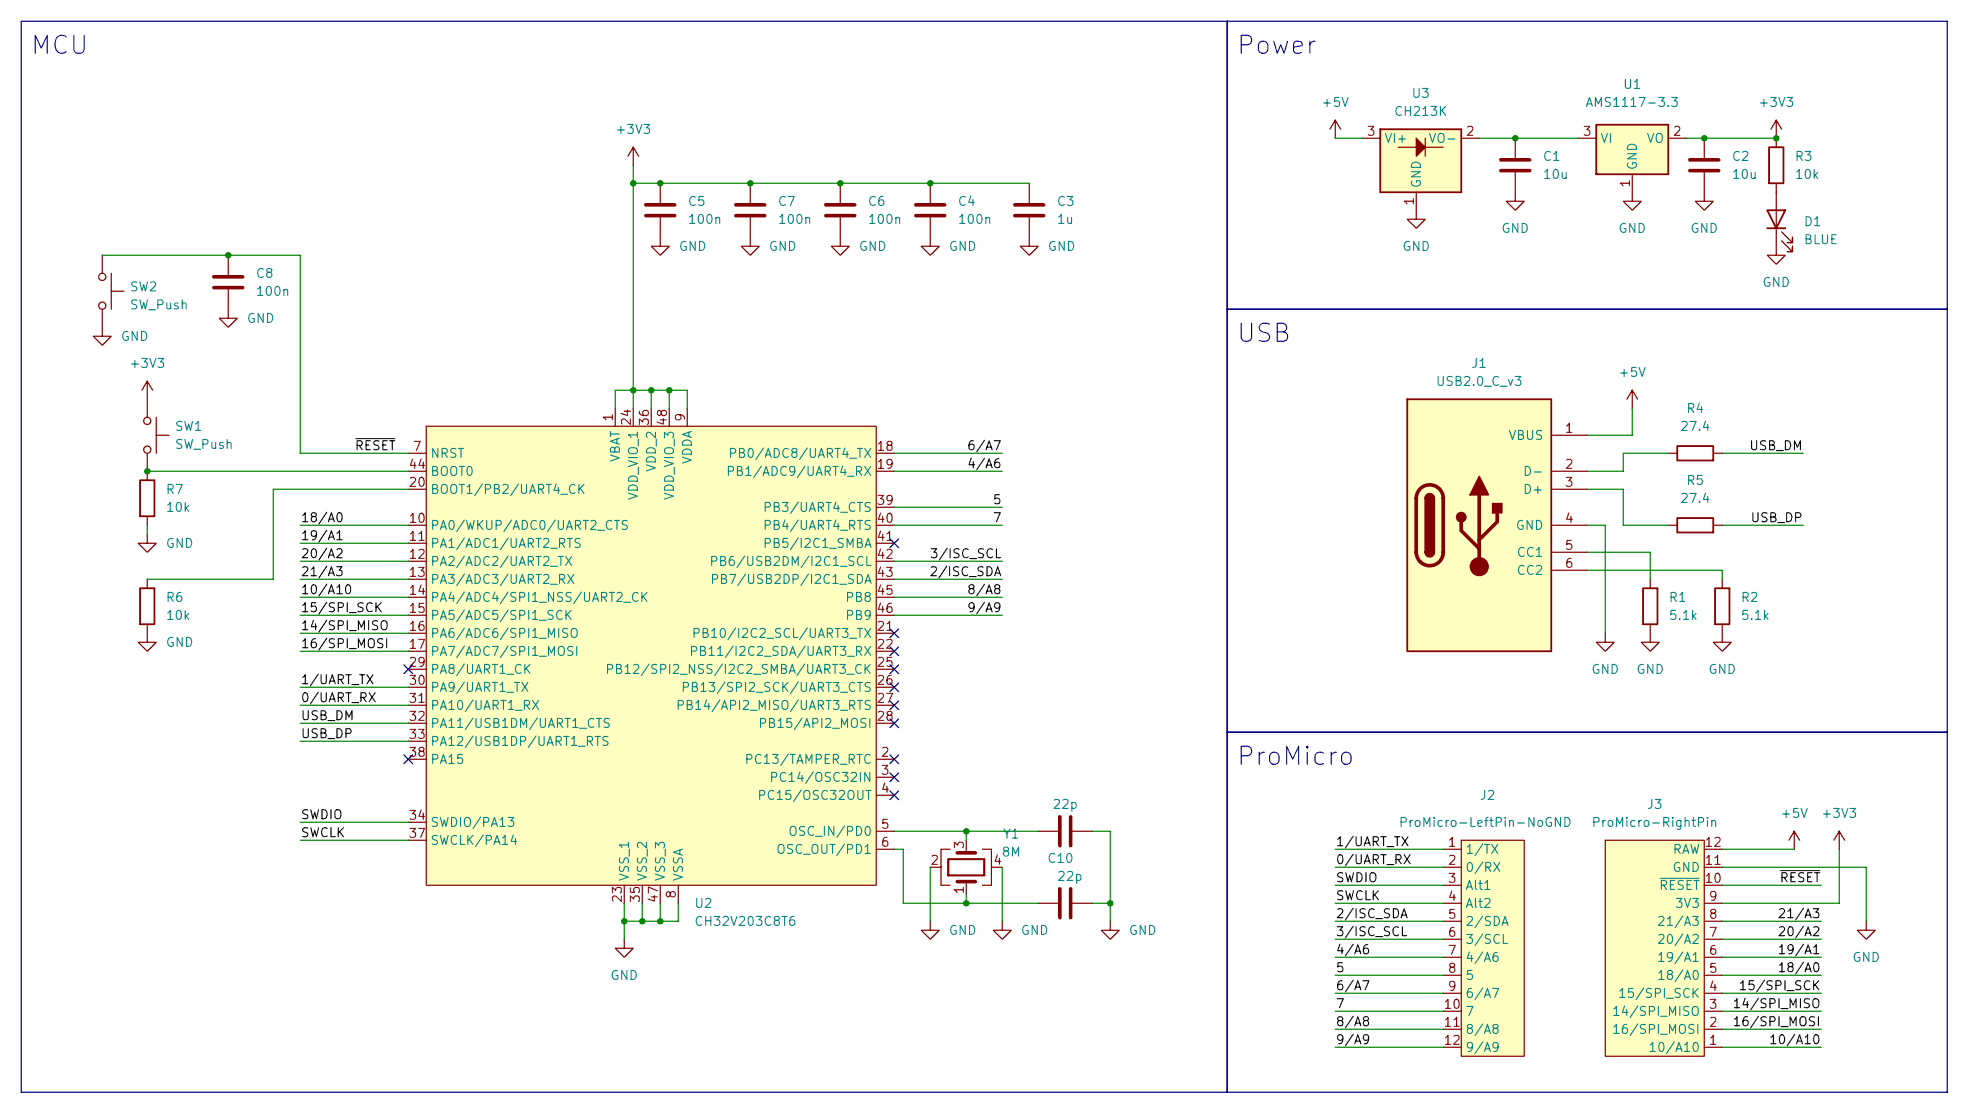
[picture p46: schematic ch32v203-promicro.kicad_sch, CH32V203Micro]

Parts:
C1, C2: 10u; Capacitor_0805_2012
C3: 1u; Capacitor_0805_2012
C4, C5, C6, C7, C8: 100n; Capacitor_0805_2012
C9, C10: 22p; Capacitor_0805_2012
D1: BLUE; LED_0805_2012
J1: USB2.0_C_v3; Connector_USB-C-Receptacle_SMT_12-Pin_Simple
J2: ProMicro-LeftPin-NoGND; PinOut_ProMicro-LIKE_LEFT_NO-GND
J3: ProMicro-RightPin; PinOut_ProMicro-LIKE_RIGHT
R1, R2: 5.1k; Register_0805_2012
R3, R6, R7: 10k; Register_0805_2012
R4, R5: 27.4; Register_0805_2012
SW1, SW2: SW_Push; Switch_SKRPABE010
U1: AMS1117-3.3; Package_SOT-89-3
U2: CH32V203C8T6; Package_LQFP-48_7x7mm_P0.5mm
U3: CH213K; Package_SOT-23
Y1: 8M; Crystal_SMD_3225-4Pin_3.2x2.5mm_HandSoldering

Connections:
+3V3: C2.1, C3.1, C4.1, C5.1, C6.1, C7.1, J3.9 (3V3), R3.1, SW1.1, U1.2 (VO), U2.1 (VBAT), U2.9 (VDDA), U2.24 (VDD_VIO_1), U2.36 (VDD_2), U2.48 (VDD_VIO_3)
+5V: J1.1 (VBUS), J3.12 (RAW), U3.3 (VI+)
/0/UART_RX: J2.2 (0/RX), U2.31 (PA10/UART1_RX)
/1/UART_TX: J2.1 (1/TX), U2.30 (PA9/UART1_TX)
/2/ISC_SDA: J2.5 (2/SDA), U2.43 (PB7/USB2DP/I2C1_SDA)
/3/ISC_SCL: J2.6 (3/SCL), U2.42 (PB6/USB2DM/I2C1_SCL)
/4/A6: J2.7 (4/A6), U2.19 (PB1/ADC9/UART4_RX)
/5: J2.8 (5), U2.39 (PB3/UART4_CTS)
/6/A7: J2.9 (6/A7), U2.18 (PB0/ADC8/UART4_TX)
/7: J2.10 (7), U2.40 (PB4/UART4_RTS)
/8/A8: J2.11 (8/A8), U2.45 (PB8)
/9/A9: J2.12 (9/A9), U2.46 (PB9)
/10/A10: J3.1 (10/A10), U2.14 (PA4/ADC4/SPI1_NSS/UART2_CK)
/14/SPI_MISO: J3.3 (14/SPI_MISO), U2.16 (PA6/ADC6/SPI1_MISO)
/15/SPI_SCK: J3.4 (15/SPI_SCK), U2.15 (PA5/ADC5/SPI1_SCK)
/16/SPI_MOSI: J3.2 (16/SPI_MOSI), U2.17 (PA7/ADC7/SPI1_MOSI)
/18/A0: J3.5 (18/A0), U2.10 (PA0/WKUP/ADC0/UART2_CTS)
/19/A1: J3.6 (19/A1), U2.11 (PA1/ADC1/UART2_RTS)
/20/A2: J3.7 (20/A2), U2.12 (PA2/ADC2/UART2_TX)
/21/A3: J3.8 (21/A3), U2.13 (PA3/ADC3/UART2_RX)
/SWCLK: J2.4 (Alt2), U2.37 (SWCLK/PA14)
/SWDIO: J2.3 (Alt1), U2.34 (SWDIO/PA13)
/USB_DM: R4.2, U2.32 (PA11/USB1DM/UART1_CTS)
/USB_DP: R5.2, U2.33 (PA12/USB1DP/UART1_RTS)
/~RESET: C8.1, J3.10 (~RESET), SW2.1, U2.7 (NRST)
GND: C1.2, C2.2, C3.2, C4.2, C5.2, C6.2, C7.2, C8.2, C9.2, C10.2, D1.1 (K), J1.4 (GND), J3.11 (GND), R1.2, R2.2, R6.2, R7.2, SW2.2, U1.1 (GND), U2.8 (VSSA), U2.23 (VSS_1), U2.35 (VSS_2), U2.47 (VSS_3), U3.1 (GND), Y1.2, Y1.4
unnamed: D1.2 (A), R3.2
unnamed: J1.5 (CC1), R1.1
unnamed: J1.6 (CC2), R2.1
unnamed: J1.3 (D+), R5.1
unnamed: J1.2 (D-), R4.1
unnamed: C1.1, U1.3 (VI), U3.2 (VO-)
unnamed: R7.1, SW1.2, U2.44 (BOOT0)
unnamed: R6.1, U2.20 (BOOT1/PB2/UART4_CK)
unnamed: C9.1, U2.5 (OSC_IN/PD0), Y1.3
unnamed: C10.1, U2.6 (OSC_OUT/PD1), Y1.1

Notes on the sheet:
USB
ProMicro
MCU
Power



Board: 2 copper layers, 17.8 x 33.0 mm, 28 parts (19 on the bottom side), 36 nets.

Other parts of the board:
MISC-ICON: LOGO; 74th-4mm

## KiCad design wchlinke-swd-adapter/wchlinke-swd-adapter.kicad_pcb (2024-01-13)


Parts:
J1: SWD_10Pin_Debugger-Side; Connector_BoxPinHeader_2x05_P1.27mm
U1: SWD_WCH-LinkE_Header; PinOut_Side_2x5P_Left_Reverse

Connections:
+3.3V: J1.1 (VCC), U1.8 (3V3)
/RXD: J1.8 (RXD), U1.1 (RX)
/SWCLK: J1.4 (SWCLK), U1.2 (SWCLK)
/SWDIO: J1.2 (SWDIO), U1.4 (SWDIO)
/TXD: J1.7 (TXD), U1.3 (TX)
/~RESET: J1.10 (~RESET), U1.9 (RST)
GND: J1.3 (GND), J1.5 (GND), J1.9 (GND), U1.6 (GND)


Board: 2 copper layers, 16.5 x 14.0 mm, 3 parts (1 on the bottom side), 7 nets.

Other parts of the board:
MISC-ICON: LOGO; Logo_74th_4mm

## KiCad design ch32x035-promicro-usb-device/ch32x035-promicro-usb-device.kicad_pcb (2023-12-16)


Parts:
C1, C2: 10u; Capacitor_0603_1608
C3: 1u; Capacitor_0603_1608
C4: 100n; Capacitor_0603_1608
CH1: ProMicro-Left_NoGND; PinOut_ProMicro-LIKE_LEFT_NO-GND
CH2: ProMicro-Right; PinOut_ProMicro-LIKE_RIGHT
CH3: 3Pin; PinOut_3Pin
CH4: 2Pin; PinOut_2Pin
D1: BLUE; LED_0805_2012
J1: 217179-0001; Connector_USB-C-Receptacle_SMT_12-Pin_Simple
J2: SWD_10Pin_MCU-Side; Connector_HalfPinHeader_SWD
JP1: Jumper_2_Open; SolderJumper-2_P1.3mm_Open_RoundedPad1.0x1.5mm
R1, R2: 5.1k; Register_0603_1608
R3: 56k; Register_0603_1608
R4: 1.5k; Register_0603_1608
R5, R8: 10k; Register_0603_1608
R6, R7: 27; Register_0603_1608
SW1: SKRPABE010; PushButton_SKRPABE010
U1: AMS1117-3.3; SOT-89-3
U2: CH32X035G8U6; Package_QFN-28-1EP_4x4mm_P0.4mm_EP2.8x2.8mm
U3: CH217K; SOT-23-6

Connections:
+5V: C1.1, JP1.1 (A), U1.3 (VI), U3.1 (VOUT)
/0/RX: CH1.2 (0/RX), J2.7 (RXD), U2.22 (PB11/T1C3/RX1)
/1/TX: CH1.1 (1/TX), J2.8 (TXD), U2.21 (PB10/TX1/T1C2)
/2/SDA: CH1.5 (2/SDA), U2.28 (PC14/CC1)
/3/SCL: CH1.6 (3/SCL), U2.1 (PC15/CC2)
/4/A6: CH1.7 (4/A6), U2.5 (PA0/T2C1/CTS2/C1P1/A0)
/5: CH1.8 (5), U2.6 (PA1/RTS2/T2C2/C10/O1N2/O2N2/A1)
/6/A7: CH1.9 (6/A7), U2.7 (PA2/TX2/T2C3/O2O1/C3N0/A2)
/7: CH1.10 (7), U2.8 (PA3/RX2/T2C4/O1O0/A3)
/8/A8: CH1.11 (8/A8), U2.9 (PA4/CS/CK2/O2O0/A4)
/9/A9: CH1.12 (9/A9), U2.13 (PB0/TX4/O1P0/A8)
/10/A10: CH2.1 (10/A10), U2.16 (PB1/RX4/O2N1/A9/PB5/CK3/O1O1/T1BK)
/14/SPI_MISO: CH2.3 (14/SPI_MISO), U2.11 (PA6/MISO/T3C1/O1N0/A6)
/15/SPI_SCK: CH2.4 (15/SPI_SCK), U2.10 (PA5/SCK/O2N0/A5)
/16/SPI_MOSI: CH2.2 (16/SPI_MOSI), U2.12 (PA7/MOSI/T3C2/O2P0/A7)
/18/A0: CH2.5 (18/A0), U2.18 (PB7/T1C2N/O2P2/RTS3)
/19/A1: CH2.6 (19/A1), U2.19 (PB8/T1C3N/O1P1)
/20/A2: CH2.7 (20/A2), U2.20 (PB9/CK1/T1C1/MCO)
/21/A3: CH2.8 (21/A3), U2.23 (PB12)
/OG1: CH3.1, U2.17 (PB6/T1C1N/CTS3/O1N1)
/OG2: CH3.2, U2.15 (PB4/RX3/O1P2)
/OG3: CH3.3, U2.14 (PB3/TX3/C3O/O2P1)
/OG4: CH4.1, U2.3 (PC0/A10)
/OG5: CH4.2, U2.4 (PC3/C1N0/C2N1/C3N1/A13)
/RST: CH2.10 (~RESET), R8.1, SW1.2, U3.4 (EN#)
/SWCLK: CH1.4 (Alt2), J2.4 (SWCLK), U2.24 (PC19/SWCLK)
/SWDIO: CH1.3 (Alt1), J2.2 (SWDIO), U2.25 (PC18/SWDIO)
/USB_DM: R6.1, U2.26 (PC16/UDM)
/USB_DP: R7.1, U2.27 (PC17/UDP)
GND: C1.2, C2.2, C3.2, C4.2, CH2.11 (GND), D1.1 (K), J1.4 (GND), J2.3 (GND), J2.5 (GND), J2.9 (GND), R1.2, R2.2, R3.2, R8.2, U1.1 (GND), U2.0 (GND), U3.2 (GND)
unnamed: D1.2 (A), R5.2
unnamed: J1.5 (CC1), R1.1
unnamed: J1.6 (CC2), R2.1
unnamed: J1.3 (D+), R4.1, R7.2
unnamed: J1.2 (D-), R6.2
unnamed: R3.1, U3.5 (ISET)
VBUS: CH2.12 (RAW), J1.1 (VBUS), SW1.1, U3.6 (VIN)
VDD: C2.1, C3.1, C4.1, CH2.9 (3V3), J2.1 (VCC), JP1.2 (B), R4.2, R5.1, U1.2 (VO), U2.2 (VDD)

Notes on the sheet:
MCU
USB
Power
Interface
SWD



Board: 2 copper layers, 17.8 x 31.8 mm, 26 parts (14 on the bottom side), 38 nets.

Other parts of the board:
MISC-ACCOUNTTEXT: Logo_74th_text
MISC-ICON: LOGO; Logo_74th_4mm

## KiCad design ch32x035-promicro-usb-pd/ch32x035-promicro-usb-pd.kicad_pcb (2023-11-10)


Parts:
C1, C5: 10u; Capacitor_0805_2012
C9: 1u; Capacitor_0805_2012
C10: 100n; Capacitor_0805_2012
CH1: ProMicro-Right; PinOut_ProMicro-LIKE_RIGHT
CH2: ProMicro-Left_NoGND; PinOut_ProMicro-LIKE_LEFT_NO-GND
CH3: 3Pin; PinOut_3Pin
D1: BLUE; LED_0805_2012
J1: USB_TypeC-2.0_Receptacle; Connector_USB-C-Receptacle_SMT_12-Pin_Simple
R1, R2: 5.1k; Register_0805_2012
R3, R4: 27; Register_0805_2012
R5: 10k; Register_0805_2012
U1: CH32X035G8U6; Package_QFN-28-1EP_4x4mm_P0.4mm_EP2.8x2.8mm
U2: AMS1117; SOT-89-3
U3: CH213K; SOT-23

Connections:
+3.3V: CH1.9 (3V3), U2.2 (VO), U3.3 (VI+)
/0/RX: CH2.2 (0/RX), U1.22 (PB11/T1C3/RX1)
/1/TX: CH2.1 (1/TX), U1.21 (PB10/TX1/T1C2)
/2/SDA: CH2.5 (2/SDA), U1.3 (PC0/A10)
/3/SCL: CH2.6 (3/SCL), U1.4 (PC3/C1N0/C2N1/C3N1/A13)
/4/A6: CH2.7 (4/A6), U1.5 (PA0/T2C1/CTS2/C1P1/A0)
/5: CH2.8 (5), U1.6 (PA1/RTS2/T2C2/C10/O1N2/O2N2/A1)
/6/A7: CH2.9 (6/A7), U1.7 (PA2/TX2/T2C3/O2O1/C3N0/A2)
/7: CH2.10 (7), U1.8 (PA3/RX2/T2C4/O1O0/A3)
/8/A8: CH2.11 (8/A8), U1.10 (PA5/SCK/O2N0/A5)
/9/A9: CH2.12 (9/A9), U1.12 (PA7/MOSI/T3C2/O2P0/A7)
/10/A10: CH1.1 (10/A10), U1.14 (PB3/TX3/C3O/O2P1)
/14/SPI_MISO: CH1.3 (14/SPI_MISO), U1.18 (PB7/T1C2N/O2P2/RTS3)
/15/SPI_SCK: CH1.4 (15/SPI_SCK), U1.19 (PB8/T1C3N/O1P1)
/16/SPI_MOSI: CH1.2 (16/SPI_MOSI), U1.16 (PB1/RX4/O2N1/A9/PB5/CK3/O1O1/T1BK)
/18/A0: CH1.5 (18/A0), U1.20 (PB9/CK1/T1C1/MCO)
/19/A1: CH1.6 (19/A1), U1.23 (PB12)
/20/A2: CH1.7 (20/A2), U1.17 (PB6/T1C1N/CTS3/O1N1)
/21/A3: CH1.8 (21/A3), U1.15 (PB4/RX3/O1P2)
/G0: CH3.1, U1.9 (PA4/CS/CK2/O2O0/A4)
/G1: CH3.2, U1.11 (PA6/MISO/T3C1/O1N0/A6)
/G2: CH3.3, U1.13 (PB0/TX4/O1P0/A8)
/SWCLK: CH2.4 (Alt2), U1.24 (PC19/SWCLK)
/SWDIO: CH2.3 (Alt1), U1.25 (PC18/SWDIO)
/USB_CC1: J1.5 (CC1), R1.1, U1.28 (PC14/CC1)
/USB_CC2: J1.6 (CC2), R2.1, U1.1 (PC15/CC2)
/USB_DM: R3.1, U1.26 (PC16/UDM)
/USB_DP: R4.1, U1.27 (PC17/UDP)
GND: C1.2, C5.2, C9.2, C10.2, CH1.10 (~RESET), CH1.11 (GND), J1.4 (GND), R1.2, R2.2, R5.2, U1.0 (GND), U2.1 (GND), U3.1 (GND)
unnamed: D1.1 (K), R5.1
unnamed: J1.3 (D+), R4.2
unnamed: J1.2 (D-), R3.2
VBUS: C1.1, CH1.12 (RAW), J1.1 (VBUS), U2.3 (VI)
VDD: C5.1, C9.1, C10.1, D1.2 (A), U1.2 (VDD), U3.2 (VO-)

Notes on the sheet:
MCU
USB
Power
Interface



Board: 2 copper layers, 17.8 x 31.8 mm, 19 parts (7 on the bottom side), 34 nets.

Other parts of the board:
MISC-ACCOUNTTEXT: Logo_74th_text
MISC-ICON: LOGO; Logo_74th_5mm

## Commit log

2022-12-24 add symbols
    [ch32v203-promicro.kicad_pcb, ch32v203-promicro.kicad_sch]
2022-12-25 ch32v203 promicro
    [ch32v203-promicro.kicad_pcb, ch32v203-promicro.kicad_sch]
2022-12-26 ch32v203micro v1.0.0
    [ch32v203-promicro.kicad_pcb, ch32v203-promicro.kicad_sch]
2022-12-26 ch32v001 mincro
    [ch32v003-promicro.kicad_pcb, ch32v003-promicro.kicad_sch, ch32v203-promicro.kicad_pcb]
2022-12-27 ch32v003micro v1.0.0
    [ch32v003-promicro.kicad_pcb]
2023-01-28 x32micro v1.1.0
    [ch32v203-promicro.kicad_pcb, ch32v203-promicro.kicad_sch]
2023-09-18 add ch32x035
    [ch32x035-promicro.kicad_pcb, ch32x035-promicro.kicad_sch]
2023-09-27 ch32v203 promicro v1.2.1
    [ch32v203-promicro.csv, ch32v203-promicro.kicad_pcb, ch32v203-promicro.kicad_sch]
2023-10-17 fix SWDIO/SWCLK
    [ch32x035-promicro-usb-device.kicad_pcb, ch32x035-promicro-usb-device.kicad_sch]
2024-01-04 ファイル移動
2024-01-13 WCH LinkE SWD Adapter
    [wchlinke-swd-adapter.kicad_pcb, wchlinke-swd-adapter.kicad_sch]
2024-08-02 update kicad version
    [ch32v203-promicro.kicad_pcb, ch32v203-promicro.kicad_sch]
2025-03-30 fix silk
    [ch32v003-promicro.kicad_pcb, ch32v003-promicro.kicad_sch]
2025-03-30 Add color specifications to PCB layers and update README with images
    [CH32V006-full.kicad_pcb]
2025-05-24 revert to ch32v003 v1.2.0
    [ch32v003-promicro.kicad_pcb, ch32v003-promicro.kicad_sch]
2025-08-10 it works
    [rvswdio-programer.kicad_sch]
2025-08-10 spell misstake
    [rvswdio-programmer.kicad_pcb, rvswdio-programmer.kicad_sch]
